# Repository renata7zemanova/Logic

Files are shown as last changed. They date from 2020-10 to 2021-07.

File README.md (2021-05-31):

# Elektronická hra Logic

Elektronická hra Logic je hra, která je založena na principu deskové hry Logic.

## DPS

Deska plošného spoje je nakreslena v programu KiCad. 

## Software

Pro programování DPS Elektronické hry Logic je zapotřebí stáhnout a nainstalovat vývojové prostředí [Visual Studio Code](https://code.visualstudio.com/) a v něm rozšíření PlatformIO. 

Software je napsán pomocí Arduino frameworku.

Při programování musí být přepínač SW15 vždy dole (v pozici 1).

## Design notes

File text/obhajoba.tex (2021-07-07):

% Soubory musí být v kódování, které je nastaveno v příkazu \usepackage[...]{inputenc}

\documentclass[%        Základní nastavení
  %draft,    				  % Testovací překlad
  12pt,       				% Velikost základního písma je 12 bodů
	t,                  % obsah slajdů bude vždy začínat od shora (nebude vertikálně centrovaný)
	aspectratio=1610,   % poměr stran bude 16:10 (všechny projektory v učebnách na Technické 12 Brno),
	                    % další volby jsou 43, 149, 169, 54, 32.
	unicode,						% Záložky a informace budou v kódování unicode
]{beamer}				    	% Dokument třídy 'zpráva', vhodná pro sazbu závěrečných prací s kapitolami
%\usepackage{etex}

\usepackage[utf8]		  % Kódování zdrojových souborů je v UTF-8
	{inputenc}					% Balíček pro nastavení kódování zdrojových souborů
	
\usepackage{graphicx} % Balíček 'graphicx' pro vkládání obrázků
											% Nutné pro vložení logotypů školy a fakulty

\usepackage[          % Balíček 'acronym' pro sazby zkratek a symbolů
	nohyperlinks				% Nebudou tvořeny hypertextové odkazy do seznamu zkratek
]{acronym}						
											% Nutné pro použití prostředí 'acronym' balíčku 'thesis'

%% Balíček hyperref je volán třídou beamer automaticky, proto není třeba následujícího kódu:
%\usepackage[
%	breaklinks=true,		% Hypertextové odkazy mohou obsahovat zalomení řádku
%	hypertexnames=false % Názvy hypertextových odkazů budou tvořeny
%											% nezávisle na názvech TeXu
%]{hyperref}						% Balíček 'hyperref' pro sazbu hypertextových odkazů
%											% Nutné pro použití příkazu 'nastavenipdf' balíčku 'thesis'

\usepackage{cmap} 		% Balíček cmap zajišťuje, že PDF vytvořené `pdflatexem' je
											% plně "prohledávatelné" a "kopírovatelné"

%\usepackage{upgreek}	% Balíček pro sazbu stojatých řeckých písmem
											%% např. stojaté pí: \uppi
											%% např. stojaté mí: \upmu (použitelné třeba v mikrometrech)
											%% pozor, grafická nekompatibilita s fonty typu Computer Modern!

%\usepackage{amsmath} %balíček pro sabu náročnější matematiky

\usepackage{booktabs} % Balíček, který umožňuje v tabulce používat
                      % příkazy \toprule, \midrule, \bottomrule

%%%%%%%%%%%%%%%%%%%%%%%%%%%%%%%%%%%%%%%%%%%%%%%%%%%%%%%%%%%%%%%%%
%%%%%%      Definice informací o dokumentu             %%%%%%%%%%
%%%%%%%%%%%%%%%%%%%%%%%%%%%%%%%%%%%%%%%%%%%%%%%%%%%%%%%%%%%%%%%%%

\input{nastaveni}      % v tomto souboru doplňte údaje o sobě, o názvu práce...
                       % (tento soubor je sdílený s textem práce)

%%%%%%%%%%%%%%%%%%%%%%%%%%%%%%%%%%%%%%%%%%%%%%%%%%%%%%%%%%%%%%%%%%%%%%%%

%%%%%%%%%%%%%%%%%%%%%%%%%%%%%%%%%%%%%%%%%%%%%%%%%%%%%%%%%%%%%%%%%%%%%%%%
%%%%%%     Nastavení polí ve Vlastnostech dokumentu PDF      %%%%%%%%%%%
%%%%%%%%%%%%%%%%%%%%%%%%%%%%%%%%%%%%%%%%%%%%%%%%%%%%%%%%%%%%%%%%%%%%%%%%
%% Při vloženém balíčku 'hyperref' lze použít příkaz '\pdfsettings'
\pdfsettings
%  Nastavení polí je možné provést také ručně příkazem:
%\hypersetup{
%  pdftitle={Název studentské práce},    	% Pole 'Document Title'
%  pdfauthor={Autor studenstké práce},   	% Pole 'Author'
%  pdfsubject={Typ práce}, 						  	% Pole 'Subject'
%  pdfkeywords={Klíčová slova}           	% Pole 'Keywords'
%}
\hypersetup{pdfpagemode=FullScreen}       % otevření rovnou v režimu celé obrazovky
%%%%%%%%%%%%%%%%%%%%%%%%%%%%%%%%%%%%%%%%%%%%%%%%%%%%%%%%%%%%%%%%%%%%%%%

\usetheme{VUT} 				% barvy a rozložení prezentace odpovídající VUT FEKT
% alternativně lze použít jiná berevná témata, ale bez záruky. Například: 
%\usetheme{Darmstadt} \usecolortheme{default2}
\logoheader					% vytvoření zkráceného loga VUT FEKT v hlavičce slajdu, nechte odkomentované

\begin{document}

% v případě zakomentování následujícího se zobrazí v pravém dolním rohu slajdů klikatelné navigační symboly 
\disablenavigationsymbols

% titulní snímek, vysazen bez horních, dolních a postranních lišt (volba plain),
% není tak vysazen ani nadpis snímku
\maketitle

%%%%%%%%%%%%%%%%%%%%%%%%%%%%%%%%%%%%%%%%%%%%%%%%%%%%%%%%%%%%%%%%%%%%%%%
% 1. snímek s cíli (zadaním) práce
\begin{frame} 
	% nadpis snímku
	\frametitle{Cíle práce}
	\vspace{1cm}
	\begin{itemize}
			\item Nastudování pravidel
			\item Návrh
			\item Výroba
			\item Oživení
			\item Software
			\item Ovládání hry
			\item Krabička
	\end{itemize}
\end{frame}

%%%%%%%%%%%%%
\begin{frame} 
	\frametitle{Pravidla}
	\begin{columns}[T] 								% prostředí sloupce s umístěním nahoře
		\begin{column}{0.5\textwidth}		% první sloupec
			\vspace{0.5cm}
			\begin{itemize}
				\item Respektování pravidel deskové hry
				\item Zadání kombinace barev v určitém pořadí
				\item Vyhodnocení
				\begin{itemize}
					\item Správná barva na správné pozici
					\item Správná barva na špatné pozici
				\end{itemize}
				\item 10 pokusů
			\end{itemize}
		\end{column}
		%
		\begin{column}{0.5\textwidth}		% druhý sloupec
			\begin{figure}%	
				\centering
				\vspace{0.5cm}	              % horizontální mezera
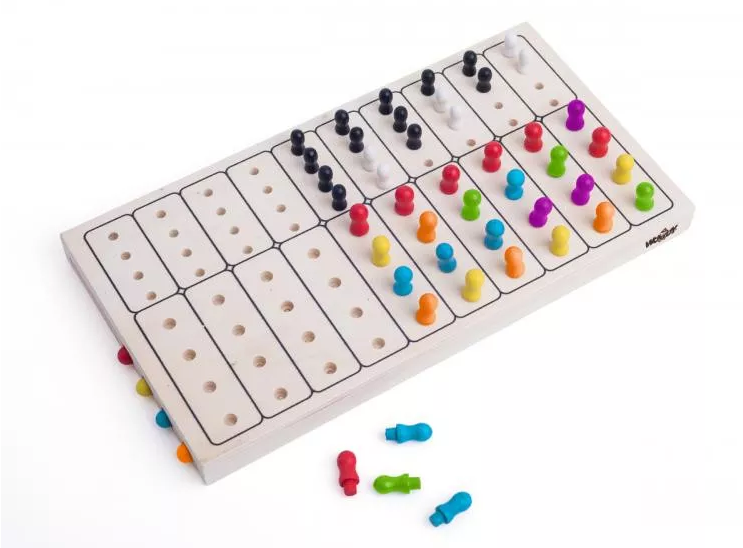
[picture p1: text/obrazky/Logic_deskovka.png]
				
				%lze vložit popisek, ale povetšinou je to v prezentaci zbytečné
				%\caption{Popisek obrázku}%
				%\label{obr:ukazka}
			\end{figure}
		\end{column}
	\end{columns}	
\end{frame} 

	% prostředí 'alertblock', které slouží pro zdůraznění informace
	%\begin{alertblock}{Pro práci je klíčový Eulerův vzorec}
	%	$$\eul^{\jmag x}=\cos x + \jmag\sin x$$
	%\end{alertblock}

	%\vspace{4ex}
	%Eulerova identita je speciálním případem tohoto vzorce, jestliže dosadíme $x=\uppi$\,:

	% prostředí 'block', které slouží jako informativní
	%\begin{block}{Eulerova identita}
	%	$$\eul^{\jmag \uppi}=\cos \uppi + \jmag\sin \uppi,$$\\
	%	odkud vyplývá
	%	$$\eul^{\jmag \uppi}+1=0.$$
	%\end{block}
%%%%%%%%%%%%%
\begin{frame} 
	\frametitle{Návrh elektroniky}
	
	\begin{columns}[T] 								% prostředí sloupce s umístěním nahoře
		\begin{column}{0.45\textwidth}		% první sloupec
			\vspace{0.5cm}
			\begin{itemize}
				\item Přenosné zařízení
				\item Řídicí elektronika
				\item Napájení
				\item Měnič napětí
				\item Převodník z USB na RS-232
				\item Herní prvky
				\item Ovládací prvky
			\end{itemize}
		\end{column}
		%
		\begin{column}{0.55\textwidth}		% druhý sloupec
			\begin{figure}%	
				\centering
				\vspace{1cm}	              % horizontální mezera
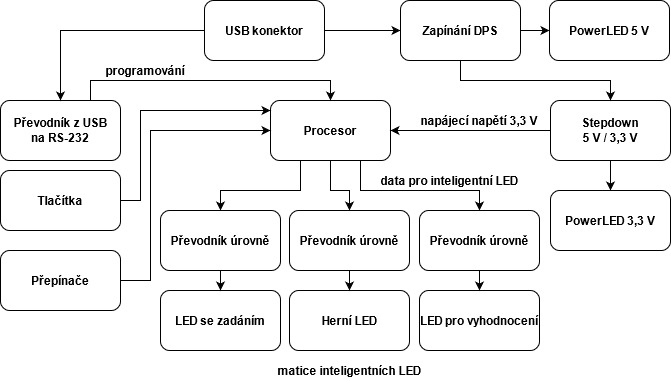
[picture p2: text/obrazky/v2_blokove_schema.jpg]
				
				%lze vložit popisek, ale povetšinou je to v prezentaci zbytečné
				%\caption{Popisek obrázku}%
				%\label{obr:ukazka}
			\end{figure}
		\end{column}
	\end{columns}											% ukončení prostředí sloupce
\end{frame}

\begin{frame} 
	\frametitle{Herní prvky}
	\begin{columns}[T] 								% prostředí sloupce s umístěním nahoře
		\begin{column}{0.4\textwidth}		% první sloupec
			%Obrázek znázorňuje model:\\[2ex]
			\vspace{0.5cm}
			\begin{itemize}
				\item WS2812C
				\item RGB
				\item Napájení
				\item Princip spojení
				\item Komunikace
			\end{itemize}
		\end{column}
		%
		\begin{column}{0.7\textwidth}		% druhý sloupec
			\begin{figure}%	
				\centering
				%\vspace{0.5cm}	              % horizontální mezera
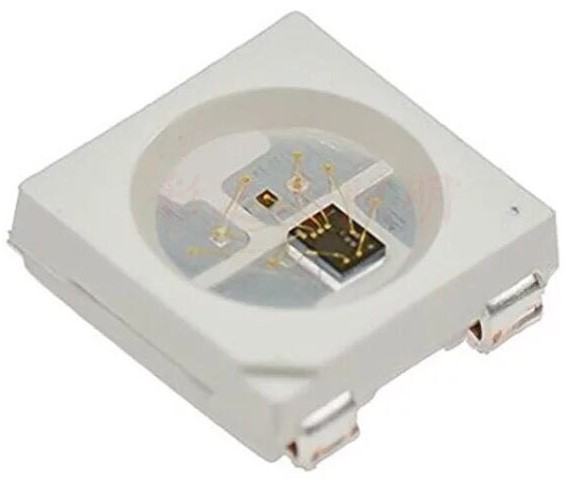
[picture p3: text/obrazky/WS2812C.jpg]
				
				%lze vložit popisek, ale povetšinou je to v prezentaci zbytečné
				%\caption{Popisek obrázku}%
				%\label{obr:ukazka}
			\end{figure}
		\end{column}
	\end{columns}	
	
	\begin{figure}%	
		\centering
		\vspace{0.5cm}	              % horizontální mezera
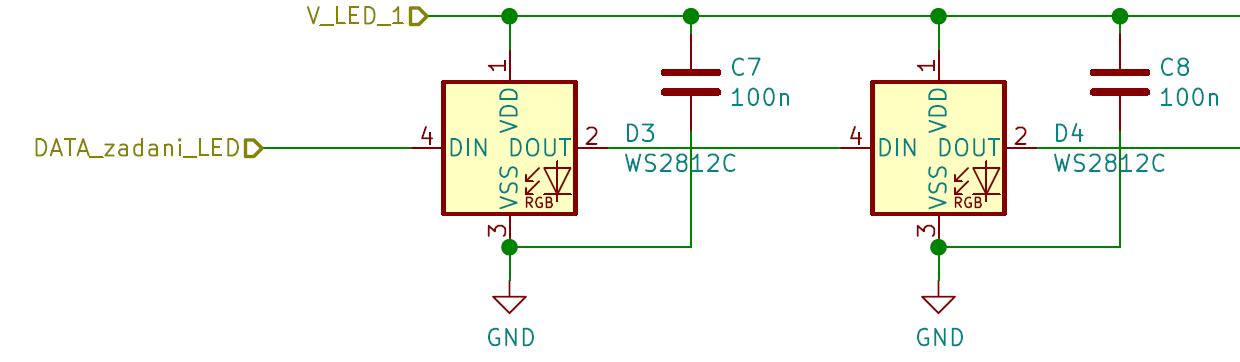
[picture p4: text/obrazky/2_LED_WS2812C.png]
		
	\end{figure}% ukončení prostředí sloupce
\end{frame}

%%%%%%%%%%%%%
\begin{frame} 
	\frametitle{Návrh DPS}
		\begin{columns}[T] 	
		\begin{column}{0.4\textwidth}		% první sloupec
			%Obrázek znázorňuje model:\\[2ex]
			\vspace{0.5cm}
			\begin{itemize}
				\item KiCad
				\item JLCPCB
				\item 4 vrstvy
			\end{itemize}
			\vspace{0.5cm}
			\textbf{Vzhled}
			\begin{itemize}
				\item 10 ~$\times$ 10 cm
				\item 3 části inteligentních LED
				\item USB konektory
				\item Tlačítka
				\item Přepínače
			\end{itemize}
		\end{column}

		\begin{column}{0.6\textwidth}		% druhý sloupec
			\begin{figure}%	
				\centering
				%\vspace{0.5cm}	              % horizontální mezera
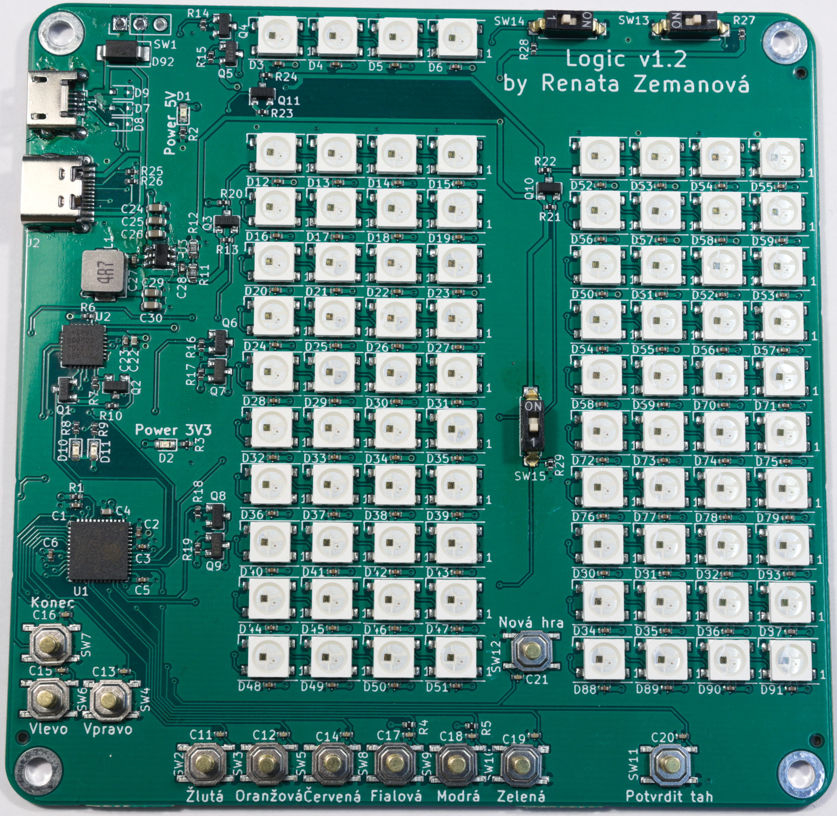
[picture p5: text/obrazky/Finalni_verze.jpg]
				
			\end{figure}% ukončení prostředí sloupce
		\end{column}
	\end{columns}
\end{frame}

	%\begin{table}[]
	%	\centering
	%	\caption{Výsledky měření mobilních sítí}
		%\label{tab:tabulka}
		%	\begin{tabular}{lcc}
		%		\toprule
		%			Technologie  & Rychlost stahování [kB/s] & Rychlost nahrávání [kB/s] \\
		%		\midrule
		%			GPRS (2,5G)	& 7,2 	& 3,6\\
		%			UMTS 3G     & 48 		& 48\\
		%			HSPA (3,5G)	&	1\,706	&	720\\
		%			LTE (4G) 		& 40\,750 & 10\,750\\
		%		\bottomrule                                       
		%	\end{tabular}
	%\end{table}

\begin{frame} 
	\frametitle{Software}
	%\begin{columns}[T] 	
		%\begin{column}{0.4\textwidth}		% druhý sloupec
			\vspace{0.5cm}
			\begin{itemize}
				\item C++ 
				\item Arduino framework
				\item Funkce jednotlivých tlačítek
			\end{itemize}
		%\end{column}
		%\begin{column}{0.6\textwidth}		% druhý sloupec
			\begin{figure}%	
				\centering
				\vspace{0.3cm}	              % horizontální mezera
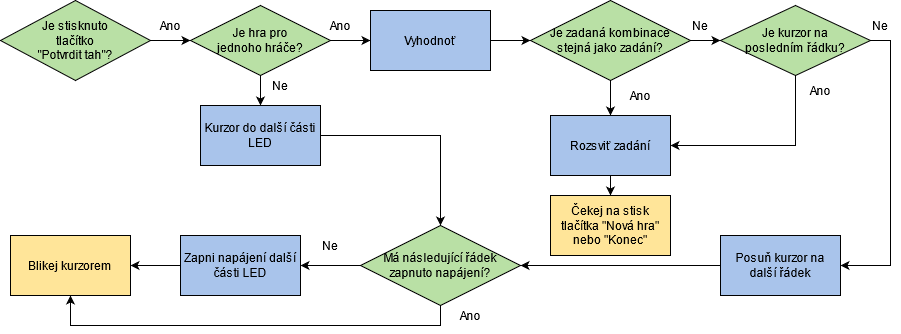
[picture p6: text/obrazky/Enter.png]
				
			\end{figure}% ukončení prostředí sloupce
		%\end{column}
%	\end{columns}
	
\end{frame}

\begin{frame} 
	\frametitle{Způsob hry pro jednoho hráče}
	\begin{figure}%	
		\centering
		%\vspace{0.5cm}	              % horizontální mezera
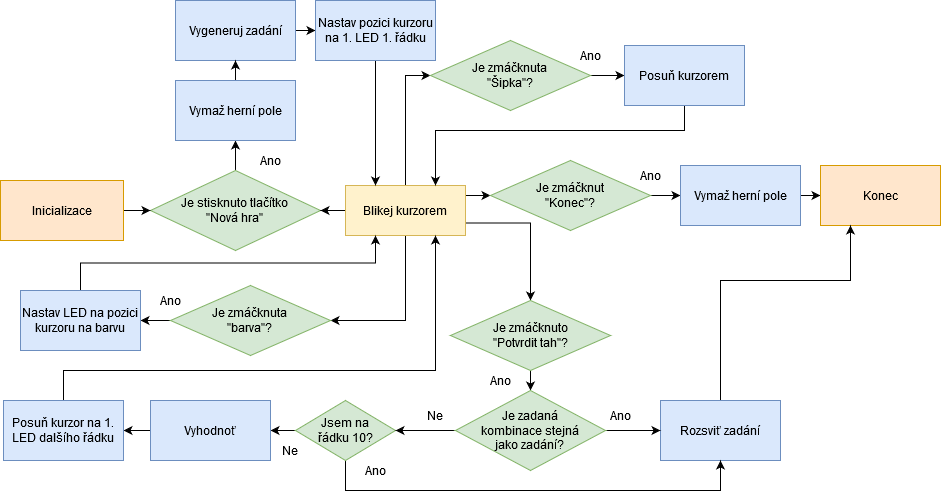
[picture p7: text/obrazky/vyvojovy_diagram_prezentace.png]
		
	\end{figure}% ukončení prostředí sloupce
	%\begin{table}[]
	%	\centering
	%	\caption{Výsledky měření mobilních sítí}
	%	\label{tab:tabulka}
	%		\begin{tabular}{lcc}
	%			\toprule
	%				Technologie  & Rychlost stahování [kB/s] & Rychlost nahrávání [kB/s] \\
	%			\midrule
	%				GPRS (2,5G)	& 7,2 	& 3,6\\
	%				UMTS 3G     & 48 		& 48\\
	%				HSPA (3,5G)	&	1\,706	&	720\\
	%				LTE (4G) 		& 40\,750 & 10\,750\\
	%			\bottomrule                                       
	%		\end{tabular}
	%\end{table}
\end{frame}

\begin{frame} 
	\frametitle{Krabička}
	\begin{columns}[T] 								% prostředí sloupce s umístěním nahoře
		\begin{column}{0.4\textwidth}		% první sloupec
			\vspace{0.5cm}
			\begin{itemize}
				\item SLA 3D tisk
				\item 2 díly a stříška
				\item Text na vrchním dílu
				\item Barvy
			\end{itemize}
		\end{column}
		%
		\begin{column}{0.6\textwidth}		% druhý sloupec
			\begin{figure}%	
				\centering
				%\vspace{0.1cm}	              % horizontální mezera
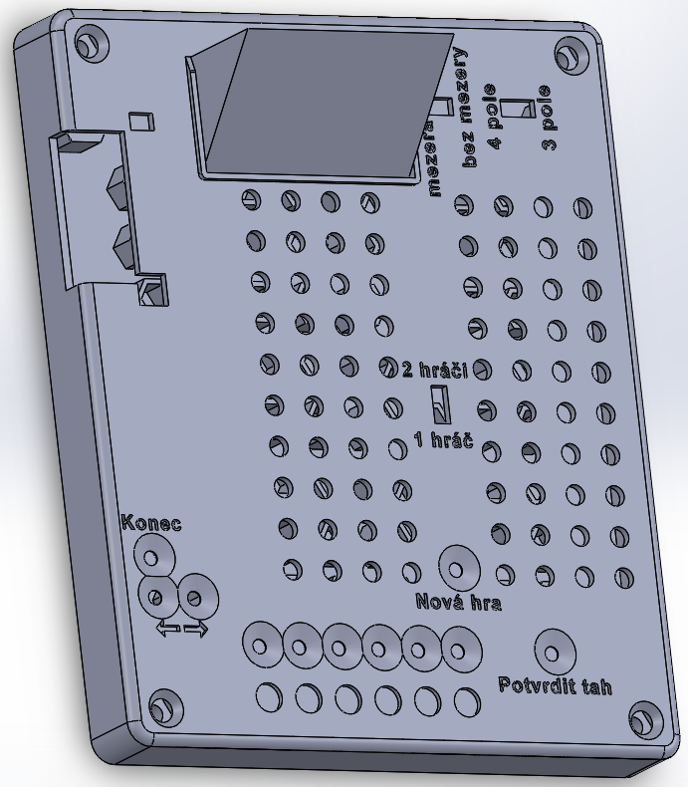
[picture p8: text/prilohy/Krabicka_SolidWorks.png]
				
				%lze vložit popisek, ale povetšinou je to v prezentaci zbytečné
				%\caption{Popisek obrázku}%
				%\label{obr:ukazka}
			\end{figure}
		\end{column}
	\end{columns}	
\end{frame}

%%%%%%%%%%%%%
\begin{frame} 
	\frametitle{Závěr}
	\begin{columns}[T] % prostředí sloupce s umístěním nahoře								
		\begin{column}{0.3\textwidth}		% první sloupec
			\vspace{0.5cm}
			\begin{itemize}
				\item Pravidla
				\item Návrh
				\item Oživení
				\item Software
				\item Ovládání hry
				\item Krabička
			\end{itemize}
		\end{column}
		%
		\begin{column}{0.7\textwidth}		% druhý sloupec
			\begin{figure}%	
				\centering
				%\vspace{0.1cm}	              % horizontální mezera
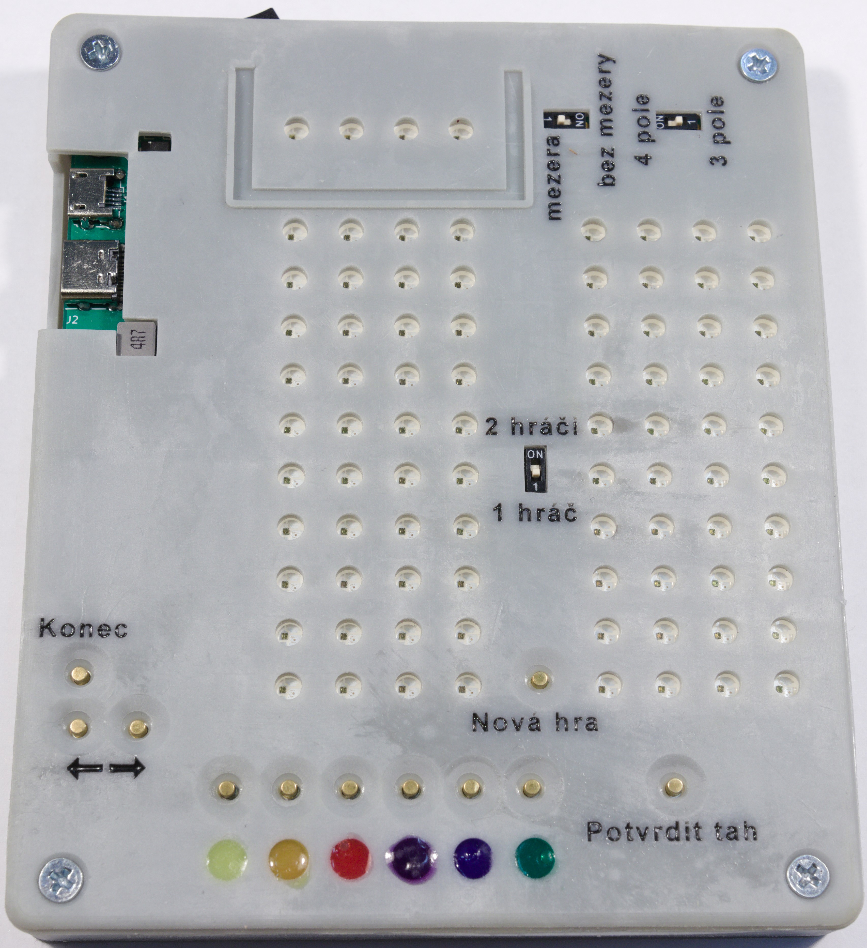
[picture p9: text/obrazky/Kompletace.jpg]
				
				%lze vložit popisek, ale povetšinou je to v prezentaci zbytečné
				%\caption{Popisek obrázku}%
				%\label{obr:ukazka}
			\end{figure}
		\end{column}
	\end{columns}	
\end{frame}

\begin{frame} 
	\frametitle{\mbox{ }}
	\begin{columns}[T] % prostředí sloupce s umístěním nahoře								
		\begin{column}{0.3\textwidth}		% první sloupec
			\vspace{0.7cm}
			\centering
			{\Huge Děkuji za pozornost!}
			\vspace{0.7cm}
			\begin{itemize}
				\item Pravidla
				\item Návrh
				\item Oživení
				\item Software
				\item Ovládání hry
				\item Krabička
			\end{itemize}
		\end{column}
		%
		\begin{column}{0.7\textwidth}		% druhý sloupec
			\begin{figure}%	
				\centering
				%\vspace{0.1cm}	              % horizontální mezera
				
				%lze vložit popisek, ale povetšinou je to v prezentaci zbytečné
				%\caption{Popisek obrázku}%
				%\label{obr:ukazka}
			\end{figure}
		\end{column}
	\end{columns}	
\end{frame}

\begin{frame} 
	\frametitle{Otázka od oponenta}
	
	{\bf V práci píšete, že používáte pro komunikaci s MCU převodník USB na 
	sběrnici RS-232, prosím o vysvětlení rozdílu mezi sběrnicí RS-232 a UART? }
	
	\begin{itemize}
		\item {\bf RS-232} je standard definující úroveň fyzického signálu.
		Odkazuje na elektroniku a hardware potřebný pro sériovou komunikaci. 

		\item {\bf UART} je komunikační protokol. Je spojený s logikou a
		programováním, ale nemá nic společného s elektronikou jako takovou. 
	\end{itemize}	
\end{frame}

% otázky oponenta
%\frame{
%\frametitle{Otázky oponenta}
%	\emph{Jaká je souvislost Vašeho vzorce (1.2) s~Maxwellovými rovnicemi v~integrálním tvaru?}\\[2ex]
	%
%	Již staří Římané\,\dots
%}

\end{document}

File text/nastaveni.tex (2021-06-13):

% V tomto souboru se nastavují téměř veškeré informace, proměnné mezi studenty:
% jméno, název práce, pohlaví atd.
% Tento soubor je SDÍLENÝ mezi textem práce a prezentací k obhajobě -- netřeba něco nastavovat na dvou místech.

\usepackage[
%%% Z následujících voleb jazyka lze použít pouze jednu
  czech-english,		% originální jazyk je čeština, překlad je anglicky (výchozí)
  %english-czech,	% originální jazyk je angličtina, překlad je česky
  %slovak-english,	% originální jazyk je slovenština, překlad je anglicky
  %english-slovak,	% originální jazyk je angličtina, překlad je slovensky
%
%%% Z následujících voleb typu práce lze použít pouze jednu
  %semestral,		  % semestrální práce (nesází se abstrakty, prohlášení, poděkování) (výchozí)
  bachelor,			%	bakalářská práce
  %master,			  % diplomová práce
  %treatise,			% pojednání o dizertační práci
  %doctoral,			% dizertační práce
%
%%% Z následujících voleb zarovnání objektů lze použít pouze jednu
%  left,				  % rovnice a popisky plovoucích objektů budou zarovnány vlevo
	center,			    % rovnice a popisky plovoucích objektů budou zarovnány na střed (vychozi)
%
]{thesis}   % Balíček pro sazbu studentských prací

%%% Jméno a příjmení autora ve tvaru
%  [tituly před jménem]{Křestní}{Příjmení}[tituly za jménem]
% Pokud osoba nemá titul před/za jménem, smažte celý řetězec '[...]'
\author{Renata}{Zemanová}

%%% Identifikační číslo autora (VUT ID)
\butid{211251}

%%% Pohlaví autora/autorky
% (nepoužije se ve variantě english-czech ani english-slovak)
% Číselná hodnota: 1...žena, 0...muž
\gender{1}

%%% Jméno a příjmení vedoucího/školitele včetně titulů
%  [tituly před jménem]{Křestní}{Příjmení}[tituly za jménem]
% Pokud osoba nemá titul před/za jménem, smažte celý řetězec '[...]'
\advisor[doc.\ Ing.]{Jiří}{Háze}[Ph.D.]

%%% Jméno a příjmení oponenta včetně titulů
%  [tituly před jménem]{Křestní}{Příjmení}[tituly za jménem]
% Pokud osoba nemá titul před/za jménem, smažte celý řetězec '[...]'
% Nastavení oponenta se uplatní pouze v prezentaci k obhajobě;
% v případě, že nechcete, aby se na titulním snímku prezentace zobrazoval oponent, pouze příkaz zakomentujte;
% u obhajoby semestrální práce se oponent nezobrazuje (jelikož neexistuje)
\opponent[doc.\ Ing.]{Pavel}{Šteffan}[Ph.D.]

%%% Název práce
%  Parametr ve složených závorkách {} je název v originálním jazyce,
%  parametr v hranatých závorkách [] je překlad (podle toho jaký je originální jazyk)
\title[Electronic game Logic]{Elektronická hra Logic}

%%% Označení oboru studia
%  Parametr ve složených závorkách {} je název oboru v originálním jazyce,
%  parametr v hranatých závorkách [] je překlad
\specialization[Microelectronics and technology]{Mikroelektronika a technologie}

%%% Označení ústavu
%  Parametr ve složených závorkách {} je název ústavu v originálním jazyce,
%  parametr v hranatých závorkách [] je překlad
%\department[Department of Control and Instrumentation]{Ústav automatizace a měřicí techniky}
%\department[Department of Biomedical Engineering]{Ústav biomedicínského inženýrství}
%\department[Department of Electrical Power Engineering]{Ústav elektroenergetiky}
%\department[Department of Electrical and Electronic Technology]{Ústav elektrotechnologie}
%\department[Department of Physics]{Ústav fyziky}
%\department[Department of Foreign Languages]{Ústav jazyků}
%\department[Department of Mathematics]{Ústav matematiky}
\department[Department of Microelectronics]{Ústav mikroelektroniky}
%\department[Department of Radio Electronics]{Ústav radioelektroniky}
%\department[Department of Theoretical and Experimental Electrical Engineering]{Ústav teoretické a experimentální elektrotechniky}
%\department[Department of Telecommunications]{Ústav telekomunikací}
%\department[Department of Power Electrical and Electronic Engineering]{Ústav výkonové elektrotechniky a elektroniky}

%%% Označení fakulty
%  Parametr ve složených závorkách {} je název fakulty v originálním jazyce,
%  parametr v hranatých závorkách [] je překlad
%\faculty[Faculty of Architecture]{Fakulta architektury}
\faculty[Faculty of Electrical Engineering and~Communication]{Fakulta elektrotechniky a~komunikačních technologií}
%\faculty[Faculty of Chemistry]{Fakulta chemická}
%\faculty[Faculty of Information Technology]{Fakulta informačních technologií}
%\faculty[Faculty of Business and Management]{Fakulta podnikatelská}
%\faculty[Faculty of Civil Engineering]{Fakulta stavební}
%\faculty[Faculty of Mechanical Engineering]{Fakulta strojního inženýrství}
%\faculty[Faculty of Fine Arts]{Fakulta výtvarných umění}
%
%Nastavení logotypu (v hranatych zavorkach zkracene logo, ve slozenych plne):
\facultylogo[logo/FEKT_zkratka_barevne_PANTONE_CZ]{logo/UMEL_color_PANTONE_CZ}

%%% Rok odevzdání práce
\graduateyear{2021}
%%% Akademický rok odevzdání práce
\academicyear{2020/21}

%%% Datum obhajoby (uplatní se pouze v prezentaci k obhajobě)
\date{15.\,06.\,2021} 

%%% Místo obhajoby
% Na titulních stránkách bude automaticky vysázeno VELKÝMI písmeny (pokud tyto stránky sází šablona)
\city{Brno}

%%% Abstrakt
\abstract[%
The goal of this bachelor thesis is to design and manufacture an Electronic game Logic. This electronic game should look like the board game and also 
respect the game's rules.

The electronic game is designed as one PCB that contains control electronics and play units. The functional PCB containing all electronics was 
manufactured.  The game was programmed, and the final version was placed in a designed case. 

The Electronic game Logic also allows the player to set game mode options. 
]{%
Cílem práce je navrhnout a~vyrobit Elektronickou hru Logic. Elektronická hra musí respektovat pravidla deskové hry. Dále by se hra měla i~svým vzhledem
podobat deskové hře.

Elektronická hra je navržena jako jedna DPS, která obsahuje řídicí elektroniku i~herní prvky. Byla vyrobena funkční DPS obsahující veškerou elektroniku.
Dále byla hra naprogramována a~byla k~ní navržena a~vyrobena krabička.

Elektronická hra Logic umožňuje hráči nastavení možností způsobu hry. 
}

%%% Klíčová slova
\keywrds[%
Electronic game Logic, board game rules, ESP32-PICO, intelligent control LED WS2812C, USB, PCB, Arduino framework, C++
]{
Elektronická hra Logic, pravidla deskové hry, ESP32-PICO, inteligentní LED WS2812C, USB, DPS, Arduino framework, C++
}

%%% Poděkování
\acknowledgement{%
Ráda bych poděkovala vedoucímu bakalářské práce panu doc.~Ing.~Jiřímu Házemu, Ph.D.\ za odborné vedení, konzultace, trpělivost a~podnětné návrhy 
k~práci.

Dále bych ráda poděkovala RNDr.~Janu Mrázkovi a~Ing.~Jakubovi Streitovi za odborné konzultace, odpovědi na mé všetečné dotazy a~nepřeberné množství 
trpělivosti. RNDr.~Janu Mrázkovi bych také ráda poděkovala za poskytnutí SLA tisku krabičky. 

Děkuji také Vojtěchu Bočkovi za pořízení profesionálních fotografií výrobku, které jsou součástí této práce. 
}%

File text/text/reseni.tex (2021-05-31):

\chapter{Pravidla deskové hry}
Logic je desková hra pro dva hráče \cite{Logic_pravidla}. Jeden hráč určí hledanou kombinaci, dále bude označován jako 
hráč~A, a~druhý tuto kombinaci za pomoci logických úvah a~vyhodnocení hráčem~A~hledá, dále bude označován jako hráč~B.

Hráči si určí herní pozice. Hráč~A~vybere barevné kolíky dle libosti a~následně je v~určitém pořadí vloží do zadávacího pole. Zadání zakryje
stříškou, aby tuto
kombinaci spoluhráč neviděl. Hráč~B~se po tuto dobu nedívá. Hráč~B~následně zvolí libovolnou kombinaci barev a~jejich pozic. Po 
ukončení tahu nechá
hráče~A,~aby jeho tah vyhodnotil. Hráč~A~vyhodnotí tah následujícím způsobem. Pokud hráč~B~vložil správnou barvu na správnou pozici, tak vloží 
do vyhodnocovací sekce černý kolík. Pokud vložil barvu, která se v~zadání vyskytuje, ale vložil ji na nesprávnou pozici, tak vloží bílý kolík.
Pokud zůstanou některé pozice neobsazené, tak to znamená, že se dané barvy v~zadání nevyskytují. 
Vyhodnocovací kolíky umisťuje od kraje, nejprve černé a~pak bílé, aby hráči~B~nebylo jasné, kterých hracích kolíků se vyhodnocení 
týká \cite{Logic_pravidla}.
Poté začne hráč~B~na základě vyhodnocení a~svých všech předchozích tahů hledat správnou kombinaci.

Hráč~B~má maximálně 10~pokusů na zjištění správné kombinace. Po skončení hry hráč~A~odkryje stříšku a~ukáže hledanou kombinaci, aby mohlo dojít
k~případné kontrole. Hra skončí po určení správné kombinace, nebo po vypotřebování všech pokusů.

Hru lze hrát ve více variantách. Hráči se mohou domluvit, zda zadání může, nebo nesmí obsahovat volnou pozici. Dále se může hra lišit v~délce hledané 
kombinace.

\begin{figure}[!h]
  \begin{center}
    
  \end{center}
  \caption[Desková hra Logic \cite{Logic_deskovka}]{Desková hra Logic \cite{Logic_deskovka}.}
\end{figure}

\chapter{Návrh elektroniky}
V~následující kapitole budou rozebrány všechny komponenty DPS Elektronické hry Logic. Návrh se skládá z~řídicí elektroniky, 
napájení, herních prvků a~dalších potřebných komponent.

\begin{figure}[!h]
  \begin{center}
    
  \end{center}
  \caption[Blokové schéma elektroniky]{Blokové schéma elektroniky.}
\end{figure}    

\section{Řídicí elektronika} \label{Ridici_elektronika}
Jako řídicí elektronika byl vybrán mikrokontrolér ESP32-PICO-D4. Hlavním důvodem pro výběr tohoto mikrokontroléru bylo, že je téměř totožný 
jako ESP32-WROOM, se 
kterým mám dlouhodobé zkušenosti. Tento mikrokontrolér má veškeré periferie, které jsou pro výrobu této hry zapotřebí. 

Mikrokontrolér ESP32-PICO také podporuje Arduino framework, díky kterému bylo programování značně zjednodušeno.

Mikrokontrolér ESP32-PICO obsahuje \cite{PICO_datasheet}: 
\begin{itemize}
    \item modul WiFi,
    \item modul Bluetooth, 
    \item 32~GPIO pinů, 
    \item dvoujádrový 32bitový procesor Xtensa LX6,
    \item 520~kB~SRAM, 
    \item 4~MB~FLASH. 
  \end{itemize}

  Napájecí napětí tohoto mikrokontroléru je 3,0--3,6~V~a průměrný odběr proudu je 80~mA \cite{PICO_datasheet}. Mikrokontrolér ESP32-PICO má 
  vyvedeno 32~GPIO pinů, které je 
  možno softwarově nastavit jako vstupní nebo výstupní. Na tyto piny lze poté připojit různá zařízení. Vstupním senzorem může 
  být typicky tlačítko a~výstupním indikátorem např.~LED. Tato zařízení zprostředkovávají komunikaci mezi mikrokontrolérem a~okolním 
  světem.

  \begin{figure}[!h]
    \begin{center}
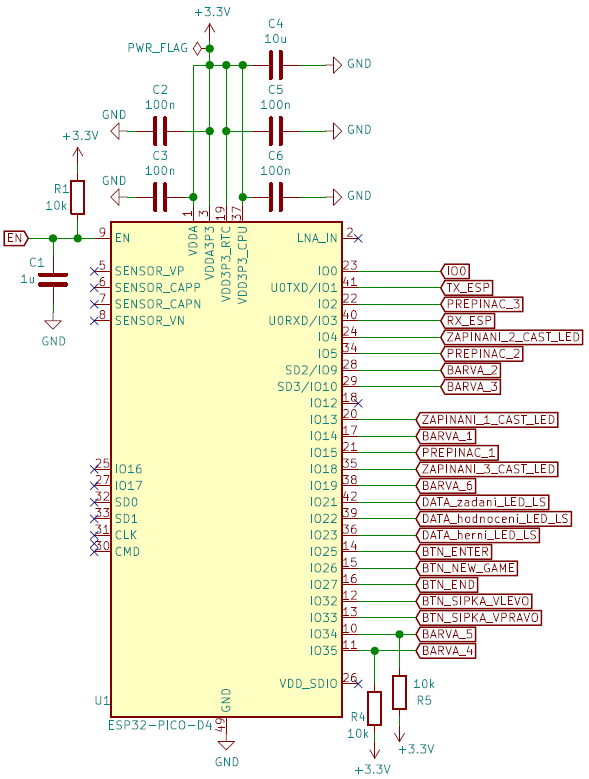
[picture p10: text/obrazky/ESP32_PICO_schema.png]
      
    \end{center}
    \caption[Schéma zapojení mikrokontroléru ESP32-PICO \cite{PICO_datasheet}]{Schéma zapojení mikrokontroléru ESP32-PICO \cite{PICO_datasheet}.}
  \end{figure}

  Vstupně-výstupní piny IO16 a~IO17 nemohou být použity, protože ESP32-PICO má na těchto pinech připojenou flash paměť \cite{PICO_datasheet}.
  Pokud by na tento pin bylo připojeno nějaké zařízení, tak by mikrokontrolér ztratil přístup ke své paměti.

  Vstupně-výstupní piny IO02, IO05, IO12 a~IO15 slouží jako konfigurační piny při spouštění nebo resetu mikrokontroléru ESP32-PICO. Slouží například k~výběru
  paměti, ze které se program mikrokontroléru ESP32-PICO načítá. Při resetu musí být tyto piny ve správné konfiguraci. Pin MTDI je GPIO12 a~pin MTDO je pin 
  GPIO15 \cite{PICO_datasheet}.

  \begin{table}[!h]
    \caption{Konfigurační piny \cite{PICO_datasheet}.}
    \begin{center}
      \begin{tabular}{|c|c|c|c|c|c|}
      \hline
      \rowcolor[HTML]{9B9B9B} 
      \multicolumn{6}{|c|}{\cellcolor[HTML]{9B9B9B}{\color[HTML]{000000} Napětí interního LDO (VDD\_SDIO)}} \\ 
      \hline
      \rowcolor[HTML]{C0C0C0} 
      Pin & Výchozí & \multicolumn{2}{c|}{\cellcolor[HTML]{C0C0C0}3.3~V} & \multicolumn{2}{c|}{\cellcolor[HTML]{C0C0C0}1.8~V} \\ 
      \hline
      MTDI & Pulldown  & \multicolumn{2}{c|}{0}   & \multicolumn{2}{c|}{1}  \\ 
      \hline
      \rowcolor[HTML]{9B9B9B} 
      \multicolumn{6}{|c|}{\cellcolor[HTML]{9B9B9B}{\color[HTML]{000000} Startovací sekvence}}  \\ 
      \hline
      \rowcolor[HTML]{C0C0C0} 
      Pin  & Výchozí & \multicolumn{2}{c|}{\cellcolor[HTML]{C0C0C0}Načtení programu z SPI}   & \multicolumn{2}{c|}{\cellcolor[HTML]{C0C0C0}Načtení programu z interní paměti} \\ 
      \hline
      GPIO0  & Pullup  & \multicolumn{2}{c|}{1} & \multicolumn{2}{c|}{0} \\ 
      \hline
      GPIO2  & Pulldown & \multicolumn{2}{c|}{Nezáleží}  & \multicolumn{2}{c|}{0}  \\ 
      \hline
      \rowcolor[HTML]{9B9B9B} 
      \multicolumn{6}{|c|}{\cellcolor[HTML]{9B9B9B}Povolení/Zakázání zobrazení ladicího protokolu U0TXD v průběhu načítání} \\ 
      \hline
      \rowcolor[HTML]{C0C0C0} 
      Pin  & Výchozí  & \multicolumn{2}{c|}{\cellcolor[HTML]{C0C0C0}U0TXD aktivní} & \multicolumn{2}{c|}{\cellcolor[HTML]{C0C0C0}U0TXD neaktivní} \\ 
      \hline
      MTDO & Pullup & \multicolumn{2}{c|}{1}  & \multicolumn{2}{c|}{0} \\ 
      \hline
      \rowcolor[HTML]{9B9B9B} 
      \multicolumn{6}{|c|}{\cellcolor[HTML]{9B9B9B}Časování SDIO periferního zařízení} \\ 
      \hline
      \rowcolor[HTML]{C0C0C0} 
      {\color[HTML]{000000} Pin} & {\color[HTML]{000000} Výchozí} & {\color[HTML]{000000} \begin{tabular}[c]{@{}c@{}} $\downarrow$ vzorkování\\ $\downarrow$ výstup\end{tabular}} & {\color[HTML]{000000} \begin{tabular}[c]{@{}c@{}} $\downarrow$ vzorkování\\ $\uparrow$ výstup\end{tabular}} & {\color[HTML]{000000} \begin{tabular}[c]{@{}c@{}} $\uparrow$ vzorkování\\ $\downarrow$ výstup\end{tabular}} & {\color[HTML]{000000} \begin{tabular}[c]{@{}c@{}} $\uparrow$ vzorkování\\ $\uparrow$ výstup\end{tabular}} \\ 
      \hline
      MTDO  & Pullup  & 0    & 0   & 1  & 1 \\ 
      \hline
      GPIO5  & Pullup  & 0  & 1 & 0  & 1 \\ 
      \hline
      \end{tabular}  
    \end{center}
  \end{table}  

  Vstupně-výstupní piny IO34 a~vyšší jsou pouze vstupní \cite{PICO_datasheet}. Vstupní piny nemají softwarově zapojitelný pullup rezistor. 
  Pokud je tedy zapotřebí pullup rezistor, musí se fyzicky zapojit.
  
  \section{Napájení}
  Napájení probíhá přes USB konektor. V~dnešní době jsou 2~nejpoužívanější konektory – USB Micro a USB-C. Proto byly použity oba USB konektory. 
  Deska plošného spoje nepodporuje funkci Quick Charge ani Power Delivery. Může být napájena pouze napětím 5~V. Přítomnost jiného napětí není žádoucí. 
  Konektor USB-C je tedy funkčně zapojen totožně jako USB~Micro a~oba konektory jsou na DPS pouze kvůli jejich tvarům. 
  
  \begin{figure}[!h]
    \begin{center}
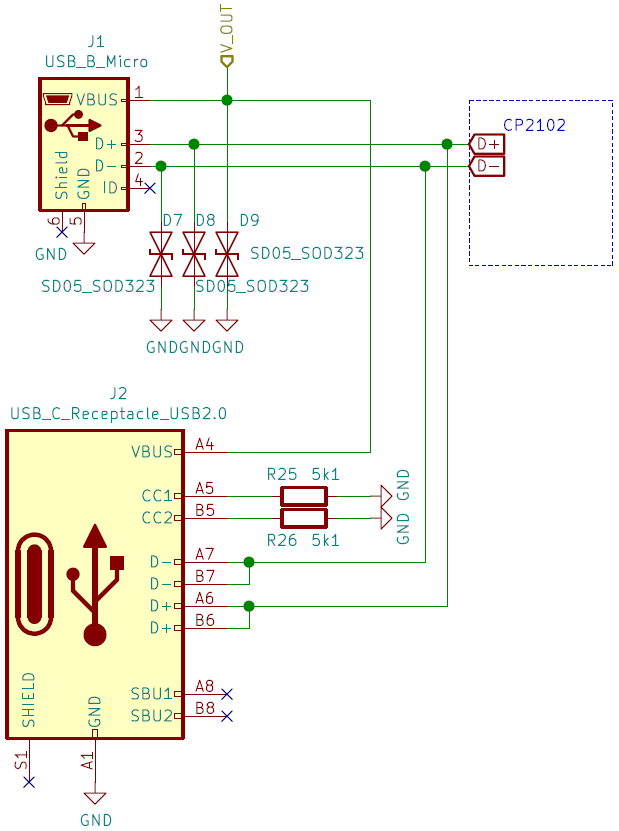
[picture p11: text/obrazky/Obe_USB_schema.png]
      
    \end{center}
    \caption[Schéma zapojení USB konektorů \cite{USB-C}]{Schéma zapojení USB konektorů \cite{USB-C}.}
  \end{figure}

  \section{Snižující měnič napájecího napětí}
  Mikrokontrolér ESP32-PICO má napájecí napětí 3,3~V. Napětí z~powerbanky přes USB je 5~V. Proto je tedy zapotřebí zapojit 
  měnič pro snížení napětí, který bude vytvářet z~napájecího napětí 5~V~napájecí napětí 3,3~V~pro mikrokontrolér ESP32-PICO.

  Jako měnič byl zvolen čip SY8105. Tento čip byl vybrán podle projektu RB0005-UniversalStepDown \cite{UniversalStepDown}. 
  V~tomto projektu zapojení funguje bezproblémově, a~proto bylo rozhodnuto toto zapojení použít v~této práci. 

  Čip SY8105 má napájecí napětí 4,5--18~V~a jeho maximální výstupní proud může dosahovat až 5~A.

  Výstupní napětí zapojení čipu SY8105 je závislé na poměru rezistorů R11~a~R12 \cite{SY8105_datasheet}. 
  Hodnota rezistoru R11 byla zvolena 160~k$\Omega$. Hodnota rezistoru R12 byla dopočítána dle:

  \begin{equation} 
    R_{12}~=~\frac{0,6}{U_{OUT}-0,6}~\cdot~R_{11}~=~\frac{0,6}{3,3-0,6}~\cdot~160\cdot10^3~=~35,555~\:k\Omega. 
    \quad \quad \quad \cite{SY8105_datasheet}
  \label{eq:R12}
  \end{equation}

  Hodnota rezistoru R12 byla zvolena nejbližší z~vyráběné rezistorové řady E24, tudíž 36~k$\Omega$ \cite{Rezistorova_rada}. Hodnota 
  rezistoru se musí co nejvíce blížit vypočítané hodnotě, aby výstupní napětí nebylo příliš odlišné od požadovaného. Proto nebyl
  zvolen rezistor z~častěji používaných řad E6 ani E12. Hodnota rezistoru z~těchto řad by se již příliš odchylovala od vypočítané.

  \begin{figure}[!h]
    \begin{center}
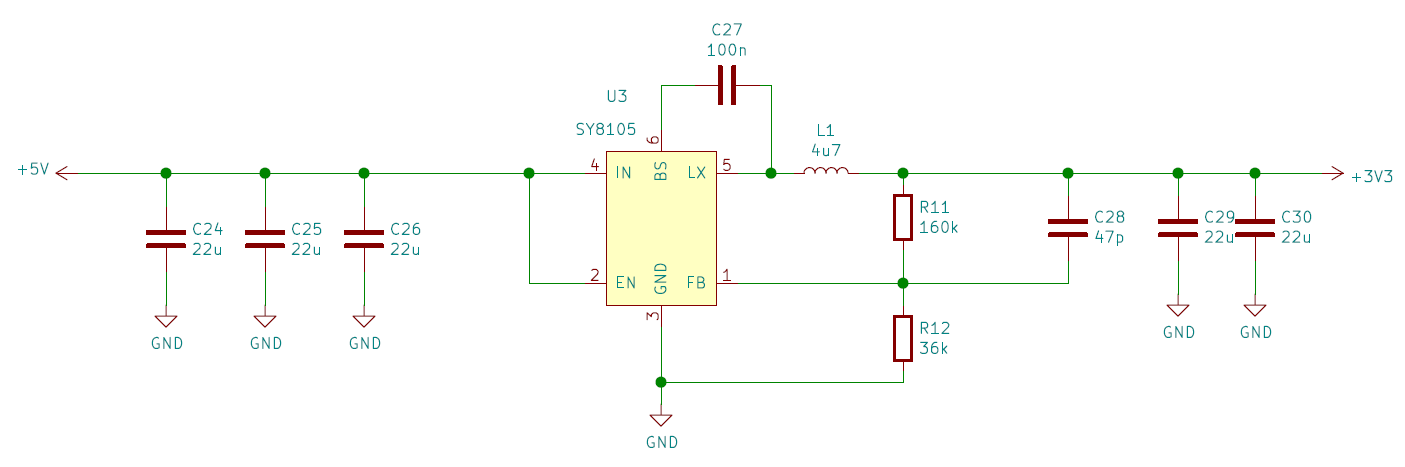
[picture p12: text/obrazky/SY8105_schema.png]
      
    \end{center}
    \caption[Schéma zapojení čipu SY8105 \cite{SY8105_datasheet}]{Schéma zapojení čipu SY8105 \cite{SY8105_datasheet}.}
  \end{figure}

  \section{Převodník z~USB na RS-232}
  Mikrokontrolér ESP32-PICO používá jako komunikační rozhraní linku RS-232. Programování ale probíhá přes USB konektor, který toto rozhraní
  nemá. Proto bylo potřeba použít převodník z~USB na rozhraní RS-232.
  
  \begin{figure}[!h]
    \begin{center}
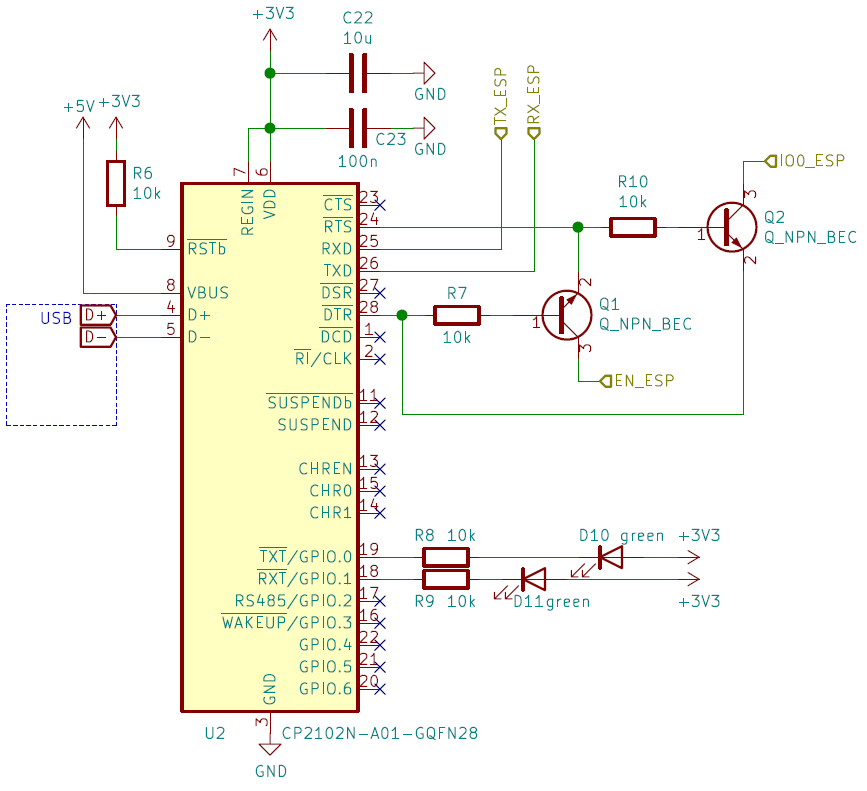
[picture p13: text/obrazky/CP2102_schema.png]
      
    \end{center}
    \caption[Schéma zapojení převodníku z~USB na RS-232 \cite{Devkit_schema}]{Schéma zapojení převodníku z~USB na RS-232 \cite{Devkit_schema}.}
  \end{figure}

  Velkou inspirací při výběru součástek byl kit ESP32-DEVKITC \cite{Devkit_schema}. Tento kit obsahuje ESP32-WROOM a~také převodník
  z~USB na RS-232. Na tomto kitu je převodník realizován čipem CP2102. Mikrokontrolér ESP32-WROOM a~ESP32-PICO se liší pouze v~drobnostech, 
  proto byl převodník CP2102 použit i~při návrhu převodníku u~Elektronické hry Logic.  Tento čip zároveň převádí logiku 
  z~0--5~V~na logiku 0--3,3~V~\cite{CP2102_datasheet}. 

 Čip CP2102 má napájecí napětí 3--3,6~V a~jeho typickým proudovým odběrem je 9,5~mA.

  Čip CP2102 dokáže komunikovat velkým množstvím komunikačních rychlostí (300, 9600, 19200, 38400, 115200, 256000~Bd, atd) 
  \cite{CP2102_datasheet}. Komunikační rychlost se nastavuje během konfigurace COM portu v~počítači \cite{CP2102_datasheet}.

  Z~USB jsou signály D+~a~D- připojeny k~čipu CP2102. Tento čip signál z~USB převede na signály RX~a~TX, které mají výstup 
  na pinech RXD~a~TXD. Následně jsou tyto signály připojeny k~mikrokontroléru ESP32-PICO. Signály RX~a~TX musí být překříženy. To znamená, že RX CP2102
  je připojeno na TX ESP32-PICO a~TX CP2102 je připojeno na RX ESP32-PICO. 

  Elektroluminiscenční diody~D10~a~D11 slouží k~indikaci komunikace s~mikrokontrolérem ESP32-PICO. Pokud je do mikrokontroléru nahráván program, tak LED~D10~a~D11 
  blikají.

  \begin{figure}[!h]
      \begin{center}
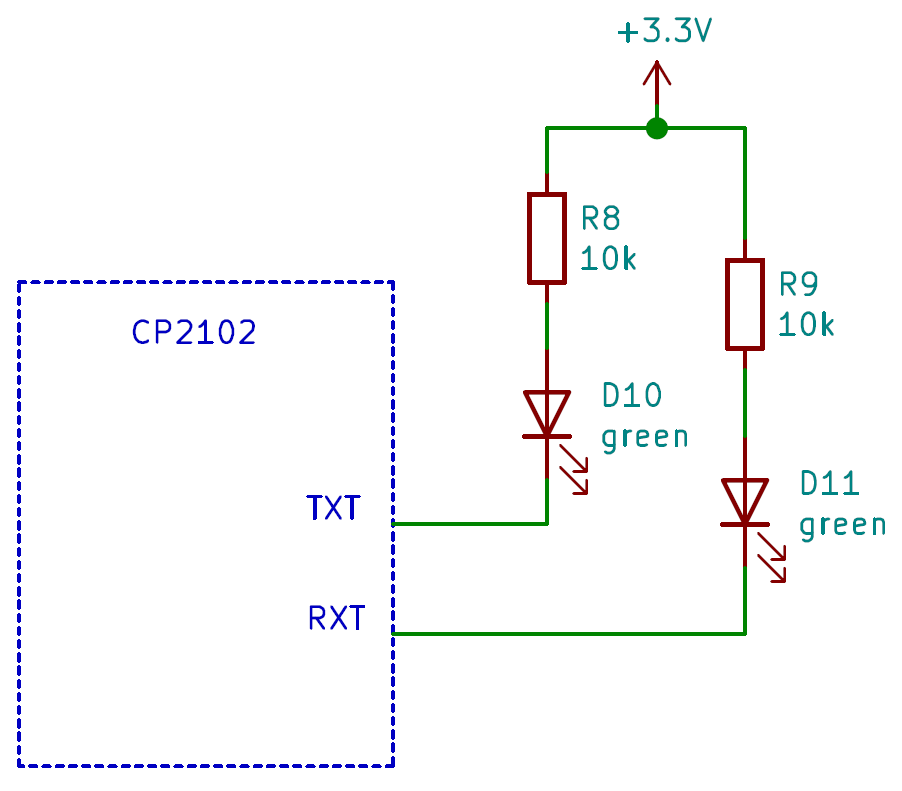
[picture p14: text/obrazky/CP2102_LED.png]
        
      \end{center}
      \caption[Zapojení LED pro indikaci komunikace čipu CP2102 s~mikrokontrolérem ESP32-PICO \cite{CP2102_datasheet}]{Zapojení LED pro indikaci 
      komunikace čipu CP2102 s~mikrokontrolérem ESP32-PICO \cite{CP2102_datasheet}.}
  \end{figure}

  \newpage
  \section{Herní prvky}
  Herními prvky Elektronické hry Logic jsou inteligentní LED typu WS2812C. Tento typ inteligentních LED je určen pro přenosná 
  zařízení, protože mají oproti obdobným LED velmi nízkou spotřebu. Jsou také plně kompatibilní s~typem WS2812B \cite{WS2812C_datasheet}. K~těmto 
  inteligentním LED existují knihovny, které usnadňují softwarovou práci s~nimi.

  \begin{figure}[!h]
    \begin{center}
      
    \end{center}
    \caption[Zapojení inteligentních LED WS2812C \cite{WS2812C_datasheet}]{Zapojení inteligentních LED WS2812C \cite{WS2812C_datasheet}.}
  \end{figure}

  Každá inteligentní LED má v~sobě procesor, který slouží pro zpracování dat. 
  Inteligentní LED WS2812C se zapojují za sebou přes piny DATA~IN a~DATA~OUT. Každá inteligentní LED převezme data z~pinu 
  DATA~IN, která jsou pro ni určena, a~zbytek pošle ven přes pin DATA~OUT. K~pinu DATA~OUT je připojen pin DATA~IN další inteligentí LED. 

  \begin{table}[!h]
    \caption{Parametry inteligentních LED WS2812C \cite{WS2812C_datasheet}.}
    \begin{center}
        \begin{tabular}{|c|c|}
            \hline
            {\cellcolor[HTML]{C0C0C0}Napájecí napětí} & 3,5--5,3~V~\\
            \hline
            {\cellcolor[HTML]{C0C0C0}Výstupní napětí} & (VDD~-~0,5)--(VDD~+~0,5)~V~\\
            \hline
            {\cellcolor[HTML]{C0C0C0}Typický odběr proudu}  & 5~mA \\
            \hline
            {\cellcolor[HTML]{C0C0C0}Klidový odběr proudu}  & 0,3~mA \\
            \hline
        \end{tabular}    
    \end{center}
  \end{table}

  Ke každé inteligentní LED je připojen mezi napájecí napětí a~GND filtrační kondenzátor, aby LED svítily kontinuálně 
  a~nedostal se jim na napájení žádný šum \cite{WS2812C_datasheet}.

  \subsection{Rozdělení}
  Inteligentní LED jsou rozděleny do tří skupin. Skupina inteligentních LED pro zadání, skupina inteligentních LED pro herní pole 
  a~skupina inteligentních LED pro zobrazení vyhodnocení tahu.
  Skupina inteligentních LED pro zadání obsahuje 4~LED a~skupiny pro herní pole a~pro vyhodnocení každá 40~LED.

  \subsection{Převodník úrovně}
  Inteligentní LED WS2812C pracují s~logikou 0--5~V. Mikrokontrolér ESP32-PICO pracuje s~logikou 0--3,3~V. 
  Z~tohoto důvodu byl mezi mikrokontrolér a inteligentní LED, na datový signál pro inteligentní LED, zapojen převodník úrovně, 
  tzv.~level shifter. 
  
  Převodník je realizován MOSFET tranzistorem a~dvěma pullup rezistory. Jeden rezistor je připojen k~napájecímu napětí 3,3~V a~druhý
  k~napájecímu napětí 5~V. Jedná se o~nejjednodušší způsob převodníku úrovně směrem nahoru. Tento způsob umožňuje komunikaci oběma směry. 
  Tranzistor MOSFET byl zvolen pro téměř nulovou spotřebu, narozdíl od bipolárních tranzistorů. Tranzistory MOSFET jsou také rychlejší 
  než bipolární tranzistory, takže způsobí menší zkreslení signálu. 

  \begin{figure}[!h]
    \begin{center}
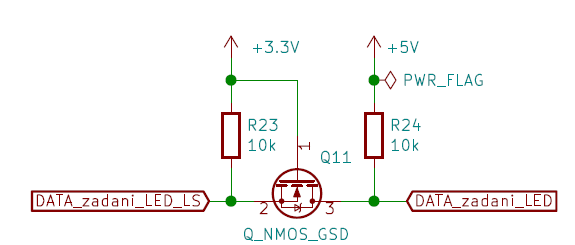
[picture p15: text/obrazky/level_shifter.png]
      
    \end{center}
    \caption[Zapojení převodníků úrovně]{Zapojení převodníku úrovně.}
  \end{figure}

  Pokud jsou obě zařízení v~klidu (nekomunikují), tak je tranzistor zavřený a~pullup rezistory zajišťují, že na pinu mikrokontroléru
  i~inteligentní LED je logická~1. Pro mikrokontrolér ESP32-PICO je to tedy 3,3~V a~pro inteligentní LED WS2812C je to 5~V. Jakmile započne
  mikrokontrolér komunikaci, to znamená, že svůj stav přepne do stavu logické nuly (0~V), tak rozdíl mezi gate a~source tranzistoru stoupne a~na 
  výstupu tranzistoru bude také logická nula (0~V). Pokud by komunikace mohla probíhat i~naopak (inteligentní LED by odesílala data do
  mikrokoltroléru), tak by byl princip totožný. 

  \subsection{Zapínání napájení}
  Deska plošného spoje je navrhována pro přenosnou aplikaci, a~proto je potřeba zajistit její co nejnižší odběr. 

  Inteligentní LED WS2812C mají spotřebu 0,3~mA ve vypnutém stavu \cite{WS2812C_datasheet}. I~takto nízká spotřeba je  pro přenosnou aplikaci 
  nežádoucí. Připojení
  napájení inteligentním LED je tedy spínáno. Proto je herní pole dohromady
  s~vyhodnocovacími LED rozděleno na 3~části. Tyto 3~části mají rozděleno napájení, které je postupně softwarově zapínáno dle potřeby. 
  Do první části patří inteligentní LED se zadáním a~první 4~čtveřice inteligentních LED 
  z~herního pole a~z~vyhodnocení. Do druhé části patří další 3~čtveřice inteligentních LED z~herního a~vyhodnocovacího pole. 
  Do třetí části patří poslední 3~čtveřice inteligentních LED z~herního a z~vyhodnocovacího pole.

  Ke spínání slouží obvody s~MOSFET tranzistory. Tranzistory MOSFET byly zvoleny pro jejich téměř nulovou spotřebu, narozdíl od 
  bipolárních tranzistorů. 

  \begin{figure}[!h]
    \begin{center}
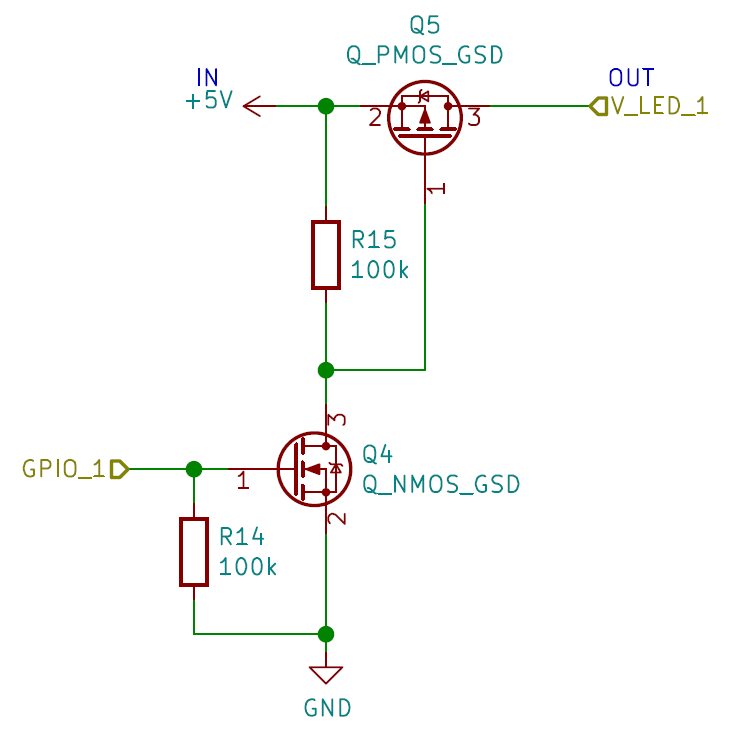
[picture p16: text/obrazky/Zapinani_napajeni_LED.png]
      
    \end{center}
    \caption[Obvod pro zapínání napájení pro inteligentní LED]{Obvod pro zapínání napájení pro inteligentní LED.}
  \end{figure}

  Napájení inteligentních LED nelze spínat pouze jedním tranzistorem, protože logická~1~mikrokontroléru ESP32-PICO má hodnotu pouze 3,3~V. 
  V~tomto případě je ale zapotřebí spínat 5~V. Pokud by byl pro spínání použit pouze jeden tranzistor, tak by bylo napájení vždy sepnuto.

  Vstupně-výstupní pin mikrokontroléru ESP32-PICO je nastaven do logické~0. V~případě, že je zapotřebí rozsvítit další LED na řádku, který 
  nemá zapnuto napájecí napětí, tak je GPIO pin nastaven do logické~1 a~napájecí napětí je přivedeno dané skupině LED. 
  
  Při logické nule na gate 
  tranzistoru Q4 je tranzistor zavřený. Tranzistor Q5 v~tomto okamžiku drží zavřený rezistor R15.

  Když je signál GPIO\_1, přivedený z~mikrokontroléru, přepnut do logické~1, tak se tranzistor Q4 otevře. Otevřením tranzistoru Q4 je gate tranzistoru Q5 
  připojen ke GND a~tím se otevře i~tranzistor Q5, kterým je sepnuto napájecí napětí dané skupině inteligentních LED.

  Rezistor R14 udržuje tranzistor Q4 zavřený při nestandardních stavech pinu mikrokontroléru, jako je např. při resetu procesoru.

  \section{Mechanické prvky}
  Přepínač SW1 slouží pro zapínání celé DPS. Tento přepínač připojuje napájecí napětí 5~V~z~USB konektoru k~celému zbytku DPS. 

  \begin{figure}[!h]
    \begin{center}
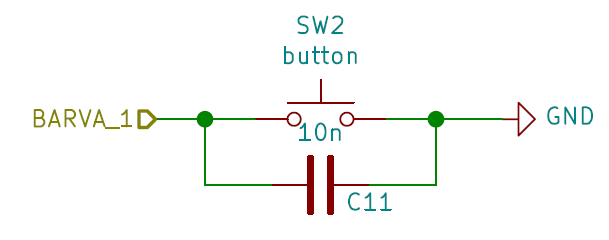
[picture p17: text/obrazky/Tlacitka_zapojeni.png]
      
    \end{center}
    \caption[Zapojení tlačítek]{Zapojení tlačítek.}
  \end{figure}

  Tlačítka SW2 až SW12 slouží pro ovládání hry. Ke každému tlačítku je připojen kondenzátor o~hodnotě 100~nF. Tento kondenzátor 
  slouží pro filtraci zákmitů při zmáčknutí tlačítka. Filtrace se díky tomu nemusí řešit softwarově.

  \begin{table}[!h]
    \caption{Připojení přepínačů ke konfiguračním pinům mikrokontroléru.}
    \begin{center}
        \begin{tabular}{|c|c|c|c|}
            \hline
            \rowcolor[HTML]{C0C0C0} 
            Přepínač   & Pin mikrokontroléru & Typ připojení rezistoru \\
            \hline
            SW14      & GPIO15 & Pullup \\
            \hline
            SW13      & GPIO05 & Pullup \\
            \hline
            SW15      & GPIO02 & Pulldown \\
            \hline
        \end{tabular}    
    \end{center}
  \end{table}

  Přepínače SW13 až SW15 slouží pro volbu možnosti hry. První přepínač slouží pro volbu hry pro jednoho, nebo pro 2 hráče. Druhý 
  slouží pro možnosti hry na 3~nebo 4~herní prvky a~poslední přepínač slouží pro nastavení, zda se v~zadání může, nebo 
  nesmí vyskytnout mezera. 
  
  Z~důvodu obsazenosti pinů musely být přepínače připojeny k~mikrokontroléru ESP32-PICO přes konfigurační piny. U~konfiguračních pinů
  musejí být dodržena pravidla pro připojovaná zařízení.
  Z~těchto důvodů je jeden přepínač připojen přes pulldown rezistor a~ostatní dva přepínače jsou připojeny přes pullup rezistor. 

  \begin{figure}[!h]
    \begin{center}
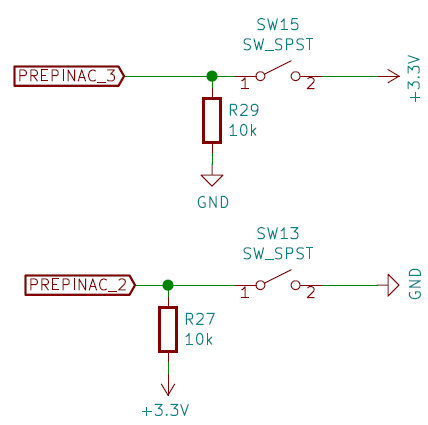
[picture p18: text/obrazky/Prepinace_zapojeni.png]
      
    \end{center}
    \caption[Zapojení přepínačů]{Zapojení přepínačů.}
  \end{figure}

  \section{Indikace přítomnosti napájecího napětí}
  Pro indikaci přítomnosti napájecího napětí slouží LED~D1~a~D2. Elektroluminiscenční dioda~D1 indikuje přítomnost napájecího napětí 
  5~V~a~LED~D2 indikuje přítomnost napájecího napětí 3,3~V. Obě LED mají zelenou barvu a~jsou připojeny přes
  rezistor o~hodnotě 10~k$\Omega$.

  \begin{figure}[!h]
    \begin{center}
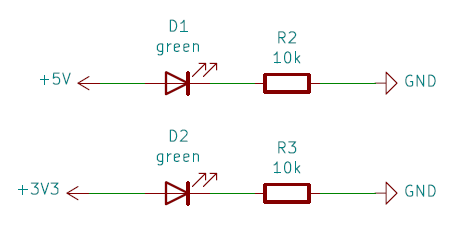
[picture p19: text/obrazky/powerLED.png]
      
    \end{center}
    \caption[Zapojení LED pro indikaci napájecího napětí]{Zapojení LED pro indikaci napájecího napětí.}
  \end{figure}

  \chapter{Návrh DPS}
  Deska plošného spoje je navržena v~programu KiCad a~její parametry jsou určeny pro výrobu i~osazení ve firmě JLCPCB \cite{KiCad} \cite{JLCPCB}. Výrobní 
  podklady proto musely být navrženy v~souladu s~jejich výrobními možnostmi \cite{JLCPCB_Capabilities}.

  Deska plošného spoje má 4~vrstvy. Vnitřní vrstvy slouží pro napájení a~vnější pro signálové dráhy. V~jedné vnitřní vrstvě je po celé její ploše 
  polygon GND a~ve druhé vnitřní vrstvě jsou polygony jednotlivých napájecích napětí. Součástky jsou rozloženy tak, aby pokud možno
  korespondovaly s~polygony a~jednotlivá napájecí napětí tak nemusela být dále rozváděna zbytečně po celé DPS. Někdy však nemohlo být umístění 
  přizpůsobeno a~napájecí napětí tak muselo být přivedeno dráhou v~horní nebo spodní vrstvě, které jsou převážně určeny pro signálové 
  dráhy. 

  Na vrchní straně jsou umístěny plošky pro osazení součástek, protože firma JLCPCB osazuje součástky pouze z~jedné strany DPS.

  Signálové dráhy jsou vedeny úzkou dráhou a~napájecí dráhy jsou vedeny širší dráhou. V~signálových drahách tečou zanedbatelné 
  proudy, proto mohou být co nejužší. Výrobce umožňuje vyrobit u~čtyřvrstvé DPS nejužší dráhu 0,09~mm \cite{JLCPCB_Capabilities}. 
  Aby nebyly použity krajní výrobní hodnoty, byla zvolena šířka signálové dráhy 0,15~mm.

  Dráhy, kterými je vedeno napájecí napětí, mají tloušťku 0,5~mm. Pro výpočet šířky dráhy byla použita online kalkulačka Printed
  Circuit Board Width Tool \cite{Kalkulacka_drahy_DPS}. 
  Celá DPS obsahuje 84~inteligentních LED a každá z~nich má průměrný odběr proudu 5~mA. Celkový proudový odběr byl stanoven dle:

  \begin{equation} 
    I~=~I_{LED}~\cdot~n~=~5~\cdot~84~=~420~\:~mA.
  \end{equation}

  Proud dráhami při použití všech inteligentních LED je 420~mA a~tloušťka 
  mědi 35~$\mu$A \cite{JLCPCB_Capabilities}. Doporučená šířka dráhy byla tedy 0,236~mm, a~proto byla zvolena šířka dráhy 0,5~mm.

  Vnější vrstvy byly vyplněny polygonem GND. Zejména tak bylo učiněno kvůli výrobnímu procesu nanášení nepájivé masky. Tato maska
  může být velmi tenká zejména na plochách, kde jsou pouze tenké dráhy a~žádné velké plochy. Vytvoření polygonu GND tak dopomáhá
  k~vytvoření pevné a~stejně tlusté nepájivé masky. 

  \newpage
  \section{Vzhled DPS}
  Vzhled DPS byl ovlivněn vzhledem deskové hry a~výrobními možnostmi firmy JLCPCB. Rozměry DPS velmi ovlivňují cenu výroby. U~firmy 
  JLCPCB je zlomová hranice 10~$\times$~10~cm. Poté cena DPS rapidně narůstá. Rozměry 10~$\times$~10~cm byly pro návrh DPS Elektronické 
  hry Logic dostačující a~DPS byla tedy navržena na tyto rozměry. Poté byly do těchto rozměrů rozmisťovány součástky. 

  Inteligentní LED WS2812C jsou rozděleny do 3~skupin, aby se hra co nejvíce podobala deskové hře. Zároveň dopomáhá orientaci ve hře.
  Také kvůli množství inteligentních LED a~jejich poměrně velkým rozměrům (5~$\times$~5~mm) zabírají velkou část DPS 
  \cite{WS2812C_datasheet}. Proto musely být inteligentní LED rozmístěny jako první.

  Inteligentní LED pro zadání jsou umístěny v~horní části DPS. V~levém sloupci pod zadáním se nachází matice inteligentních LED, které slouží jako herní 
  pole, a~v~pravém sloupci je matice inteligentní LED pro vyhodnocení tahu. Rozložení LED reprezentuje herní tahy, proto jsou v~matici 4~$\times$~10~LED.
  
  Rozmístění tlačítek a~přepínačů probíhalo dle 
  rozmyšleného způsobu ovládání elektronické hry. Byl také brán ohled na estetiku vzhledu. Proto byly inteligentní LED i~tlačítka 
  rozmístěny dle přesné mřížky. Následně byl ostatními obvody využíván zbylý prostor. 

  Dráhy s~napájecím napětím by měly být co nejkratší a~měly by být vedeny co nejvíce zpříma. Proto byla snaha o~umístění součástek
  se stejným napájecím napětím k~sobě. Ne vždy ale mohla být tato doporučení splněna. Někdy musel být proveden kompromis mezi vzhledem a~funkčním 
  zapojením. 

  Dílčí obvody byly rozmístěny v~následujícím pořadí~-~USB konektory, měnič napětí, převodník z~USB 
  na RS-232 a~mikrokontrolér ESP32-PICO. Konektory USB musely být umístěny na okraj DPS, proto byly jednotlivé části obvodu naskládány podél levého okraje.

  Převodník úrovně je umístěn vždy těsně před vstupem signálu do první inteligentní LED daného řetězce.

  Přepínač pro změnu hry pro jednoho a~pro 2~hráče byl umístěn do mezery, mezi herními a~vyhodnocovacími inteligentními LED. Další 2~přepínače, jeden 
  pro volbu hry na 3~nebo 4~herní prvky a~druhý na volbu nastavení, zda se v~zadání může, nebo nesmí vyskytnout mezera, jsou umístěny v~pravém 
  horním rohu. 

  Obvody pro zapínání napájení jednotlivým sekcím inteligentních LED jsou umístěny vždy na začátku dané části polygonu vlevo od herních inteligentních
  LED.

  Vypínač pro zapínání napájení celé DPS je realizován kolébkovým vypínačem. Tento vypínač je umístěn na stěně krabičky a~pomocí drátových propojek 
  je připájen do připravených pájecích otvorů v~DPS.

  \section{Funkční rozmístění součástek}
  U~některých součástek není jejich umístění na DPS lhostejné. Rozmístění součástek v~některých případech může ovlivnit funkčnost obvodu. 
  Rozmístění součástek často souvisí s~rozkreslením ve schématu. Například kondenzátory filtrující šum napájecího napětí se umisťují co nejblíže přívodu 
  napájení.

  Rozložení součástek měniče napětí na DPS může velmi ovlivnit jeho funkčnost, zejména pak jeho účinnost. Proto bylo rozložení a~zapojení součástek 
  převzato z~datasheetu.

  \begin{figure}[!h]
    \begin{center}
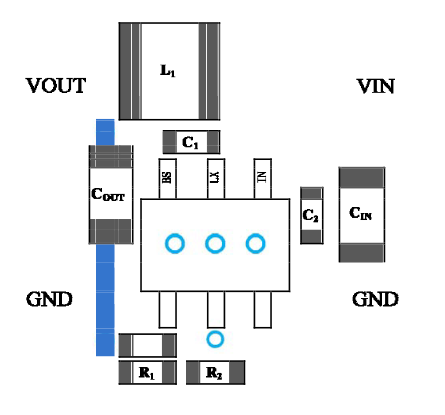
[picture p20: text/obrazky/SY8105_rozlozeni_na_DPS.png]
      
    \end{center}
    \caption[Rozložení součástek kolem čipu SY8105 na DPS \cite{SY8105_datasheet}]{Rozložení součástek kolem čipu SY8105 na DPS 
    \cite{SY8105_datasheet}.}
  \end{figure}

  Signály D+~a~D- od konektoru USB k~čipu CP2102 jsou diferenciálním párem. Tomuto faktu musely být přizpůsobeny i~dráhy těchto signálů. Dráhy 
  jsou vedeny vedle sebe a~blízko u~sebe. Po celou jejich délku se nepřibližují ani neoddalují. Zkřížení probíhá až těsně před vstupem do čipu CP2102.
  Kondenzátory u~mikrokontroléru ESP32-PICO a~u~čipu CP2102 musí být umístěny co nejblíže jejich pouzdru. Tyto kondenzátory slouží pro 
  filtraci šumu na napájecím napětí. Stejná pravidla platí také pro filtrační kondenzátory u~inteligentních LED WS2812C.

  Kondenzátory u~tlačítek jsou také umístěny co nejblíže pouzdru tlačítek. Čím blíže pouzdru kondenzátor bude, tím lépe budou 
  filtrovány zákmity při stisku tlačítka.

  \chapter{Oživení DPS}
  Při výrobě finální verze DPS Elektronické hry Logic byly využity maximální možnosti osazení firmou JLCPCB.  
  Pro oživení finální DPS je tedy zapotřebí pájení pouze vypínače, který není umístěn na DPS, ale je zasazen do krabičky a~zapájen
  do DPS pomocí drátových prodlužek. 

  Při objednání finální DPS nastaly problémy s~nedostatkem součástek, se kterým se v~této době potýká mnoho návrhářů \cite{Nedostatek_soucastek}. 
  Čip SY8105 neměla firma JLCPCB dlouhodobě na skladě a~nebylo možné čekat, než jej budou znovu osazovat. Z~tohoto důvodu byl na finální DPS přeosazen 
  z~nefunkčních prototypů. Za klasických okolností by byl ale i~tento čip osazen firmou JLCPCB.

  Po připojení DPS přes USB konektor k~powerbance, nebo do počítače, se rozsvítí LED~D1 a~D2, které indikují přítomnost 
  napájecího napětí. Elektroluminiscenční dioda D1 značí přítomnost napětí 5~V~z~powerbanky a LED~D2 značí správnou funkci zapojení měniče napětí, tedy přítomnost 
  napětí 3,3~V.
  %odběr proudu

  \begin{figure}[!h]
    \begin{center}
      
    \end{center}
    \caption[Finální verze]{Finální verze.}
  \end{figure}

  \chapter{Od prvního prototypu po finální verzi}

  Před finální verzí byly navrženy 2~prototypy DPS Elektronické hry Logic. Verze~0.0 byla pouze testovací, takže neobsahovala celé herní pole. 
  Sloužila pro ověření funkčnosti daných zapojení různých čipů a~zároveň pro základní testování softwaru.

  \begin{figure}[!h]
    \begin{center}
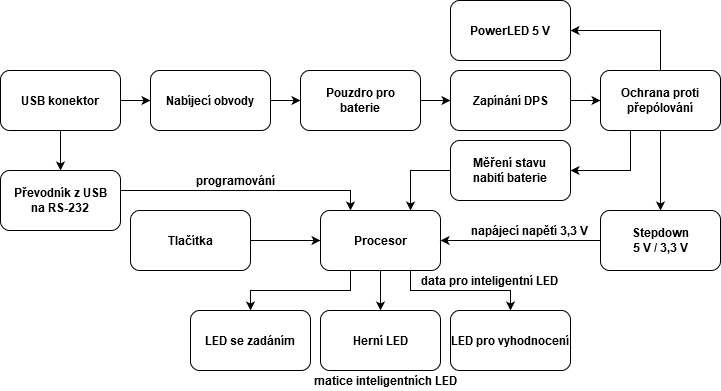
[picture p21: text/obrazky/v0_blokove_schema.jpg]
      
    \end{center}
    \caption[Blokové schéma zapojení prototypu verze~0.0]{Blokové schéma zapojení prototypu verze~0.0.}
  \end{figure}

  Asi největším rozdílem mezi verzí prototypu~0.0~a~1.0 je způsob napájení. Verze~0.0 je napájena z~baterií a~verze~1.0 je napájena pomocí USB 
  konektoru. Díky této změně 
  odpadly i~mnohé části obvodu. Díky absenci baterií bylo možné odstranit nabíjecí obvody, ochranu proti přepólování a~měření napětí 
  na bateriích. 

  \begin{figure}[!h]
    \begin{center}
      
    \end{center}
    \caption[Blokové schéma zapojení prototypu verze~1.0]{Blokové schéma zapojení prototypu verze~1.0.}
  \end{figure}

  \section{Způsoby napájení prototypů}
  Každý z~prototypů měl velmi odlišný způsob napájení. V~následujících kapitolách je popsán způsob napájení prototypových verzí.

  \subsection{Verze~0.0}
  V~první verzi prototypu byly pro napájení použity baterie Li-Ion INR18650-29E od firmy Samsung. Tyto baterie mají jmenovité napětí 3,7~V, 
  při plném nabití až 4,2~V~\cite{18650}. Kapacita jedné baterie je 2850~mAh \cite{18650}. Byly použity 2~články baterií, které byly spojeny 
  paralelně. Paralelním zapojením byla celková kapacita zdvojnásobena.

  Baterie typu Li-Ion jsou náchylné na podvybití. Verze~0.0 proto obsahovala i~měření napětí na bateriích. Pokud by došlo k~podvybití, mohla 
  by se bateriím zmenšovat kapacita nebo by se mohly zničit. 

  \begin{figure}[!h]
    \begin{center}
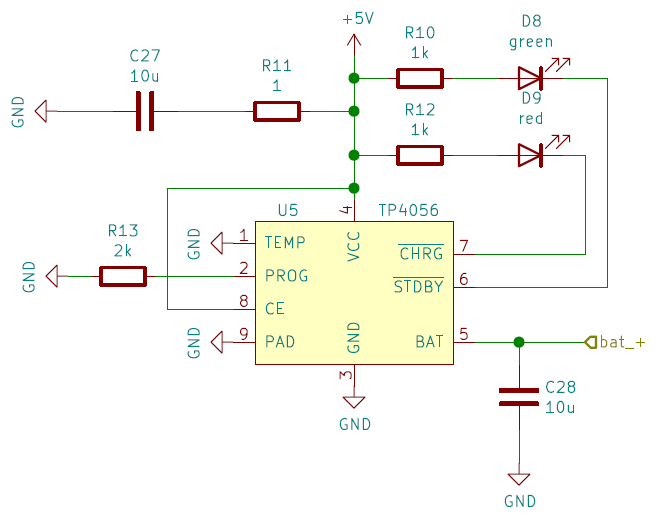
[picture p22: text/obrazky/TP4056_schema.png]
      
    \end{center}
    \caption[Schéma zapojení čipu TP4056 \cite{TP4056_datasheet}]{Schéma zapojení čipu TP4056 \cite{TP4056_datasheet}.}
  \end{figure}

  Pro baterie bylo vybráno pouzdro na 2~články s~THT montáží do DPS \cite{18650_pouzdro}.

  Pouzdro s~bateriemi bylo připevněno a~zapájeno přímo do DPS, a~proto musel být integrován i~nabíjecí obvod. Nabíjení probíhalo přes konektor 
  USB~Micro.

  Pro nabíjecí obvod byl zvolen čip TP4056. Tento obvod byl vybrán, protože je přímo určen pro nabíjení baterií typu Li-Ion. Existují 
  moduly pro nabíjení těchto baterií, které mají integrovaný tento čip \cite{Nabijeci_modul}. Tyto moduly jsou často používané, a~proto 
  bylo zapojení tohoto modulu převzato do této práce. 

  Vlastnosti čipu jsou přizpůsobeny bateriím Li-Ion. Nabíjení baterií probíhá do 4,2~V, což je maximální napětí na použitých 
  bateriích \cite{18650} \cite{TP4056_datasheet}. Díky tomu nemůže dojít ke zničení baterií nabíjením.

  Červená LED~D9 indikovala nabíjení baterií a~zelená LED~D8 svítila, pokud byly baterie nabité \cite{TP4056_datasheet}. 
  Pokud nesvítila ani červená ani zelená LED, znamenalo to, že baterie jsou podvybité, nebo nejsou vloženy. Příčinou mohla být také jejich příliš 
  vysoká, nebo nízká teplota \cite{TP4056_datasheet}.

  Rezistorem R13 se určoval nabíjecí proud baterií \cite{TP4056_datasheet}. Aby baterie nabíjením nebyly poškozovány, měl by být nabíjecí 
  proud maximálně 0,5~C (polovina kapacity baterie). Vybraná baterie má kapacitu 2850~mAh. Nabíjecí proud proto mohl být až 1425~mA. 
  Jelikož je pro tuto hru důležitější kapacita baterie, než doba nabíjení, byl zvolen nabíjecí proud pouze 0,5~A. Čím menším proudem 
  je baterie nabíjena, tím má delší životnost a~pomaleji ztrácí svoji kapacitu.

  \begin{table}[!h]
    \caption{Nastavení nabíjecího proudu rezitorem R13 \cite{TP4056_datasheet}.}
    \begin{center}
      \begin{tabular}{|c|c|}
          \hline
          R13 [k$\Omega$] & Nabíjecí proud [mA] \\
          \hline
          10      & 130 \\
          \hline
          5       & 250 \\
          \hline
          4       & 300 \\
          \hline
          3       & 400 \\
          \hline
          2       & 580 \\
          \hline
          1,66    & 690 \\
          \hline
          1,5     & 780 \\
          \hline
          1,33    & 900 \\
          \hline
          1,2     & 1000 \\
          \hline
      \end{tabular}  
    \end{center}
  \end{table}

  Byl zvolen rezistor o~hodnotě 2~k$\Omega$, kterým byl určen nabíjecí proud 580~mA. 

  \newpage
  \subsection{Verze~1.0}
  Ve verzi~1.0 byl radikálně změněn způsob napájení. Napájení v~této verzi neprobíhá přes baterie, ale pouze přes USB konektor, přes 
  který ve verzi~0.0 probíhalo pouze nabíjení baterií. 

  Výhody
  \begin{itemize}
    \item absence drahých baterií,
    \item absence nabíjecího obvodu,
    \item absence hlídání stavu nabití baterie,
    \item absence ochrany proti přepólování (USB konektor je uzpůsoben svým tvarem, aby uživatel nemohl napájení přepólovat.),
    \item napájení inteligentních LED napětím přímo z~USB (Inteligentní LED mají menší odběr proudu.).
  \end{itemize}

  Nevýhody
  \begin{itemize}
    \item předpokládá se, že uživatel vlastní powerbanku,
    \item výdrž závisí na kapacitě powerbanky. 
  \end{itemize}

  Byl zvolen konektor USB~Micro, protože se jedná o~nejrozšířenější USB konektor dnešní doby.

  Do finální verze byl poté přidán ještě i~konektor USB-C.

  \subsection{Vývoj mechanických prvků}
  Na obou prototypech byla použita tlačítka s~THT montáží. Do finální verze byla použita tlačítka s~SMD montáží. Tato tlačítka jsou 
  robustnější a~celokovová. 

  Do finální verze byly přidány také přepínače pro volbu možností hry. 

  \section{Vzhled DPS}
  Prototyp verze 0.0 měl menší rozměry než finální verze. Sloužil pouze pro testování zapojení, odhalení nedostatků a~pro základní testování
  softwaru. 

  První prototyp také obsahoval pouzdro na baterie Li-Ion 18650, které bylo navrženo jako jediné na spodní straně DPS. Bylo tak umístěno
  kvůli úspoře místa. Rozmístění součástek základních dílčích obvodů bylo situováno především do horní části DPS. 

  Druhý prototyp se již svým vzhledem velmi podobal finální verzi.
  
  \section{Oživení prototypů}
  Při výrobě prototypů firma JLCPCB osazovala pouze SMD komponenty. Komponenty THT musely být doosazovány ručně. V~následujících kapitolách
  je popsán způsob oživování prototypů DPS.

  \subsection{Verze 0.0}
  Deska plošného spoje přišla z~výroby ve stavu, kdy byly osazeny pouze SMD komponenty.

  \begin{figure}[!h]
    \begin{center}
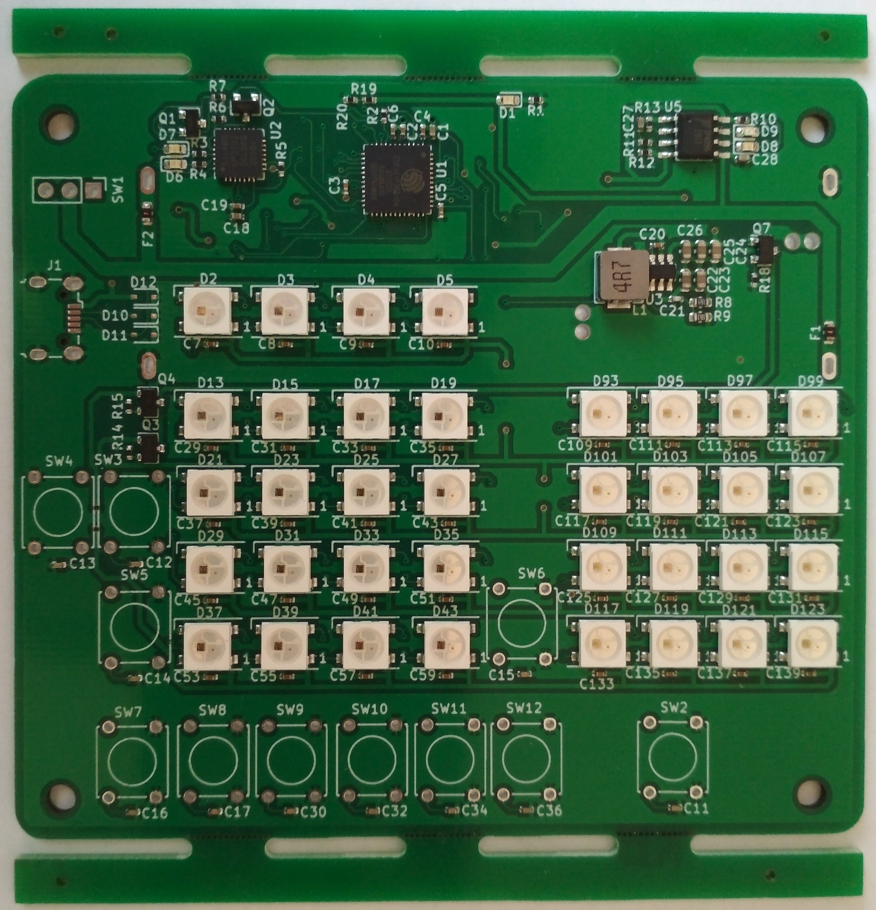
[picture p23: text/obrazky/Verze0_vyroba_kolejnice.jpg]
      
    \end{center}
    \caption[DPS prototypu verze~0.0 z~výroby]{DPS prototypu verze~0.0 z~výroby.}
  \end{figure}

  Po dodání DPS z~výroby byly zapájeny THT komponenty (pouzdro na baterie, konektor USB Micro, tlačítka a~vypínač). Na testovací verzi
  byl místo vypínače osazen konektor, na který je pro zapnutí DPS potřeba nasunout propojku. Po vložení baterií
  18650 do pouzdra a~zapnutí vypínače se rozsvítí zelená LED~D1, která indikuje přítomnost napájecího napětí. 

  Po vložení baterií do pouzdra a~zapnutí DPS bylo pomocí multimetru zjištěno, že ochrana proti přepólování baterií nepropouští napětí 
  dále, i~když jsou baterie v~pouzdře umístěny se správnou orientací napětí. Bylo zjištěno, že pouzdro tranzistoru zajišťujícího ochranu proti přepólování 
  neodpovídá navrženému pouzdru tranzistoru. Všechny MOSFET tranzistory byly stejného typu, takže musely být všechny odpájeny a~otočeny.
  
  Při zkoušce nabíjení bylo zjištěno, že červená LED indikující nabíjení baterií je přepólovaná. Elektroluminiscenční diodu se povedlo otočit a~indikace nabíjení 
  baterií z~USB byla v~pořádku. 
  
  Při programování byl zjištěn problém s~komunikací po lince RS-232. Bylo zjištěno, že zapojení LED pro indikaci komunikace po lince RS-232 bylo 
  chybně navrženo, a~proto byly LED odstraněny a~nahrazeny zkratem. Jejich zapojení této komunikaci bránilo. Do další verze byly překresleny správně.
  Bipolární tranzistory byly taktéž osazeny ve špatném pouzdře a~neodpovídaly navrženým pouzdrům. 
  
  Při programování a~testování všech inteligentních LED WS2812C a~tlačítek bylo zjištěno, že jedno tlačítko bylo zapojeno na pin, který 
  nemá softwarově zapínatelný pullup rezistor. Tento rezistor byl dodatečně osazen a~do schématu i~DPS další verze zakreslen. 
  
  Po veškerých opravách byla DPS plně funkční a~připravena na testování softwaru Elektronické hry Logic.

  \begin{figure}[!h]
    \begin{center}
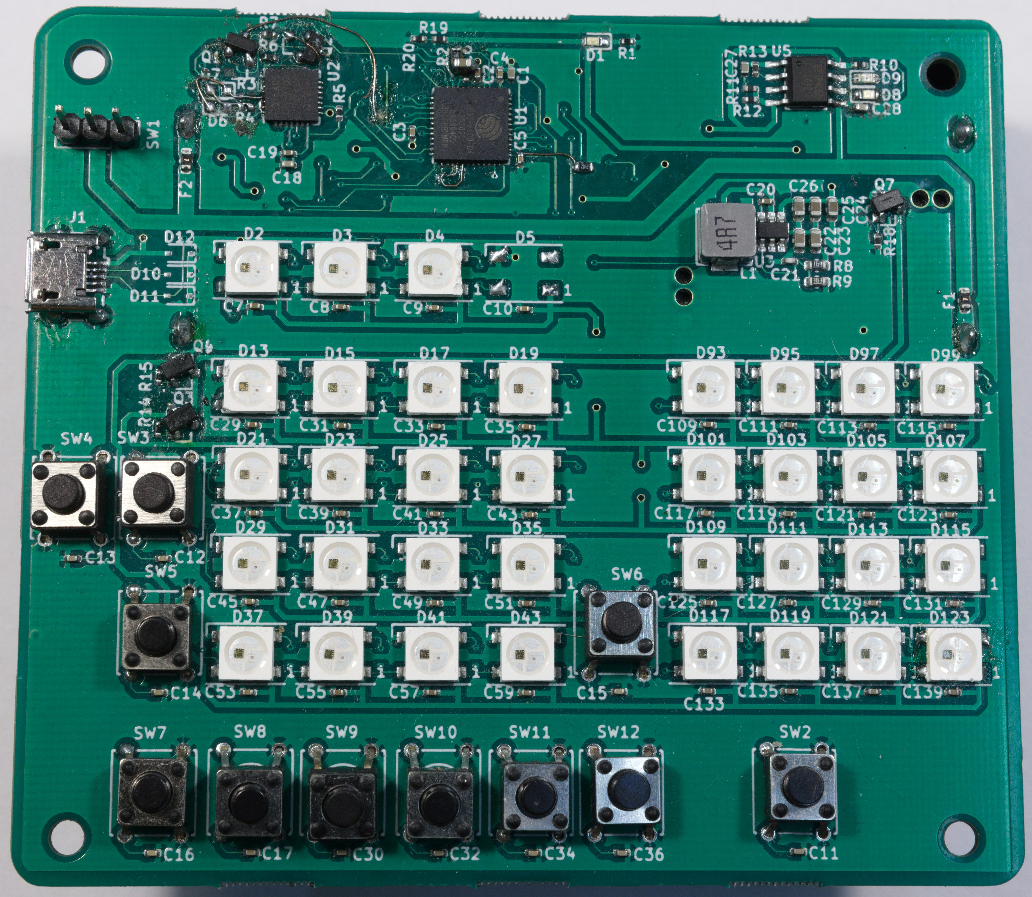
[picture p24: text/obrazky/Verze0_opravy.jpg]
      
    \end{center}
    \caption[Verze prototypu~0.0 s~opravami]{Verze prototypu~0.0 s~opravami.}
  \end{figure}

  \newpage
  \subsection{Verze~1.0}
  Deska plošného spoje přišla z~výroby ve stavu, kdy byly osazeny pouze SMD komponenty. 

  \begin{figure}[!h]
    \begin{center}
      
    \end{center}
    \caption[Prototyp verze~1.0]{Prototyp verze~1.0.}
  \end{figure}

  Poté byly ručně osazeny THT součástky, tj. vypínač, tlačítka a~konektor USB Micro. Po připojení DPS přes USB konektor k~powerbance, 
  nebo do počítače, se rozsvítí LED~D1~a~D2, které indikují přítomnost napájecího napětí. LED~D2 zároveň značí, že zapojení měniče
  napětí je funkční.

  Všechny chyby z~předchozí verze prototypu byly odstraněny. Deska plošného spoje byla tedy plně funkční a~mohla být programována hra Logic v~plném rozsahu.
  
  Po otestování byly k~DPS přidány přepínače a~poté byla finální verze DPS objednána.

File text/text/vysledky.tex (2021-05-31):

\chapter{Software}
Software pro Elektronickou hru Logic byl napsán v~jazyce C++. Bylo využito skutečnosti, že mikrokontrolér ESP32-PICO podporuje Arduino 
framework. Pro psaní softwaru bylo použito vývojové prostředí Visual Studio Code.

Pro programování inteligentních LED bylo využito již existující knihovny SmartLeds.h \cite{SmartLeds}.
Tato knihovna velmi usnadňuje softwarovou práci s~těmito inteligentními LED. Obsahuje například funkci {\it show}, která umožní zobrazit 
nastavené barvy na všech inteligentních LED připojených k~jednomu pinu mikrokontroléru ESP32-PICO. 

Celý software je rozdělen do dvou částí, počáteční inicializace a~nekonečná smyčka programu. 

Po spuštění probíhá inicializace vstupně-výstupních pinů a~také inicializace proměnných. Všem inteligentním LED je vypnuto napájecí napětí. 
Dále je všem inteligentním LED nastavena barva na černou, tzn. LED nesvítí. Po kompletním nastavení se již čeká na stisk tlačítka "Nová hra". 

\begin{figure}[!h]
    \begin{center}
      
    \end{center}
    \caption[Vývojový diagram softwaru]{Vývojový diagram softwaru.}
  \end{figure}

\newpage
\section{Tlačítko Nová hra}
Když je stisknuto tlačítko "Nová hra", tak je všem inteligentním LED nastavena černá barva. Program načte stavy přepínačů. Pokud je nastavena hra pro 
jednoho hráče, tak je vygenerováno zadání. Pokud je hra s~mezerou, tak je generace zadání rozšířena o~černou barvu. Poslední přepínač určuje délku 
vygenerovaného zadání. V~případě hry pro jednoho hráče je přepínač s~mezerou ignorován. Následně je zapnuto napájecí napětí 
první části inteligentních LED a~poté program přechází do druhé části, tj. nekonečné smyčky.

\begin{minipage}{\linewidth}
\begin{lstlisting}[frame=single,numbers=right,caption={Funkce pro vygenerování zadání.},label=lst:priklad.vypis.kodu.C,basicstyle=\ttfamily\small, keywordstyle=\color{black}\bfseries\underbar,]
void generate_task (Colors *task, int length, int diff){
    for(int i = 0; i < length; ++i)
        task[i] = Colors(esp_random() % (NUM_OF_COLORS - diff));
}     
void set_task(led_t &leds, Colors* array_task, int length){
    for (int i = 0; i < length; ++i){
        leds.pos = i;
        set_color(leds, array_task[i]); 
    } 
}   
\end{lstlisting}
\end{minipage} 

Nekonečná smyčka má dva hlavní úkoly. Detekuje stisknutí tlačítek a~v~pravidelných intervalech bliká kurzorem. Na konci každého průchodu smyčkou 
se obnoví zobrazení na inteligentních LED.

  \begin{figure}[!h]
    \begin{center}
      
    \end{center}
    \caption[Funkce tlačítka Nová hra]{Funkce tlačítka "Nová hra".}
  \end{figure}

\newpage
\section{Tlačítka interpretující šipky}
Po každém stisku některé z~šipek program nejprve zjišťuje, zda je spuštěna hra pro jednoho, nebo pro dva hráče, a~také, v~případě hry pro dva
hráče, v~jaké části inteligentních LED se právě nachází kurzor. Poté je kurzor dle dané šipky posunut buď o~jedno pole vpravo, nebo o~jedno 
pole vlevo, v~rámci dané části inteligentních LED. 

\begin{minipage}{\linewidth}
  \begin{lstlisting}[frame=single,numbers=right,caption={Funkce posouvající kurzor.},label=lst:priklad.vypis.kodu.C,basicstyle=\ttfamily\small, keywordstyle=\color{black}\bfseries\underbar,]
  void shift_cursor (led_t &LED, Direct DIR, int length){
      if((DIR == RIGHT) && 
          !((LED.pos + 1 + LINE_LENGTH - length) % LINE_LENGTH))
          LED.pos -= LINE_LENGTH - (LINE_LENGTH - length) - 1;
      else if(DIR == RIGHT)
          LED.pos += 1;
      else if((DIR == LEFT) && 
              (LED.pos == 0 || !(LED.pos % LINE_LENGTH)))
          LED.pos += LINE_LENGTH - (LINE_LENGTH - length) - 1;
      else if(DIR == LEFT)
          LED.pos -= 1;
  }   
  \end{lstlisting}
  \end{minipage} 

Pokud se kurzor nachází na konci řádku a~je stisknuto tlačítko "Šipka vpravo", je pozice přepočítána tak, aby se kurzor posunul na 
začátek téhož řádku. Pokud se kurzor nachází na začátku řádku a~je stisknuto tlačítko "Šipka vlevo", je pozice přepočítána tak, aby se kurzor 
posunul na konec téhož řádku. 

  \begin{figure}[!h]
    \begin{center}
      
    \end{center}
    \caption[Funkce šipek]{Funkce šipek.}
  \end{figure}
    
\section{Barevná tlačítka}
Po každém stisku barevného tlačítka program zjišťuje, zda je spuštěna hra pro jednoho, nebo pro dva hráče, a~také, v~případě hry pro dva hráče,
v~jaké části inteligentních LED se právě nachází kurzor. Poté se nastaví v~dané části daná barva LED na pozici kurzoru a~kurzor se posune
o~jedno pole vpravo. Pokud se ve hře pro dva hráče nachází kurzor ve vyhodnocovací části, tak jsou stisky všech barev kromě červené a~žluté 
ignorovány. Na konci průchodu smyčkou je tato změna zobrazena na inteligentních LED. 

  \begin{figure}[!h]
    \begin{center}
      
    \end{center}
    \caption[Funkce barevných tlačítek]{Funkce barevných tlačítek.}
  \end{figure}

\section{Tlačítko Potvrdit tah}
Po stisku tlačítka "Potvrdit tah"\  je zjištěno, zda je nastavena hra pro jednoho, nebo pro dva hráče. 

Pokud je nastavena hra pro jednoho hráče, tak dojde k~vyhodnocení tahu a~kurzor je posunut na první LED dalšího herního řádku. Pokud je již 
kurzor na posledním řádku, tak je zobrazeno zadání a~kurzor přestává blikat. Pokud se shoduje herní kombinace se zadáním dříve, než na 
posledním řádku, tak je zobrazeno vyhodnocení i~zadání. Kurzor přestává blikat a~hra čeká na stisk tlačítka "Konec", nebo "Nová hra". 

\begin{figure}[!h]
    \begin{center}
      
    \end{center}
    \caption[Funkce tlačítka Potvrdit tah]{Funkce tlačítka "Potvrdit tah".}
  \end{figure}

Vyhodnocení probíhá ve dvou krocích. Nejdříve jsou hledány barvy na správných pozicích. Tyto barvy jsou ohodnoceny červeně. Pozice těchto 
barev jsou v~dalších krocích vynechávány. Pokud je počet nalezených barev na shodných pozicích stejný, jako je délka zadání, tak vyhodnocení 
končí. Pokud tomu tak není, vyhodnocení pokračuje. Následně pokud je nalezena ve zbylých barvách barva, která je obsazena v~zadání, tak je 
ohodnocena žlutou barvou. Každá ohodnocená barva se v~dalších krocích již přeskakuje. 

Pokud je nastavena hra pro dva hráče, dojde k~posunutí kurzoru na první LED části, která je právě na řadě. Pokud byl kurzor v~zadání, posune
se do herního pole, pokud byl v~herním poli, posune se do pole pro vyhodnocení a~pokud byl kurzor v~poli pro vyhodnocení, tak se přesune
do herního pole. 

Pokud má následující řádek vypnuto napájecí napětí, tak je toto napětí softwarově zapnuto. 

  \section{Tlačítko Konec}
  Pokud je stisknuto tlačítko "Konec", jsou všechny LED zhasnuty a~poté je jim odpojeno napájecí napětí. Následně se čeká na stisk tlačítka
  "Nová hra". 

  \begin{figure}[!h]
    \begin{center}
      
    \end{center}
    \caption[Funkce tlačítka Konec]{Funkce tlačítka "Konec".}
  \end{figure}

\chapter{Způsob ovládání elektronické hry}
Deska plošného spoje obsahuje 3~přepínače SW13, SW14 a SW15. Těmito přepínači si hráč volí způsob hry.

Přepínač SW15 slouží k~volbě hry pro jednoho, nebo pro dva hráče. Pokud hráč umístí přepínač do pozice ON, hra se přepne
do módu pro dva hráče. Rozdíl mezi těmito variantami hry je popsán v~následujících kapitolách a~funkce dalších přepínačů taktéž.

\section{Hra pro jednoho hráče}
Tato verze hry pro jednoho hráče má stejná pravidla jako desková hra Logic. Funkci druhého hráče nahrazuje řídicí elektronika
- mikrokontrolér ESP32-PICO.

Po zapnutí DPS stiskne hráč tlačítko "Nová hra". V~této chvíli se vygeneruje zadání, které není vidět, a~první herní LED se 
rozbliká. Blikající herní LED značí pozici kurzoru. 
Kurzorem lze pohybovat pomocí šipek interpretovanými tlačítky "Šipka vpravo"\  a~"Šipka vlevo". Barvy herních LED se nastavují 
tlačítky ve spodní části DPS. Tato tlačítka jsou označena danými barvami. Pokud hráč zadá barvu, kterou zadat nechce, má dvě možnosti,
jak ji smazat. Kurzorem vybere danou barvu a~buď ji hned změní na jinou barvu pomocí daného barevného tlačítka, nebo stiskne tlačítko 
stejné barvy a~barva se smaže. 
Po zadání kombinace stiskne hráč tlačítko "Potvrdit tah". Po stisku tohoto tlačítka proběhne vyhodnocení a~to se zobrazí na 
vyhodnocovacích LED. 
Červená barva ve vyhodnocení značí, že hráč má v~barevné kombinaci stejnou barvu se zadáním na stejné pozici. Žlutá barva znamená,
že hráč má v~barevné kombinaci stejnou barvu se zadáním, ale na chybné pozici. Další barvy nejsou ohodnoceny. Pozice vyhodnocení
záměrně není shodná s~pozicemi, kterých se hodnocení týká. Zleva jsou nejdříve umístěna všechna červená a~až poté všechna žlutá 
hodnocení.

Po vyhodnocení se kurzor posune na první LED v~dalším řádku. Hra pokračuje obdobným způsobem.
Po zadání správné kombinace barev a~jejich pozic se rozsvítí zadání a~hra je u~konce. Pro novou hru stiskne hráč tlačítko
"Nová hra"\  a~pro ukončení tlačítko "Konec".
Po stisku tlačítka "Konec"\  zhasnou všechny herní, vyhodnocovací LED i~LED pro zadání. Poté je DPS připravena pro vypnutí
vypínačem.

Přepínač SW13 slouží pro nastavení, zda má zadání délku 3~nebo 4~pozice. Pokud hráč umístí přepínač do pozice ON, tak tím 
zvolí variantu hry na 4~pozice. V~poloze 1~je zvolena varianta na 3~pozice a pohyb kurzoru se tím omezí pouze na první 3~pozice 
v~řádku. Poslední pozice se ignoruje a~také nikdy nesvítí.

Přepínač SW14 slouží pro nastavení, zda zadání může nebo nesmí obsahovat mezeru. Pokud dá hráč přepínač do pozice ON, 
tak v~zadání mezera nikdy není. Pokud je v~poloze 1, tak v~zadání mezera být může. Není to ale nutností. 

\begin{figure}[!h]
    \begin{center}
        
    \end{center}
    \caption[Vývojový diagram verze hry pro jednoho hráče]{Vývojový diagram verze hry pro jednoho hráče.}
    \end{figure}

\newpage
\section{Hra pro dva hráče}
Varianta Elektronické hry Logic pro dva hráče má totožná pravidla s~deskovou hrou. Po spuštění hry a~stisku tlačítka "Nová hra"\ bliká 
kurzor v~poli inteligentních LED se zadáním. První hráč zadává barvy pomocí barevných tlačítek a~v~poli LED se pohybuje pomocí šipek 
interpretovanými tlačítky. Hráč zadání zakryje stříškou a~stiskne tlačítko „Potvrdit tah“. 

Po stisku zadání zůstane svítit a~kurzor se přesune na první herní LED. Druhý hráč hledá zadanou kombinaci a~tuto náhodnou kombinaci 
navolí pomocí barevných tlačítek. Kurzorem může taktéž pohybovat pomocí šipek interpretovanými tlačítky.
Pokud hráč zadá barvu, kterou zadat nechce, má dvě možnosti,
jak ji smazat. Kurzorem vybere danou barvu a~buď ji hned změní na jinou barvu pomocí daného barevného tlačítka, nebo stiskne tlačítko 
stejné barvy a~barva se smaže. Po zadání kombinace 
druhý hráč stiskne tlačítko „Potvrdit tah“\  a~kurzor se přesune na první pozici vyhodnocovacího pole. 

První hráč má v~tuto chvíli aktivní pouze šipky a~červené a~žluté barevné tlačítko. Červenou barvu zadává jako první a~indikuje jí, že 
některá barva druhého hráče je obsažena v~zadání, a~to na totožné pozici. Poté zadává žlutou barvu, kterou 
udává, že některá z~barev prvního hráče je obsažena v~zadání, ale na jiné pozici, než kam ji druhý hráč umístil. Vyhodnocení 
hráč záměrně neumisťuje na pozice, kterých se hodnocení týká. Zpravidla se zleva umisťují nejdříve všechna červená a~až poté 
všechna žlutá hodnocení. 

Po dokončení hodnocení první hráč stiskne tlačítko "Potvrdit tah"\  a~kurzor se opět přesune na první pozici dalšího řádku herního pole. 
Hra dále pokračuje obdobným způsobem.
Pokud druhý hráč nalezne správnou kombinaci, pak první hráč odkryje zadání pro možnou kontrolu a~hra je u~konce. Pro možnost další 
hry stiskne jeden z~hráčů tlačítko „Nová hra“. Celé herní, vyhodnocovací pole i~pole se zadáním je smazáno a~kurzor je znovu posunut 
na první pozici pole se zadáním. 

Přepínač SW13 slouží pro nastavení hry na 3~nebo 4~pole. Pokud hráči umístí přepínač do polohy ON, tak zvolí variantu hry na 4~pole. 
V~poloze~1~zvolí variantu hry na 3~pole a~omezí tím pohyb kurzoru pouze na 3~pole v~každém řádku každé herní části. Poslední pozice
nikdy nesvítí a~nikdy se také nehodnotí. 

Pozice přepínače SW14 se ve variantě hry pro dva hráče ignoruje. 

\begin{figure}[!h]
    \begin{center}
        
    \end{center}
    \caption[Vývojový diagram verze hry pro dva hráče]{Vývojový diagram verze hry pro dva hráče.}
    \end{figure}

\chapter{Krabička}
Krabička byla navržena v~programu SolidWorks a~vytištěna na 3D tiskárně. Její rozměry jsou 106~$\times$~126~$\times$~13~mm. 

Spodní díl krabičky obsahuje 2~vyvýšené sloupky, ve kterých jsou otvory
na šrouby a~matice. Vnitřní a~nižší jsou určeny pro přišroubování DPS pomocí montážních otvorů a~šroubů M3. Vnější otvory jsou poté pro přišroubování 
vrchního krytu krabičky. Otvor v~horní části spodního dílu krabičky slouží pro umístění kolébkového vypínače. Na boční straně je také otvor
pro přivedení napájení USB konektorem.

Vrchní část krabičky obsahuje otvory pro LED a~také pro tlačítka a~přepínače. Tato část krabičky leží těsně nad DPS, aby nedocházelo k~podsvitu LED přes
sebe a~nemohlo tak docházet k~podvodům během hry. 

Tlačítka měla příliš nízké hmatníky a~po uzavření krabičky se velmi obtížně stiskávala. 
Ztenčení vrchního dílu již nemohlo být provedeno, a~proto byly otvory pro tlačítka navrženy v~kónickém tvaru. Tlačítka takto lze stisknout pohodlněji
a~mechanická pevnost zůstala zachována. 

Bylo zapotřebí označit tlačítka a~přepínače, k~čemu slouží. Ke všem přepínačům a~tlačítkům, kromě barevných, byly přidány texty, které jsou čitelné 
díky zanoření do vrchního dílu. Texty musely být malé, aby se na vrchní díl vešly a~aby bylo jednoznačné, kterého tlačítka, nebo polohy přepínače, se 
popisek týká. Rozlišení, které bylo zapotřebí, nelze dosáhnout běžnou 3D tiskárnou technologií FDM, a~proto byla celá krabička vytištěna na 3D tiskárně 
technologií SLA.

Technologie 3D tisku SLA byla využita i~pro označení barevných tlačítek. K~těmto tlačítkům byly nakresleny kalíšky, do kterých byly po vytisknutí kápnuty
kapky barevných resinů a~následně vytvrzeny. 

Krabička obsahuje také tzv.~stříšku, která je také součástí deskové hry. Tato stříška slouží pro zakrytí zadání ve hře pro dva hráče, kdy 
musí zadání svítit po celou dobu hry, aby byl druhý hráč schopen vyhodnocovat. Pro umístění stříšky slouží drážka ve vrchním dílu krabičky.

\begin{figure}[!h]
  \begin{center}
      
  \end{center}
  \caption[Spodní díl krabičky]{Spodní díl krabičky.}
  \end{figure}

  \begin{figure}[!h]
    \begin{center}
        
    \end{center}
    \caption[Vrchní díl krabičky]{Vrchní díl krabičky.}
    \end{figure}

\chapter{Kompletace} 
Do spodního dílu krabičky byly do všech otvorů zalepeny matice M3 pomocí vteřinového lepidla. Do vrchního otvoru byl nasunut kolébkový vypínač, který
není třeba přilepit. Ke kolébkovému vypínači byly připájeny krátké drátové propojky.  

Do vnitřních otvorů byla přišroubována DPS pomocí šroubů M3$\times$6 se zápustnou hlavou. Klasické šrouby mají hlavičku, která je moc vysoká a~krabička 
by nešla uzavřít. Zápustné šrouby jsou částečně zapuštěny do montážních otvorů DPS a~tím je část hlavičky šroubu nad DPS nižší. 

Po uchycení DPS byly drátové prodlužky od kolébkového vypínače zasunuty do otvorů v~DPS a~připájeny.

Krabička byla následně přikryta vrchním dílem a~přišroubována pomocí vnějších matic také šrouby M3$\times$6 se zápustnou hlavou. Ve vrchním dílu krabičky 
jsou otvory přizpůsobeny zápustným hlavám šroubů. Následně je možno zadání zakrýt stříškou, která se umisťuje do drážky ve vrchním dílu krabičky.
Po připojení jednoho z~USB konektorů k~napájecímu napětí je možno začít hrát.  

\begin{figure}[!h]
  \begin{center}
      
  \end{center}
  \caption[Složený výrobek]{Složený výrobek.}
  \end{figure}

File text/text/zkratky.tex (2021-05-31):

\cleardoublepage
\chapter*{\listofabbrevname}
\phantomsection
\addcontentsline{toc}{chapter}{\listofabbrevname}

\begin{acronym}[KolikMista]
%	\acro{A}
%		{Ampér (základní jednotka proudu)}
	\acro{Bd}
		{Baud - jednotka modulační rychlosti}
	\acro{C}
		{Kapacita}
	\acro{COM}
		{Common - sériový port RS-232}
	\acro{DPS}		
		{Deska plošného spoje}
	\acro{FDM}
		{Fused Deposition Modeling - technologie 3D tisku pomocí nanášení vrstev termoplastu}
	\acro{FLASH}
		{Typ paměti, která je trvalá - nesmaže se ani při ztrátě napájení}
	\acro{GND}
		{Ground - pin, který má nulový potenciál, vůči němu jsou referencované všechny ostatní signály}
	\acro{GPIO}
		{General Purpose Input/Output - piny, které mohou být vstupní nebo výstupní}
	\acro{kB}
		{Kilobajt - jednotka velikosti paměti}
%	\acro{}[k$\Omega$]
%		{Kiloohm (jednotka odporu)}	
	\acro{LDO}
		{Low-dropout regulator - regulátor napětí s nízkým úbytkem}
	\acro{LED}
		{Light-Emitting Diode - dioda emitující světlo}
	\acro{Li-Ion}
		{Lithium-iontový akumulátor - druh nabíjecí baterie}
%	\acro{mA}
%		{Miliampér (jednotka proudu)}
	\acro{mAh}
		{Miliampérhodina (jednotka kapacity používaná hlavně u~baterií)}
	\acro{MB}
		{Megabajt - jednotka velikosti paměti}
	\acro{MOSFET}
		{Metal Oxide Semiconductor Field Effect Transistor - tranzistor řízený elektrickým polem}	
	\acro{M3}
		{Metrický závit o~průměru 3~mm}
	\acro{RS-232}
		{Druh sériového komunikačního rozhraní} 
	\acro{RX}
		{Reciever - přijímač sériového rozhraní}
	\acro{SLA}
		{Stereolithography - technologie 3D tisku pomocí vytvrzování tekutého polymeru pomocí laserového záření}
	\acro{SMD}
		{Surface Mount Device - součástky určené pro povrchovou montáž} 
	\acro{SPI}
		{Serial peripheral interface - sériové periferní komunikační rozhraní}
	\acro{SRAM}
		{Static Random Acess Memory - rychlá statická paměť, která se smaže při ztrátě napájení}	
	\acro{THT}
		{Through-hole technology - vývodová technologie součástek}
	\acro{TX}
		{Transciever - vysílač sériového rozhraní} 
	\acro{USB}
		{Universal Serial Bus - univerzální sériová sběrnice, která se používá pro připojení zařízení k~počítači}
%	\acro{V}
%		{Volt (základní jednotka napětí)}
	\acro{VDD}
		{Označení napájecího napětí}

\end{acronym}

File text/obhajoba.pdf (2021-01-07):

Semestrální práce; Autor práce:; RENATA ZEMANOVÁ; Brno, 07. 01. 2021

Elektronická hra Logic

Vedoucí práce: doc. Ing. JIŘÍ HÁZE, Ph.D.

## Cíle práce

Nastudování pravidla
Návrh
Výroba
Testování
Ovládání hry
RENATA ZEMANOVÁ | Elektronická hra Logic | 1 / 11

## Pravidla


Respektování pravidel deskové hry Zadání kombinace barev v určitém pořadí
Vyhodnocení
Správná barva na správné pozici Správná barva na špatné pozici 10 pokusů

## Návrh elektroniky

Přenosné zařízení
Řídicí elektronika


Napájení
Měnič napětí
Převodník z USB na RS-232
Herní prvky
Ovládací prvky

## Herní prvky


WS2812C
RGB
Napájení
Princip spojení
Komunikace


## Návrh DPS


KiCad
JLCPCB
4 vrstvy

Vzhled
10 × 10 cm
3 části inteligentních LED

## Oživení


Osazení THT komponent
Vložení baterií do pouzdra LED indikující napájecí
napětí
Chybná pouzdra tranzistorů Tlačítko připojeno na
špatném pinu

## Způsob hry


## Plány do budoucna


Software
Konfigurace pro 2 hráče
Návrh a výroba krabičky
Jiné způsoby ovládání
Snížení spotřeby - závislost jasu inteligentních LED na okolním osvětlení

## Závěr


Pravidla
Návrh elektroniky
Návrh DPS
Oživení
Způsob hry

# Děkuji za pozornost!

Pravidla
Návrh elektroniky
Návrh DPS
Oživení
Způsob hry

## Použitá literatura

[1] Agátin svět: Dřevěná hra Logik Praha: [cit. 08. 12. 2020]. Dostupné z URL: <https://www.agatinsvet.cz/drevena-hra-logik/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>.
[2] JLCPCB: PCB Capabilities [cit. 23. 11. 2020]. Dostupné z URL: <https://jlcpcb.com/capabilities/Capabilities>.
[3] Satic Chipid: TP4056 A Standalone Linear Li-lon Battery Charger with Thermal Regulation in SOP-8 [cit. 03. 12. 2020]. Dostupné z URL: <https://static.chipdip.ru/lib/977/DOC002977110.pdf>.
[4] Worldsemi: WS2812C Poslední aktualizace 06. 12. 2017 [cit. 24. 11. 2020]. Dostupné z URL: <https://datasheet.lcsc.com/szlcsc/1810231210_Worldsemi-WS2812C_C114587.pdf>.

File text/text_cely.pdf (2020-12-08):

# VYSOKÉ UENÍ TECHNICKÉ V BRN

# Fakulta elektrotechniky a komunikaních technologií

# SEMESTRÁLNÍ PRÁCE

Brno, 2020 | Renata Zemanová

# VYSOKÉ UENÍ TECHNICKÉ V BRN

BRNO UNIVERSITY OF TECHNOLOGY

# FAKULTA ELEKTROTECHNIKY A KOMUNIKANÍCH TECHNOLOGIÍ

FACULTY OF ELECTRICAL ENGINEERING AND COMMUNICATION

# ÚSTAV MIKROELEKTRONIKY

DEPARTMENT OF MICROELECTRONICS

# ELEKTRONICKÁ HRA LOGIC

ELECTRONIC GAME LOGIC

## SEMESTRÁLNÍ PRÁCE

SEMESTRAL THESIS

## AUTOR PRÁCE

AUTHOR

## Renata Zemanová

## VEDOUCÍ PRÁCE

SUPERVISOR

doc. Ing. Jií Háze, Ph.D.

## BRNO 2020

Fakulta elektrotechniky a komunikaních technologií, Vysoké uení technické v Brn / Technická 3058/10 / 616 00 / Brno

# Semestrální práce

bakaláský studijní program Mikroelektronika a technologie

Ústav mikroelektroniky
Studentka: Renata Zemanová | ID: 211251
Roník: | 3 | Akademický rok: 2020/21

NÁZEV TÉMATU:

### Elektronická hra Logic

POKYNY PRO VYPRACOVÁNÍ:
Seznamte se s principem hry Logic. Navrhnte a realizujte elektronickou verzi této hry s rznými úrovnmi obtínosti a v praxi ovte funknost vaeho eení.

DOPORUENÁ LITERATURA:
Podle pokyn vedoucího práce
Termín zadání: | 21.9.2020 | Termín odevzdání: 18.12.2020
Vedoucí práce: | doc. Ing. Jií Háze, Ph.D.

doc. Ing. Jií Háze, Ph.D. pedseda rady studijního programu

UPOZORNNÍ:
Autor semestrální práce nesmí pi vytváení semestrální práce poruit autorská práva tetích osob, zejména nesmí zasahovat nedovoleným zpsobem do cizích autorských práv osobnostních a musí si být pln vdom následk poruení ustanovení § 11 a následujících autorského zákona . 121/2000 Sb., vetn moných trestnprávních dsledk vyplývajících z ustanovení ásti druhé, hlavy VI. díl 4 Trestního zákoníku .40/2009 Sb.

# Obsah

Úvod | 11
1 Pravidla hry | 13
2 Návrh elektroniky | 15
3 Návrh DPS | 27
4 Oživení DPS | 29
5 Způsob ovládání elektronické hry | 31
Závěr | 33
Literatura | 35
Seznam symbolů, veličin a zkratek | 37
Seznam příloh | 39

# Seznam obrázků

2.1 Blokové schéma zapojení verze 0.0 | 15
2.2 Blokové schéma zapojení verze 1.0 | 15
2.3 Schéma zapojení modulu ESP32-PICO | 17
2.4 Pouzdro na baterie 18650 | 17
2.5 Schéma zapojení čipu TP4056 | 18
2.6 Schéma zapojení čipu SY8105 | 20
2.7 Schéma zapojení převodníku z USB na RS-232 | 21
2.8 Zapojení LED pro indikaci komunikace čipu CP2102 s modulem ESP32-
PICO | 22
2.9 Zapojení inteligentních LED WS2812C | 22
2.10 Obvod pro zapínání napájení pro inteligentní LED | 24
2.11 Zapojení tlačítek | 24
2.12 Zapojení LED pro indikaci napájecího napětí | 25
3.1 Rozložení součástek kolem čipu SY8105 na DPS | 28

# Seznam tabulek

2.1 Nastavení nabíjecího proudu rezitorem R13 [11] | 19
2.2 Parametry čipu SY8105 [12] | 20
2.3 Parametry čipu CP2102 [13] | 21
2.4 Parametry inteligentních LED WS2812C [14] | 23

# Úvod

Cílem této práce je vytvořit elektronickou hru Logic. Tato hra by se měla co nejvíce podobat deskové hře a měla by respektovat pravidla deskové hry.
Hra musí být navržena jako přenosné zařízení, takže musí být kladen důraz na spotřebu jednotlivých použitých komponentů.
V této práci je popsán návrh elektronické hry. Na začátku jsou popsána pravidla deskové hry, která jsou respektována i u elektronické hry. Elektronická hra Logic je tvořena DPS, která obsahuje veškeré potřebné komponenty pro funkci hry.
V práci je také odůvodněno použití veškerých komponentů a jejich rozmístění na DPS.
Na závěr je popsán způsob elektronické hry a její ovládání.

# 1 Pravidla hry

Hra Logic je desková hra pro dva hráče [6]. Jeden hráč určí hledanou kombinaci, dále bude označován jako hráč A, a druhý tuto kombinaci za pomoci logických úvah a vyhodnocení hráčem A hledá, dále bude označován jako hráč B.
Hráči si určí herní pozice. Hráč A vybere barevné kolíky dle libosti a následně je v určitém pořadí vloží do zadávacího pole. Zadání zakryje stříškou, aby tuto kombinaci spoluhráč neviděl. Hráč B se v tuto chvíli nedívá. Hráč B následně zvolí náhodnou kombinaci barev a jejich pozic. Po ukončení tahu nechá hráče A, aby jeho tah vyhodnotil. Hráč A vyhodnotí tah následujícím způsobem. Pokud hráč B vložil správnou barvu na správnou pozici, tak vloží do vyhodnocovací sekce černý kolík. Pokud vložil barvu, která se v zadání vyskytuje, ale vložil ji na nesprávnou pozici, tak vloží bílý kolík. Pokud zůstanou některé pozice neobsazené, tak to znamená, že se dané barvy v zadání nevyskytují. Vyhodnocovací kolíky umisťuje od kraje, nejprve černé a pak bílé, aby hráči B nebylo jasné, kterých hracích kolíků se vyhodnocení týká [6]. Poté začne hráč B na základě vyhodnocení a svých všech předchozích tahů hledat správnou kombinaci.
Hráč B má maximálně 10 pokusů na zjištění správné kombinace. Po skončení hry hráč A odkryje stříšku a ukáže hledanou kombinaci. Hra skončí po určení správné kombinace, nebo po vypotřebování všech pokusů.
Hru lze hrát ve více variantách. Hráči se mohou domluvit, zda zadání může, nebo nesmí obsahovat volnou pozici. Zároveň existuje více variací této hry. Většinou se liší v délce hledané kombinace.

# 2 Návrh elektroniky

Již byly navrženy 2 verze DPS elektronické hry Logic. Verze 0 byla pouze testovací, takže neobsahovala celé herní pole. Sloužila pro ověření funkčnosti daných zapojení různých čipů a zároveň pro testování softwaru.


Obr. 2.1: Blokové schéma zapojení verze 0.0.


Obr. 2.2: Blokové schéma zapojení verze 1.0.

Asi největším rozdílem mezi verzí 0 a 1 je způsob napájení. Verze 0 je napájena z baterií a verze 1 je napájena z USB. Díky této změně odpadly i mnohé části obvodu. Díky absenci baterií bylo možné postrádat nabíjecí obvody, ochranu proti přepólování a měření napětí na bateriích.

## 2.1 Řídicí elektronika

Jako řídicí elektronika byl vybrán modul ESP32-PICO-D4. Hlavním důvodem pro výběr tohoto modulu bylo, že je téměř totožný jako ESP32-WROOM, se kterým mám dlouhodobé zkušenosti. Tento modul má veškeré periferie, které jsou pro výrobu této hry zapotřebí.
Modul ESP32-PICO také podporuje Arduino framework, díky kterému bude programování značně zjednodušeno.
Modul ESP32-PICO obsahuje [2]:
- WiFi,
- Bluetooth,
- 32 GPIO pinů,
- dvoujádrový 32bitový procesor Xtensa LX6,
- 520 kB SRAM,
- 16 MB FLASH.

Napájecí napětí tohoto modulu je od 3,0 do 3,6 V a průměrný odběr proudu je 80 mA [2]. ESP32-PICO má vyvedeno 32 GPIO pinů, které je možno softwarově nastavit jako vstupní nebo výstupní. Na tyto piny lze poté připojit různá zařízení. Vstupním senzorem může být typicky tlačítko a výstupním indikátorem např. LED. Tato zařízení zprostředkovávají komunikaci mezi modulem a okolním světem. GPIO piny IO16 a IO17 nemohou být použity, protože ESP32-PICO má na těchto pinech připojenou flash paměť [2]. Pokud by na tento pin bylo připojeno nějaké zařízení, tak by modul ztratil přístup ke své paměti.
GPIO piny IO34 a vyšší jsou pouze vstupní [2]. Vstupní piny nemají softwarově zapojitelný pullup rezistor. Pokud je tedy zapotřebí pullup rezistor, musí se fyzicky zapojit.

## 2.2 Napájení

V následujících kapitolách jsou rozebrány způsoby napájení obou vyrobených verzí DPS elektronické hry Logic.

### 2.2.1 Verze 0.0

V první verzi byly pro napájení použity baterie Li-Ion INR18650-29E od firmy Samsung. Tyto baterie mají jmenovité napětí 3,7 V, při plném nabití až 4,2 V. Kapacita jedné baterie je 2850 mAh [8]. Byly použity 2 články baterií, které byly zapojeny paralelně. Paralelním zapojením se celková kapacita zdvojnásobila.


Obr. 2.3: Schéma zapojení modulu ESP32-PICO [2].

Baterie typu Li-Ion jsou náchylné na podvybití. Verze 0.0 proto obsahovala i měření napětí na bateriích. Pokud by došlo k podvybití, mohla by se bateriím zmenšovat kapacita, nebo by se mohly zničit.
Pro baterie bylo vybráno pouzdro na 2 články s THT montáží do DPS [9].


Obr. 2.4: Pouzdro na baterie 18650 [9].

Baterie byly připevněny a zapájeny přímo do DPS a proto musel být integrován i nabíjecí obvod. Nabíjení probíhalo přes konektor USB Micro.

Pro nabíjecí obvod byl zvolen čip TP4056. Tento obvod byl vybrán, protože je přímo určen pro nabíjení baterií typu Li-Ion. Existují moduly pro nabíjení těchto baterií, které mají integrovaný tento čip [7]. Tyto moduly jsou často používané, a proto bylo zapojení tohoto modulu převzato do této práce.

Vlastnosti čipu jsou přizpůsobeny bateriím Li-Ion. Nabíjení baterií probíhá do 4,2 V, což je maximální napětí na použitých bateriích [8] [11]. Díky tomu nemůže dojít ke zničení baterií nabíjením.


Obr. 2.5: Schéma zapojení čipu TP4056 [11].

Červená LED D9 indikuje nabíjení baterií a zelená LED D8 svítí, pokud jsou

baterie nabité [11]. Pokud nesvítí ani červená ani zelená LED, znamená to, že baterie jsou podvybité, baterie nejsou vloženy a nebo je příliš vysoká, nebo nízká jejich teplota [11].

Rezistorem R13 se určuje nabíjecí proud baterií [11]. Aby baterie nabíjením nebyly poškozovány, měl by být nabíjecí proud maximálně 0,5 C (polovina kapacity baterie). Vybraná baterie má kapacitu 2850 mAh. Nabíjecí proud proto může být až 1425 mA. Jelikož je pro tuto hru důležitější kapacita baterie, než doba nabíjení, byl zvolen nabíjecí proud pouze 0,5 A. Čím menším proudem je baterie nabíjena,

tím má delší životnost a pomaleji ztrácí svoji kapacitu.

Byl zvolen rezistor o hodnotě 2 kΩ, kterým byl určen nabíjecí proud 580 mA.

Tab. 2.1: Nastavení nabíjecího proudu rezitorem R13 [11].

R13 [kΩ] | Nabíjecí proud [mA]
10 | 130
5 | 250
4 | 300
3 | 400
2 | 580
1,66 | 690
1,5 | 780
1,33 | 900
1,2 | 1000

### 2.2.2 Verze 1.0

Ve verzi 1.0 byl změněn způsob napájení. Napájení v této verzi neprobíhá přes baterie, ale pouze přes USB konektor, přes který ve verzi 0.0 probíhalo pouze nabíjení baterií.

Výhody

- absence drahých baterií,
- absence nabíjecího obvodu,
- absence hlídání stavu nabití baterie,
- absence ochrany proti přepólování (USB konektor je uzpůsoben svým tvarem, aby uživatel nemohl napájení přepólovat.),
- napájení inteligentních LED napětím přímo z USB (Inteligentní LED mají menší odběr proudu.).

Nevýhody

- předpokládá se, že uživatel vlastní powerbanku,
- výdrž závisí na kapacitě powerbanky.

Byl zvolen konektor USB Micro, protože se jedná o nejrozšířenější USB konektor dnešní doby.

## 2.3 Snižující měnič napájecího napětí pro řídicí modul

Modul ESP32-PICO má napájecí napětí 3,3 V. Napětí z powerbanky přes USB je 5
V. Proto je tedy zapotřebí zapojit měnič pro snížení napětí, který bude vytvářet z napájecího napětí 5 V napájecí napětí 3,3 V pro modul ESP32-PICO.

Jako měnič byl zvolen čip SY8105. Tento čip byl vybrán podle projektu RB0005-UniversalStepDown [10]. V tomto projektu zapojení funguje bezproblémově, a proto bylo rozhodnuto toto zapojení použít v mé práci.


Obr. 2.6: Schéma zapojení čipu SY8105 [12] [10].

V tomto projektu existují varianty pro stabilizaci na výstupu pro 5 V a pro 3,3 V. Z poznámek v projektu RB0005-UniversalStepDown vyplývá, že výstupní napětí je závislé na poměru rezistorů R11 a R12. Rezistory byly zvoleny pro výstupní napětí 3,3 V a přepočítány, aby byl zachován jejich poměr, ale aby byly použity rezistory ze standardní rezistorové řady.

Tab. 2.2: Parametry čipu SY8105 [12]

Vstupní napětí | 4,5 - 18 V
Maximální výstupní proud | 5 A

## 2.4 Převodník z USB na RS-232

Modul ESP32-PICO používá jako komunikační rozhraní linku RS-232. Programování ale probíhá přes USB konektor, který toto rozhraní nemá. Proto bylo potřeba použít převodník z USB na rozhraní RS-232.
Velkou inspirací při výběru součástek byl kit ESP32-DEVKITC [1]. Tento kit obsahuje ESP32-WROOM a také převodník z USB na RS-232. Na tomto kitu je převodník realizován čipem CP2102. ESP32-WROOM a ESP32-PICO se liší pouze v drobnostech, a proto byl převodník CP2102 použit i při návrhu převodníku u elektronické hry Logic. Tento čip zároveň převádí logiku z 0 - 5 V na logiku 0 - 3,3 V [13].

Tab. 2.3: Parametry čipu CP2102 [13]

Typický odběr proudu | 9,5 mA
Napájecí napětí | 3 - 3,6 V

Čip CP2102 dokáže komunikovat vekým množstvím komunikačních rychlostí

(300, 9600, 19200, 38400, 115200, 256000 Bd, atd) [13]. PC započne komunikaci určitou rychlostí a tento čip tuto komunikaci zachytí, určí rychlost a touto rychlostí začne probíhat programování.


Obr. 2.7: Schéma zapojení převodníku z USB na RS-232 [1].

Z USB jsou signály D+ a D- připojeny k čipu CP2102. Tento čip signál z USB převede na signály RX a TX, které mají výstup na pinech RXD a TXD. Následně jsou tyto signály připojeny k modulu ESP32-PICO. Signály RX a TX musí být překříženy – RX CP2102 je připojeno na TX ESP32-PICO a TX CP2102 je připojeno na RX ESP32-PICO.

LED D10 a D11 slouží k indikaci komunikace s modulem ESP32-PICO. Pokud je do modulu nahráván program, tak LED D10 a D11 blikají.


Obr. 2.8: Zapojení LED pro indikaci komunikace čipu CP2102 s modulem ESP32-PICO [13].

## 2.5 Herní prvky

Herními prvky elektronické hry Logic jsou inteligentní LED typu WS2812C. Tento typ inteligentních LED je určen pro přenosná zařízení díky jejich nízké spotřebě. Jsou také plně kompatibilní s typem WS2812B [14]. K těmto inteligentním LED existují knihovny, které usnadňují softwarovou práci s nimi.

Každá inteligentní LED má v sobě procesor, který slouží pro zpracování dat. Inteligentní LED WS2812C se zapojují za sebou přes piny DATA IN a DATA OUT. Každá inteligentní LED převezme data z pinu DATA IN, která jsou pro ni určena, a zbytek pošle ven přes pin DATA OUT.


Obr. 2.9: Zapojení inteligentních LED WS2812C [14].

Ke každé inteligentní LED je připojen na napájení filtrační kondenzátor [14], aby LED svítily kontinuálně a nedostal se jim na napájení žádný šum.

Tab. 2.4: Parametry inteligentních LED WS2812C [14]

Napájecí napětí | 3,5 - 5,3 V
Výstupní napětí | (VDD - 0,5) - (VDD + 0,5) V
Typický odběr proudu | 5 mA
Klidový odběr proudu | 0,3 mA

### 2.5.1 Rozdělení

Inteligentní LED jsou rozděneny do tří skupin. Skupina inteligentních LED pro zadání, skupina inteligentních LED pro herní pole a skupina inteligentních LED pro zobrazení vyhodnocení tahu. Skupina inteligentních LED pro zadání obsahuje 4 LED a skupiny pro herní pole a pro vyhodnocení každá 40 LED.

### 2.5.2 Zapínání napájení

DPS je navrhována pro přenosnou aplikaci, a proto je potřeba zajistit její co nejnižší odběr.
Inteligentní LED WS2812C mají spotřebu 0,3 mA, i když zrovna nesvítí žádnou barvou. Proto je herní pole dohromady s vyhodnocovacími LED rozděleno na 3 části. Do první části patří inteligentní LED se zadáním a první 4 čtveřice inteligentních LED z herního pole a z vyhodnocení. Do druhé části patří další 3 čtveřice inteligentních LED z herního pole a z vyhodnocení. Do třetí části patří poslední 3 čtveřice inteligentních LED z herního pole a z vyhodnocení.
Těmto 3 částem je postupně zapínáno napájecí napětí. Každé části se zapne napájení až pokud se hráč dostane do fáze, kdy danou oblast potřebuje. K zapínání dochází softwarově spínáním GPIO pinem řídicího modulu ESP32-PICO.
Ke spínání slouží obvody s MOSFET tranzistory. MOSFET tranzistory byly zvoleny pro jejich nulovou spotřebu, narozdíl od bipolárních tranzistorů.

Napájení inteligentních LED nelze spínat pouze jedním tranzistorem, protože logická 1 modulu ESP32-PICO má hodnotu 3,3 V, ale je zapotřebí spínat 5 V. Pokud by byl pro spínání použit pouze jeden tranzistor, tak by bylo napájení vždy sepnuto.
GPIO pin modulu ESP32-PICO je nastaven do logické 0, dokud není potřebné přivedení napájecího napětí dané skupině. Při logické nule na gate tranzistoru Q4 je tranzistor zavřený. Tranzistor Q5 v tomto okamžiku drží zavřený rezistor R15. Když je GPIO pin modulu ESP32-PICO přepnut do logické 1, tak se tranzistor Q4 otevře. Otevřením tranzistoru Q4 je gate tranzistoru Q5 připojen ke GND


Obr. 2.10: Obvod pro zapínání napájení pro inteligentní LED.

a tím se otevře i tranzistor Q5, kterým je sepnuto napájecí napětí dané skupině inteligentních LED.
Rezistor R14 udržuje tranzistor Q4 zavřený při nestandardních stavech pinu modulu ESP32-PICO, jako je např. při resetu procesoru.

## 2.6 Spínací prvky

Přepínač SW1 slouží pro zapínání celé DPS. Tento přepínač připojuje napájecí napětí 5 V z USB k celému zbytku DPS.
Tlačítka slouží pro ovládání hry. Ke každému tlačítku je připojen kondenzátor o hodnotě 100 nF. Tento kondenzátor slouží pro filtraci zákmitů při zmáčknutí tlačítka. Filtrace se proto nemusí řešit softwarově.


Obr. 2.11: Zapojení tlačítek.

## 2.7 Indikace přítomnosti napájecího napětí

Pro indikaci přítomnosti napájecího napětí slouží LED D1 a D2. LED D1 indikuje přítomnost napájecího napětí 5 V a LED D2 indikuje přítomnost napájecího napětí 3,3 V. Obě LED mají zelenou barvu.


Obr. 2.12: Zapojení LED pro indikaci napájecího napětí.

# 3 Návrh DPS

DPS je navržena v programu KiCad a její parametry jsou určeny pro výrobu i osazení ve firmě JLCPCB [3] [4]. Výrobní podklady proto musely být navrženy v souladu s jejich výrobními možnostmi [5].
DPS má 4 vrstvy. Vnitřní vrstvy slouží pro napájení a vnější pro signálové dráhy. V jedné vnitřní vrstvě je po celé její ploše polygon GND a ve druhé vnitřní vrstvě jsou polygony jednotlivých napájecích napětí.
Na vrchní straně jsou umístěny plošky pro osazení SMD součástek, protože firma JLCPCB osazuje pouze SMD součástky a pouze z jedné strany. THT součástky jsou připraveny na ruční pájení.
Signálové dráhy jsou vedeny tenkou dráhou a napájecí dráhy jsou vedeny širší dráhou. V signálových drahách tečou zanedbatelné proudy, proto mohou být co nejtenčí. Výrobce umožňuje vyrobit u čtyřvrstvé DPS nejtenčí dráhu 0,09 mm [5]. Aby nebyly použity krajní hodnoty, byla zvolena šířka signálové dráhy 0,150 mm.

## 3.1 Vzhled DPS

Vzhled této DPS byl ovlivněn vzhledem deskové hry a výrobními možnostmi firmy JLCPCB. Firma JLCPCB vyrábí DPS o maximálních rozměrech 10×10 cm [4]. Tato DPS tedy byla navržena na maximální vyrobitelnou velikost a poté byly do těchto rozměrů rozmisťovány součástky.
Nejprve byly na DPS rozloženy inteligentní LED. Jejich rozmístění je důležité, pro za zachování podobnosti deskové hře. Zároveň díky jejich množství a poměrně velkým rozměrům (5×5 mm) zabírají velkou část DPS [14]. Proto musely být inteligentní LED rozmístěny jako první. Následně byl ostatními obvody využíván zbylý prostor.
Dráhy s napájecím napětím by měly být vedeny co nejvíce zpříma. Proto musely být součástky se stejným napájecím napětí sdruženy u sebe. Díky tomu mohlo být napájení tvořeno polygony. Dílčí obvody byly rozmístěny v následujícím pořadí -USB, měnič napětí, převodník z USB na RS-232 a ESP332-PICO. USB konektor musel být umístěn na okraj DPS. Proto byly jednotlivé části obvodu naskládány podél levého okraje DPS.
V pravém horním rohu vzniklo prázdné místo, které bylo využito pro popis DPS.

## 3.2 Funkční rozmístění součástek

U některých součástek není jejich umístění na DPS lhostejné. Rozmístění součástek často ovlivňuje funkčnost obvodu. Rozmístění součástek často souvisí s rozkreslením ve schématu. Například kondenzátory filtrující napájení se umisťují co nejblíže přívodu napájení.
Inteligentní LED WS2812C jsou rozděleny do 3 skupin, aby se hra co nejvíce podobala deskové hře. Inteligentní LED pro zadání jsou v horní části DPS. V levém sloupci pod zadáním jsou inteligentní LED, které slouží jako herní pole, a v pravém sloupci jsou inteligentní LED pro vyhodnocení tahu. Každá inteligentní LED musí mít svůj filtrační kondenzátor na napájení co nejblíže svému pouzdru.
Rozložení součástek měniče napětí na DPS může velmi ovlivnit jeho funkčnost. Proto bylo rozložení a zapojení součástek převzato z datasheetu.


Obr. 3.1: Rozložení součástek kolem čipu SY8105 na DPS [12].

Signály D+ a D- od USB k čipu CP2102 jsou diferenciální pár, a proto tomu musely být přizpůsobeny i dráhy těchto signálů. Dráhy jsou vedeny vedle sebe a blízko u sebe.
Kondenzátory u modulu ESP32-PICO a u čipu CP2102 musí být umístěny co nejblíže jejich pouzdru. Tyto kondenzátory slouží pro filtraci šumu na napájení. Kondenzátory u tlačítek jsou také umístěny co nejblíže pouzdru tlačítek. Čím

blíže pouzdru kondenzátor bude, tím lépe budou filtrovány zákmity při stisku tlačítka.

# 4 Oživení DPS

Následující kapitola popisuje oživení obou verzí DPS poté, co přijdou z výroby.

## 4.1 Verze 0.0

DPS přijde z výroby ve stavu, kdy jsou osazeny pouze SMD komponenty.
Po dodání DPS z výroby byly zapájeny THT komponenty (pouzdro na baterii, konektor USB micro, tlačítka a vypínač). Po zapojení baterií 18650 do pouzdra a zapnutí vypínače se rozsvítí zelená LED D1, která indikuje přítomnost napájecího napětí. Po připojení k počítači přes USB konektor se rozsvítí LED D9 nebo LED D8. LED D9 signalizuje nabíjení baterií a LED D8, signalizuje, že baterie jsou nabité.

## 4.2 Verze 1.0

DPS přijde z výroby ve stavu, kdy jsou osazeny pouze SMD komponenty.
Poté je nutné ručně osadit THT součástky, tj. vypínač, tlačítka a konektor USB micro. Po připojení DPS přes USB konektor k powerbance, nebo do počítače, se rozsvítí LED D1 a D2, které indikují přítomnost napájecího napětí. LED D2 zároveň značí, že zapojení měniče napětí je funkční.

# 5 Způsob ovládání elektronické hry

Tato verze hry je navržena jako hra pro jednoho hráče. Funkci druhého hráče nahrazuje řídicí modul ESP32-PICO.
Po zapnutí DPS stikneme tlačítko "Nová hra". V této chvíli se vygeneruje zadání, které není vidět, a první herní LED se rozbliká. Rozblikání herní LED značí pozici kurzoru. Kurzorem lze pohybovat pomocí tlačítek "Šipka vpravo"a "Šipka

vlevo". Barvy herních LED se nastavují tlačítky ve spodní části DPS. Tato tlačítka jsou označena danými barvami. Po zadání kombinace stiskneme tlačítko "Potvrdit tah". Po stisku tlačítka proběhne vyhodnocení a to se zobrazí na vyhodnocovacích LED. Kurzor se posune na první LED v dalším řádku. Po zadání správné kombinace barev a jejich pozic se rozsvítí zadání a hra je u konce. Pro novou hru stiskneme tlačítko "Nová hra"a pro ukončení tlačítko "Konec". Po stisku tlačítka "Konec"zhasnou všechny herní, vyhodnocovací LED i LED pro zadání. Poté je DPS připravena pro vypnutí vypínačem.

# Závěr

Byla navržena elektronická hra Logic. Tato hra vychází z původní deskové hry.
V této práci byla uvedena pravidla deskové hry Logic. Dále byl popsán kompletní návrh elektronické verze této hry.
Byla navržena DPS, která obsahuje veškeré potřebné komponenty pro funkci elektronické hry Logic.
Při návrhu je kladen velký důraz na vizuální podobu s deskovou hrou Logic.
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

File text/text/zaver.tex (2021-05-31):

\chapter*{Závěr}
\phantomsection
\addcontentsline{toc}{chapter}{Závěr}

Byla navržena Elektronická hra Logic. Tato hra vychází ze stejnojmenné deskové hry.

V~této práci byla uvedena pravidla deskové hry Logic. Dále byl popsán kompletní návrh elektronické verze této hry. Při výběru elektronických 
komponent byl kladen důraz na spotřebu jednotlivých zařízení. Hru řídí mikrokontrolér ESP32-PICO. Herními prvky jsou inteligentní LED WS2812C, 
které jsou programovatelné a~jsou určeny pro přenosná zařízení. Hra Logic je integrována do jedné DPS, která řídí hru, a~zároveň jsou na této 
DPS umístěny herní prvky. Finální verze DPS obsahuje také měnič napětí, převodník z~USB na RS-232 a~převodníky úrovně. Napájení probíhá pomocí
USB konektorů.

Při návrhu je kladen velký důraz na vizuální podobu s~deskovou hrou Logic. Zároveň byla také zachována veškerá doporučená zapojení použitých 
čipů a~modulů a~rozmístění součástek na DPS.

V~neposlední řadě je stručně popsán vývoj od prvního prototypu až po finální verzi DPS. 

V~této práci je také popsáno softwarové řešení Elektronické hry Logic, včetně popisu funkce automatického vyhodnocení ve hře pro jednoho hráče.
Následuje popis ovládání Elektronické hry Logic, který je rozdělen na možnosti hry pro jednoho nebo pro dva hráče. 

Byla navržena a~vyrobena krabička. Tato krabička má všechny potřebné otvory a~DPS z~ní nemusí být nikdy vytahována. Obsahuje také stříšku pro
zakrytí zadání potřebnou ve hře pro dva hráče.

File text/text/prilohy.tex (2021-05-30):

\chapter{Blokové schéma zapojení DPS finální verze}

\begin{figure}[!h]
    \begin{center}
      
    \end{center}
    \caption[Blokové schéma DPS finální verze]{Blokové schéma DPS finální verze.}
  \end{figure}

\includepdf[pages=1]{prilohy/cele}

\includepdf[pages=1]{prilohy/Stepdown_ESP}

\includepdf[pages=1]{prilohy/USBto232}

\includepdf[pages=1]{prilohy/zapinani_LEDek}

\includepdf[pages=1]{prilohy/LEDky40}

\includepdf[pages=1]{prilohy/LEDky4}

\includepdf[pages=1]{prilohy/tlacitka}

\chapter{Výrobní podklady DPS finální verze}

  \begin{figure}[!h]
    \begin{center}
      
    \end{center}
    \caption[Vrstva mědi TOP]{Vrstva mědi TOP.}
  \end{figure}

  \begin{figure}[!h]
    \begin{center}
      
    \end{center}
    \caption[Vnitří vrstva mědi napájení]{Vnitří vrstva mědi napájení.}
  \end{figure}

  \begin{figure}[!h]
    \begin{center}
      
    \end{center}
    \caption[Vnitří vrstva mědi GND]{Vnitří vrstva mědi GND.}
  \end{figure}
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

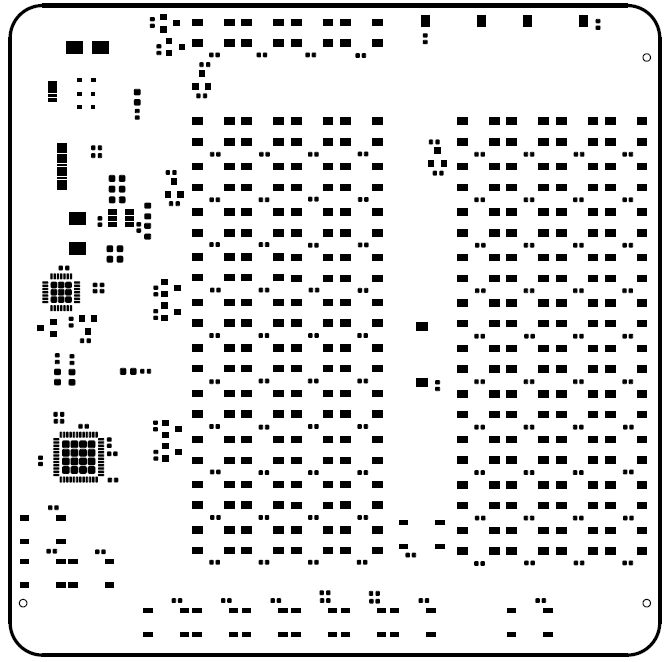
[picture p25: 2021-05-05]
text/prilohy/Verze2_pasta_TOP.png

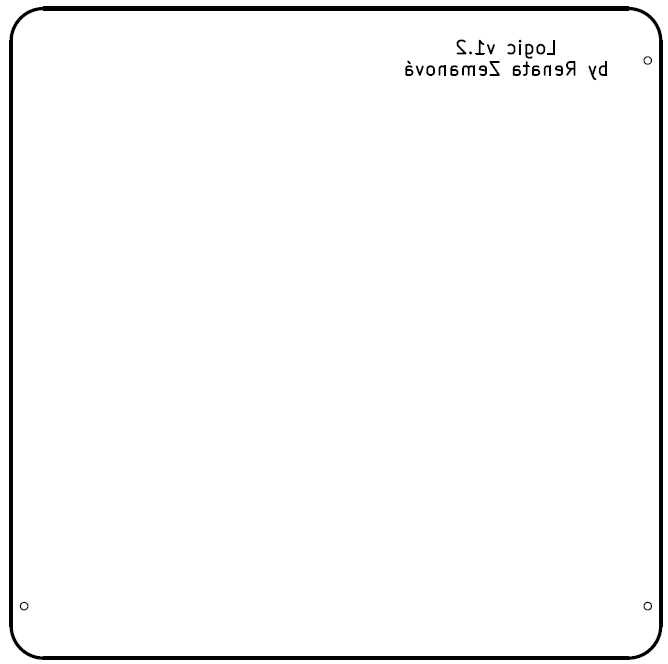
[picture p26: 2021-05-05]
text/prilohy/Verze2_vrstva_popisky_BOTTOM.png

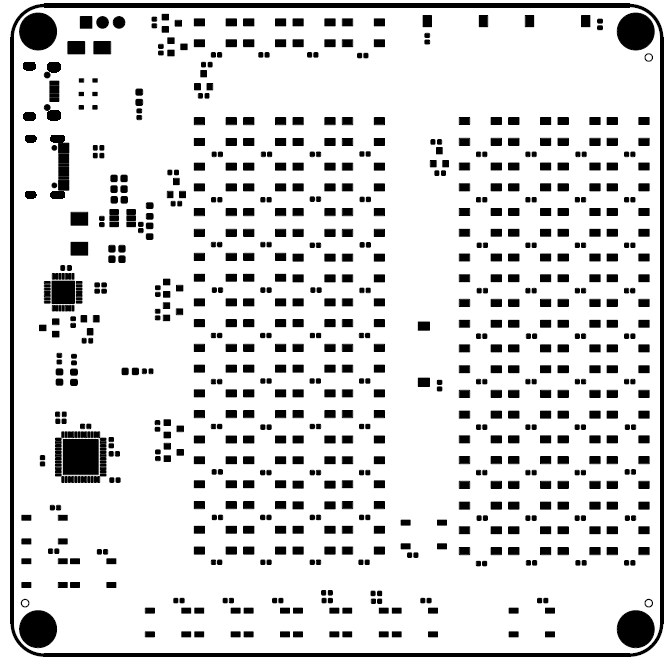
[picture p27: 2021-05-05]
text/prilohy/Verze2_maska_TOP.png

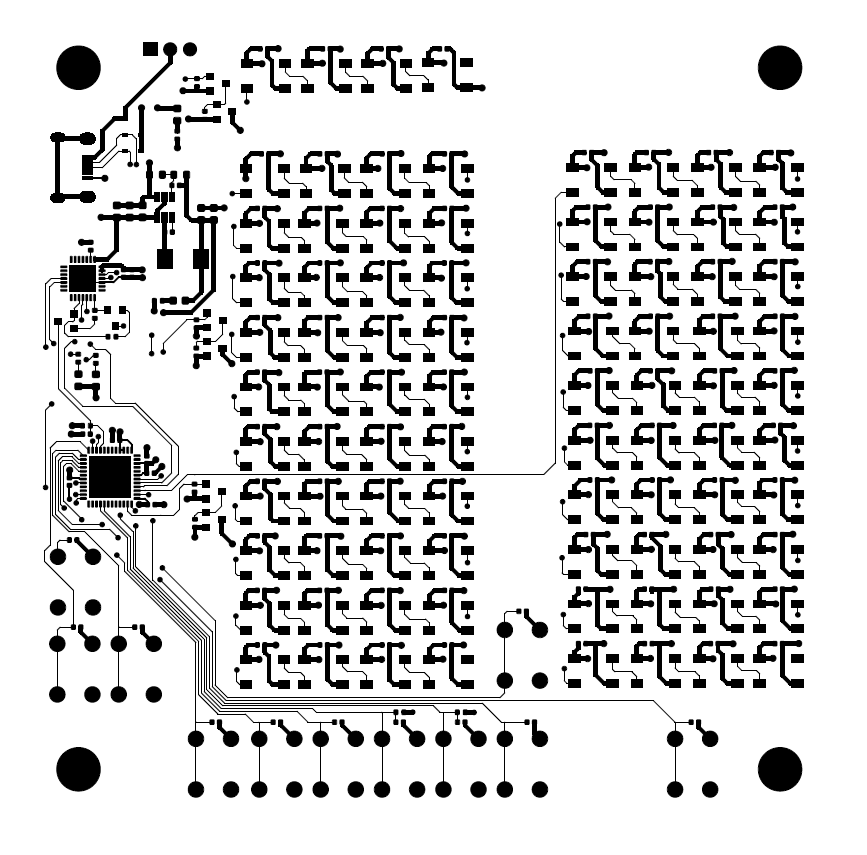
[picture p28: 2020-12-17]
text/prilohy/Verze1_vrstva_Cu_TOP.png

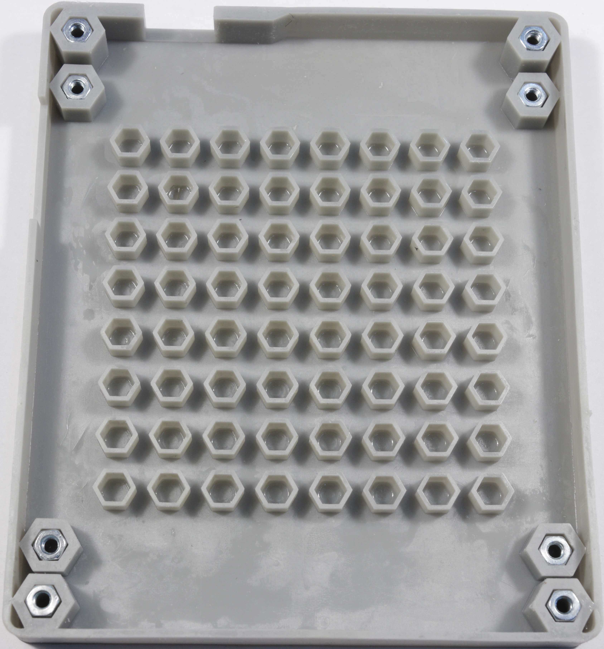
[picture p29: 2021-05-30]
text/prilohy/Krabicka_spodek_matice.jpg

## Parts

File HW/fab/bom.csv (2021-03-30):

Comment | Designator | Footprint | LCSC
ESP32-PICO-D4 | U1 | Package_DFN_QFN:QFN-48-1EP_7x7mm_P0.5mm_EP5.3x5.3mm | C193707
10k | R1,R2,R3,R5,R4,R21,R22,R13,R20,R23,R24,R28,R27,R29,R6,R7,R10,R8,R9 | Resistor_SMD:R_0402_1005Metric | C25744
H | C1 | Capacitor_SMD:C_0402_1005Metric | C52923
10u | C4,C22 | Capacitor_SMD:C_0402_1005Metric | C15525
100n | C6,C3,C2,C5,C7,C8,C9,C10,C23,C27,C31,C34,C32,C33,C35,C38,C36,C37,C39,C42,C40,C41,C43,C46,C44,C45,C47,C50,C48,C49,C51,C54,C52,C53,C55,C58,C56,C57,C59,C62,C60,C61,C63,C66,C64,C65,C67,C70,C68,C69,C71,C74,C72,C73,C75,C78,C76,C77,C79,C82,C80,C81,C83,C86,C84,C85,C87,C90,C88,C89,C91,C94,C92,C93,C95,C98,C96,C97,C99,C102,C100,C101,C103,C106,C104,C105,C107,C110,C108,C109 | Capacitor_SMD:C_0402_1005Metric | C1525
green | D1,D2,D10,D11 | LED_SMD:LED_0603_1608Metric | C72043
DIODE | D92 | Diode_SMD:D_SMA | C8678
Q_NMOS_GSD | Q10,Q3,Q11,Q4,Q6,Q8 | Package_TO_SOT_SMD:SOT-23 | C8545
SW_SPST | SW13,SW14,SW15 | my_library:DIP1x1 | C54948
WS2812C | D3,D4,D5,D6,D13,D15,D12,D14,D17,D19,D16,D18,D21,D23,D20,D22,D25,D27,D24,D26,D29,D31,D28,D30,D33,D35,D32,D34,D37,D39,D36,D38,D41,D43,D40,D42,D45,D47,D44,D46,D49,D51,D48,D50,D53,D55,D52,D54,D57,D59,D56,D58,D61,D63,D60,D62,D65,D67,D64,D66,D69,D71,D68,D70,D73,D75,D72,D74,D77,D79,D76,D78,D81,D83,D80,D82,D85,D87,D84,D86,D89,D91,D88,D90 | LED_SMD:LED_WS2812B_PLCC4_5.0x5.0mm_P3.2mm | C114587
10n | C11,C16,C17,C19,C18,C14,C12,C21,C20,C15,C13 | Capacitor_SMD:C_0402_1005Metric | C15195
button | SW7,SW8,SW10,SW9,SW5,SW3,SW12,SW11,SW6,SW4,SW2 | my_library:Tactile_switch | C318886
CP2102N-A01-GQFN28 | U2 | Package_DFN_QFN:QFN-28-1EP_5x5mm_P0.5mm_EP3.35x3.35mm | C6568
Q_NPN_BEC | Q2,Q1 | Package_TO_SOT_SMD:SOT-23 | C20526
USB_C_Receptacle_USB2.0 | J2 | Connector_USB:USB_C_Receptacle_HRO_TYPE-C-31-M-12 | C165948
5k1 | R25,R26 | Resistor_SMD:R_0402_1005Metric | C25905
22u | C24,C25,C26,C29,C30 | Capacitor_SMD:C_0603_1608Metric | C59461
160k | R11 | Resistor_SMD:R_0603_1608Metric | C22813
36k | R12 | Resistor_SMD:R_0603_1608Metric | C23147
4u7 | L1 | my_library:MWSA0503S | C408410
47p | C28 | Capacitor_SMD:C_0402_1005Metric | C1567
SY8105 | U3 | Package_TO_SOT_SMD:TSOT-23-6 | C178247
100k | R15,R17,R14,R16,R19,R18 | Resistor_SMD:R_0402_1005Metric | C25741
Q_PMOS_GSD | Q5,Q7,Q9 | Package_TO_SOT_SMD:SOT-23 | C10487

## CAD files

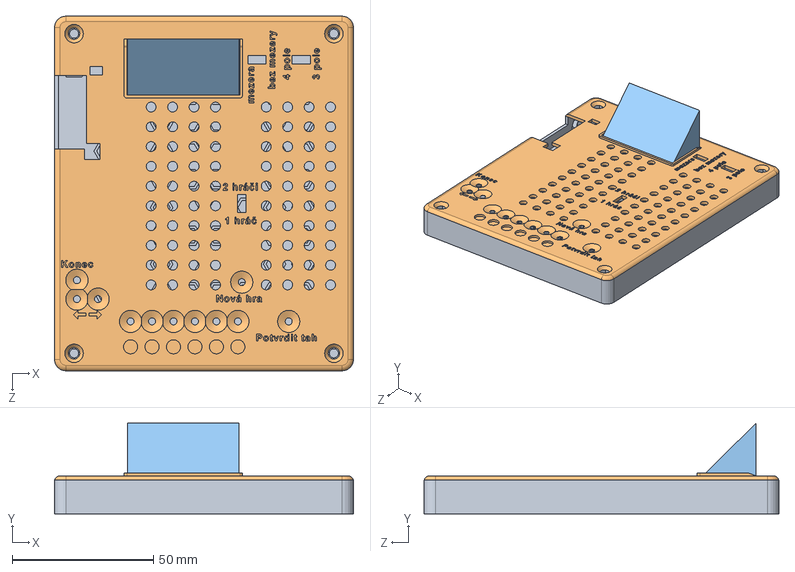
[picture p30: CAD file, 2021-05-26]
Box/celek.SLDASM
105.9 x 32.2 x 125.6 mm
novy_spodni
novy_vrchni
strecha

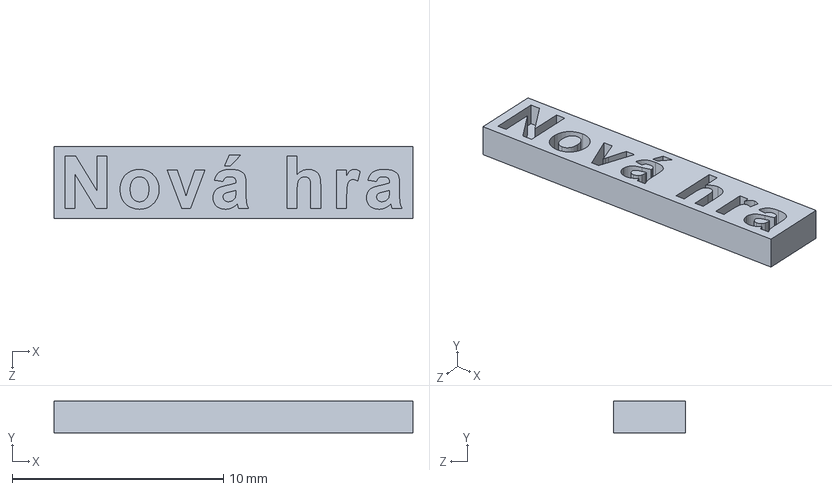
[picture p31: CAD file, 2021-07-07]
Box/Novahra.SLDPRT
17.0 x 1.50 x 3.40 mm

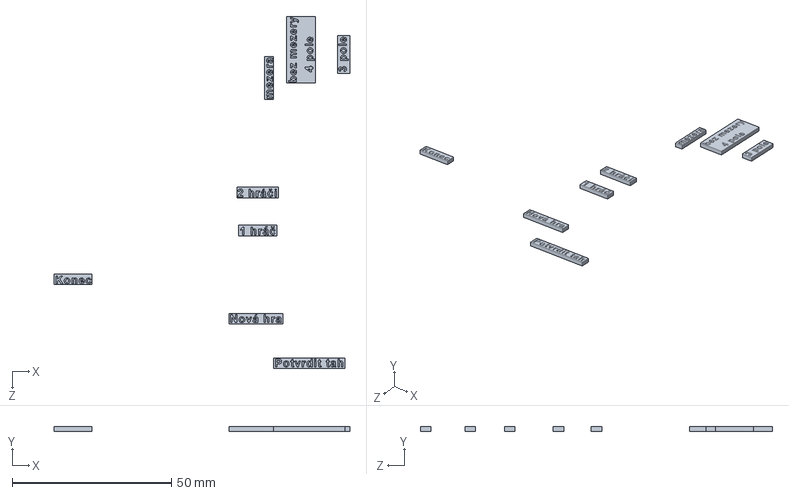
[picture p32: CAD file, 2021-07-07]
Box/texty.SLDPRT
93.0 x 1.50 x 110.7 mm

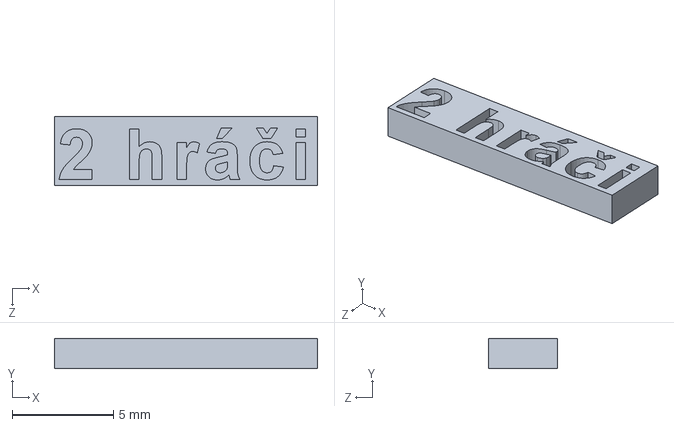
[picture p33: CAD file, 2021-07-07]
Box/2hraci.SLDPRT
13.0 x 1.50 x 3.40 mm

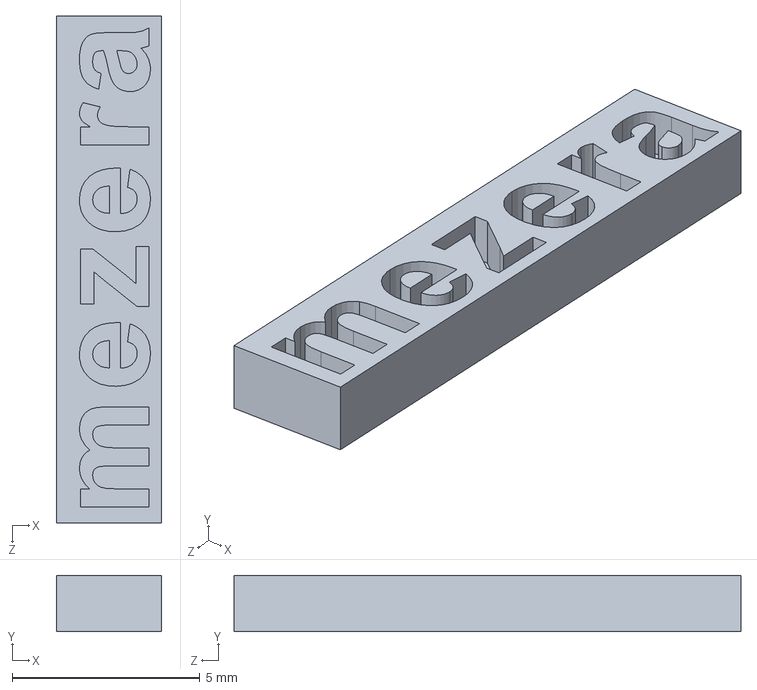
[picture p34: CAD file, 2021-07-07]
Box/mezera.SLDPRT
2.80 x 1.50 x 13.5 mm

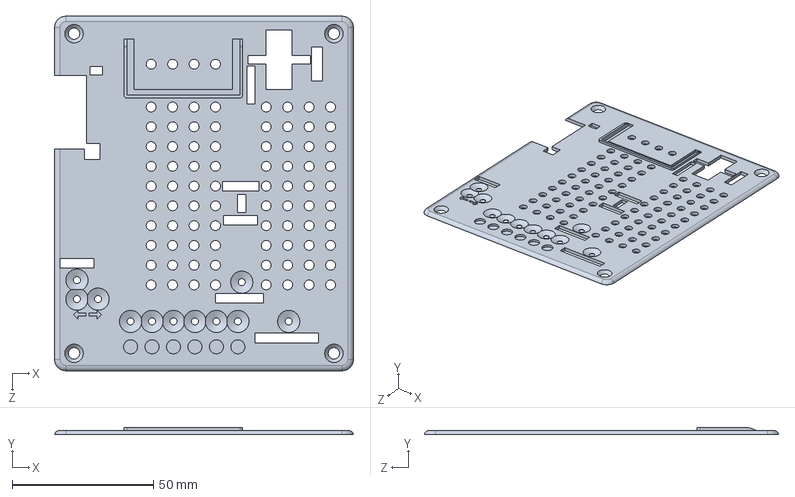
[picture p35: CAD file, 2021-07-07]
Box/novy_vrchni.SLDPRT
105.9 x 2.50 x 125.6 mm

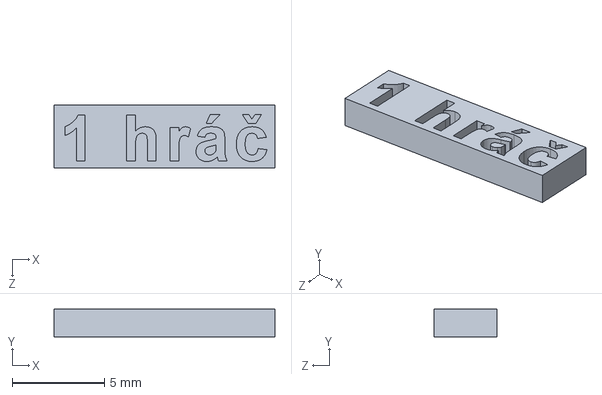
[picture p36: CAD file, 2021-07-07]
Box/1hrac.SLDPRT
12.0 x 1.50 x 3.40 mm

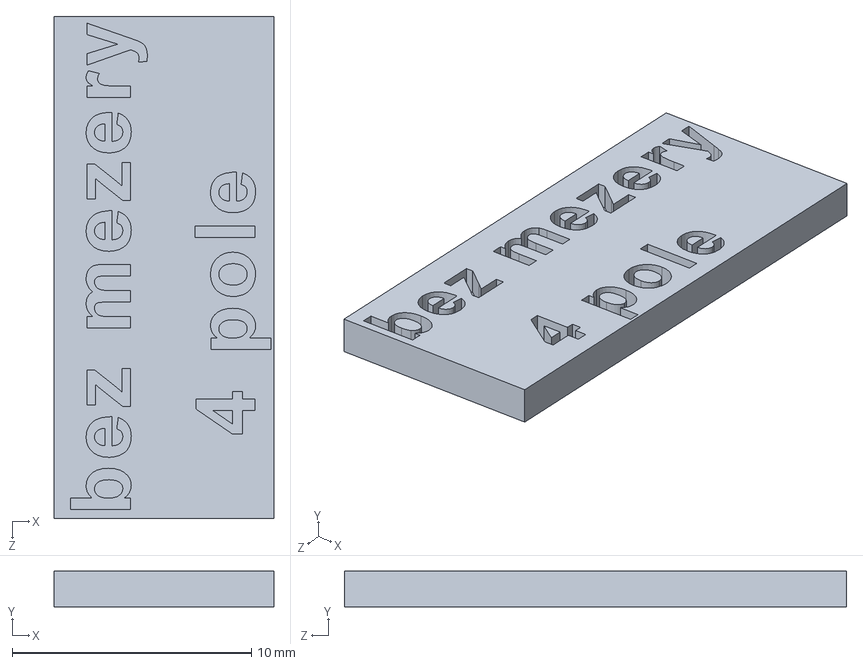
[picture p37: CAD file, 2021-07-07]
Box/4pole.SLDPRT
9.20 x 1.50 x 21.0 mm

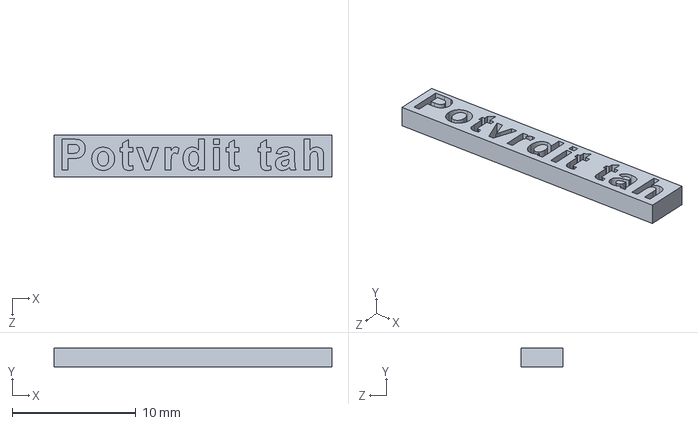
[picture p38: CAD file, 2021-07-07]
Box/Potvrdit.SLDPRT
22.5 x 1.50 x 3.40 mm

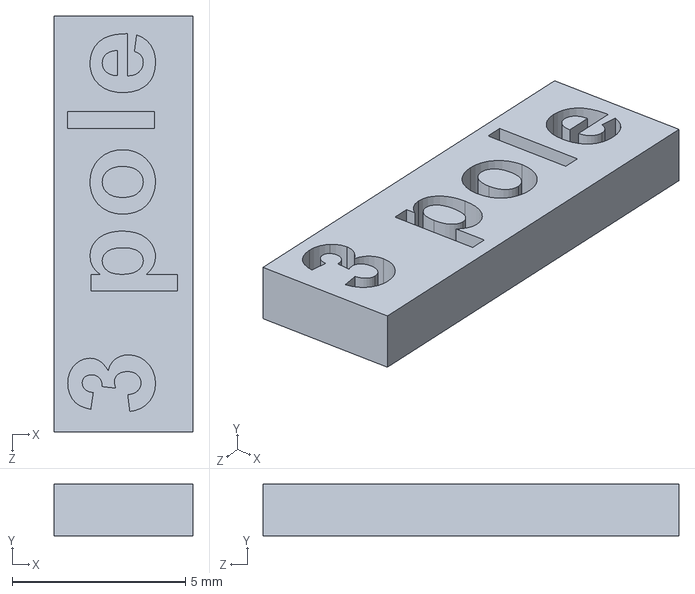
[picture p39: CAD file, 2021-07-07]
Box/3pole.SLDPRT
4.00 x 1.50 x 12.0 mm

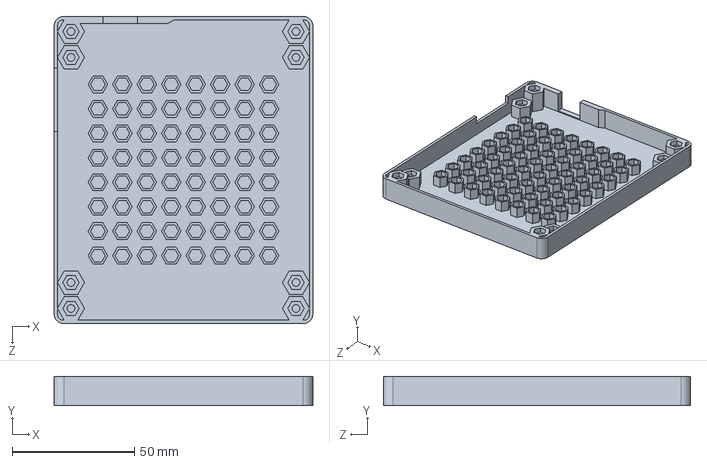
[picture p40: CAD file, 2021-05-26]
Box/novy_spodni.SLDPRT
105.9 x 12.0 x 125.6 mm

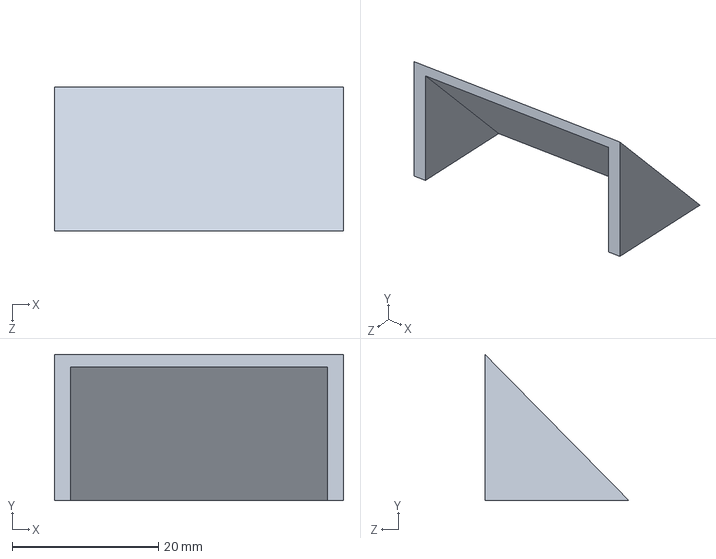
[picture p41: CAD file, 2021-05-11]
Box/strecha.SLDPRT
39.5 x 20.0 x 19.7 mm

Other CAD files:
Box/konec.SLDPRT
Box/1hrac.STL
Box/2hraci.STL
Box/3pole.STL
Box/4pole.STL
Box/Novahra.STL
Box/Potvrdit.STL
Box/konec.STL
Box/mezera.STL
Box/novy_spodni.STL
Box/novy_vrchni.STL
Box/strecha.STL
Box/texty.STL

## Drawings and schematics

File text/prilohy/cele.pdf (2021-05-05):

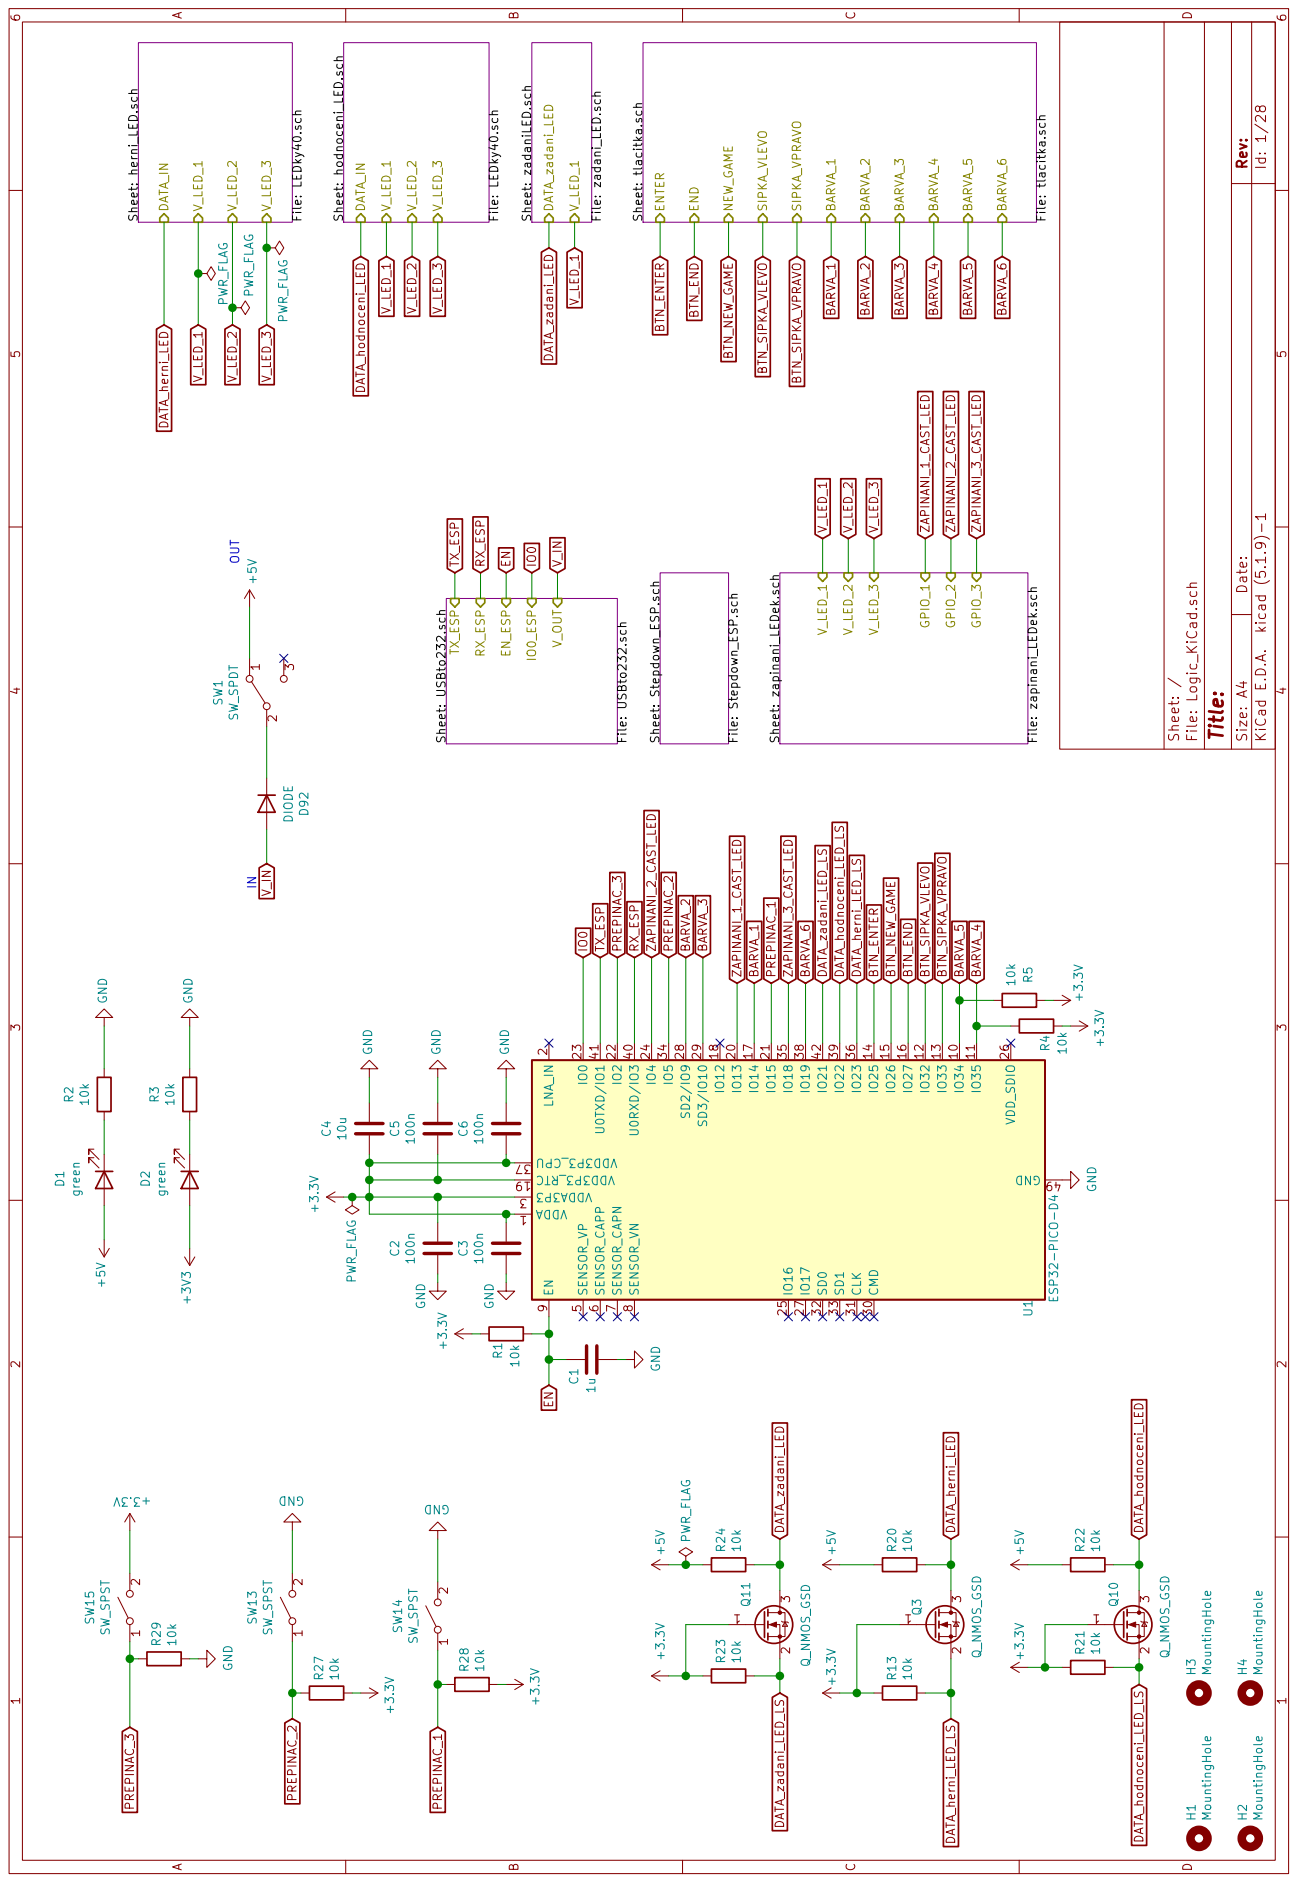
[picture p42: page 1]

D Date: KiCad E.D.A. kicad (5.1.9)-1 Rev: Size: A4

V_OUT Sheet: hodnoceni_LED.sch File: LEDky40.sch DATA_IN

Sheet: herni_LED.sch File: LEDky40.sch DATA_IN

BARVA_1 BARVA_2 BARVA_3 BARVA_4 BARVA_5 BARVA_6 Sheet: zadaniLED.sch File: zadani_LED.sch DATA_zadani_LED

File: Stepdown_ESP.sch Sheet: tlacitka.sch File: tlacitka.sch ENTER

Sheet: USBto232.sch File: USBto232.sch Sheet: / File: Logic_KiCad.sch

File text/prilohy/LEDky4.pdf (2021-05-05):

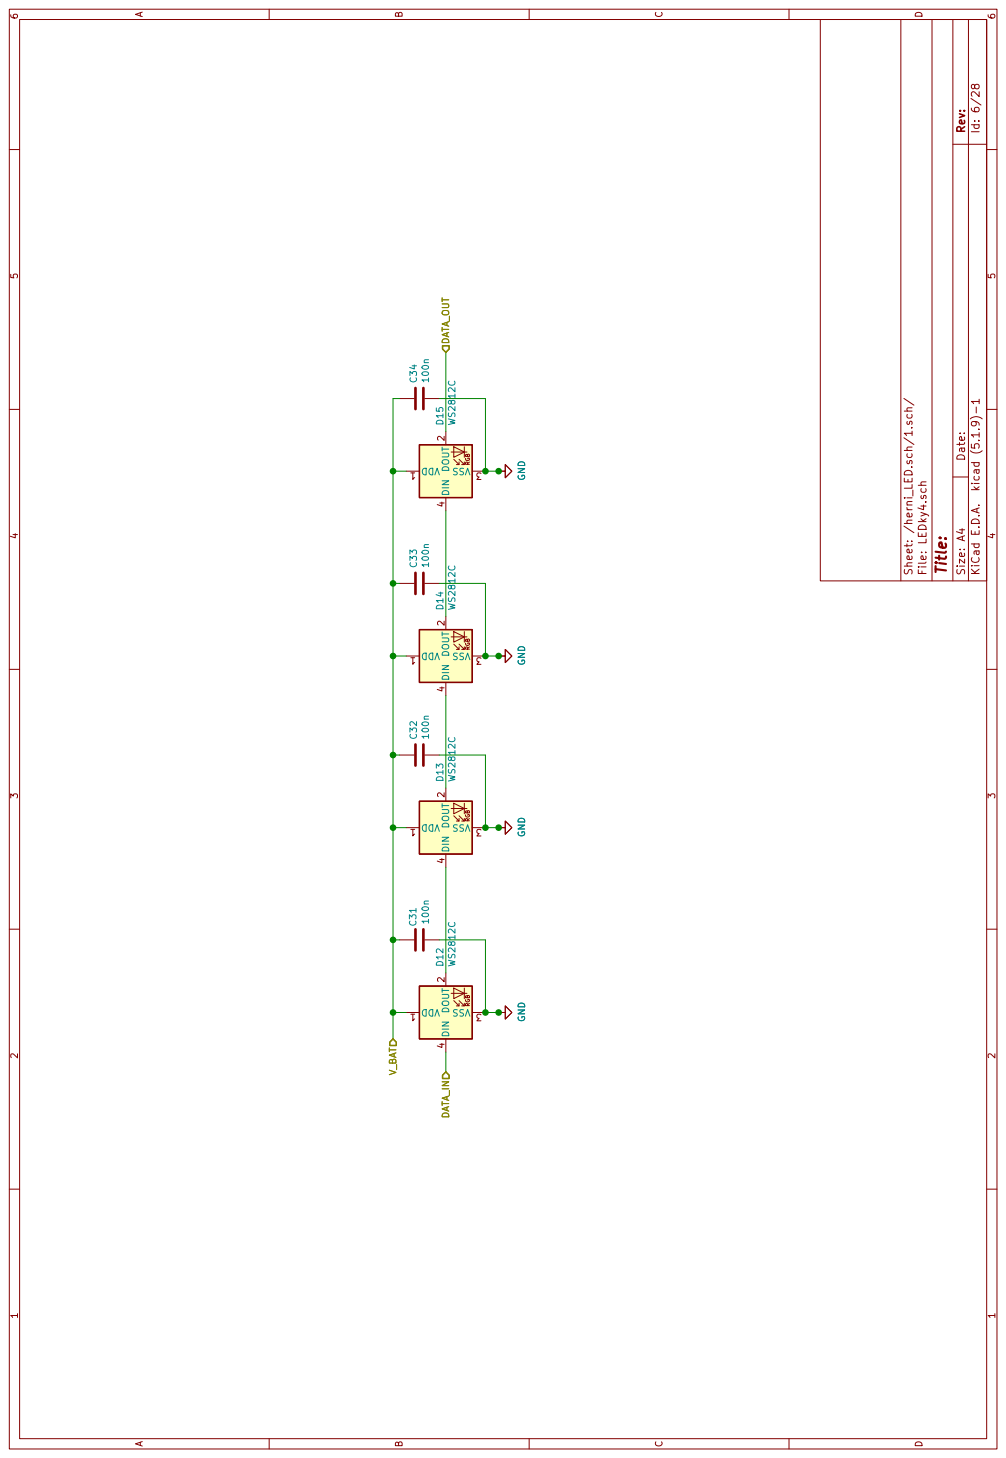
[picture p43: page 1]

D Date: KiCad E.D.A. kicad (5.1.9)-1 Rev: Size: A4

Id: 6/28 Sheet: /herni_LED.sch/1.sch/

100n GND GND GNDVDD RGB 1 DOUT

100n GND GND VDD RGB 1 DOUT

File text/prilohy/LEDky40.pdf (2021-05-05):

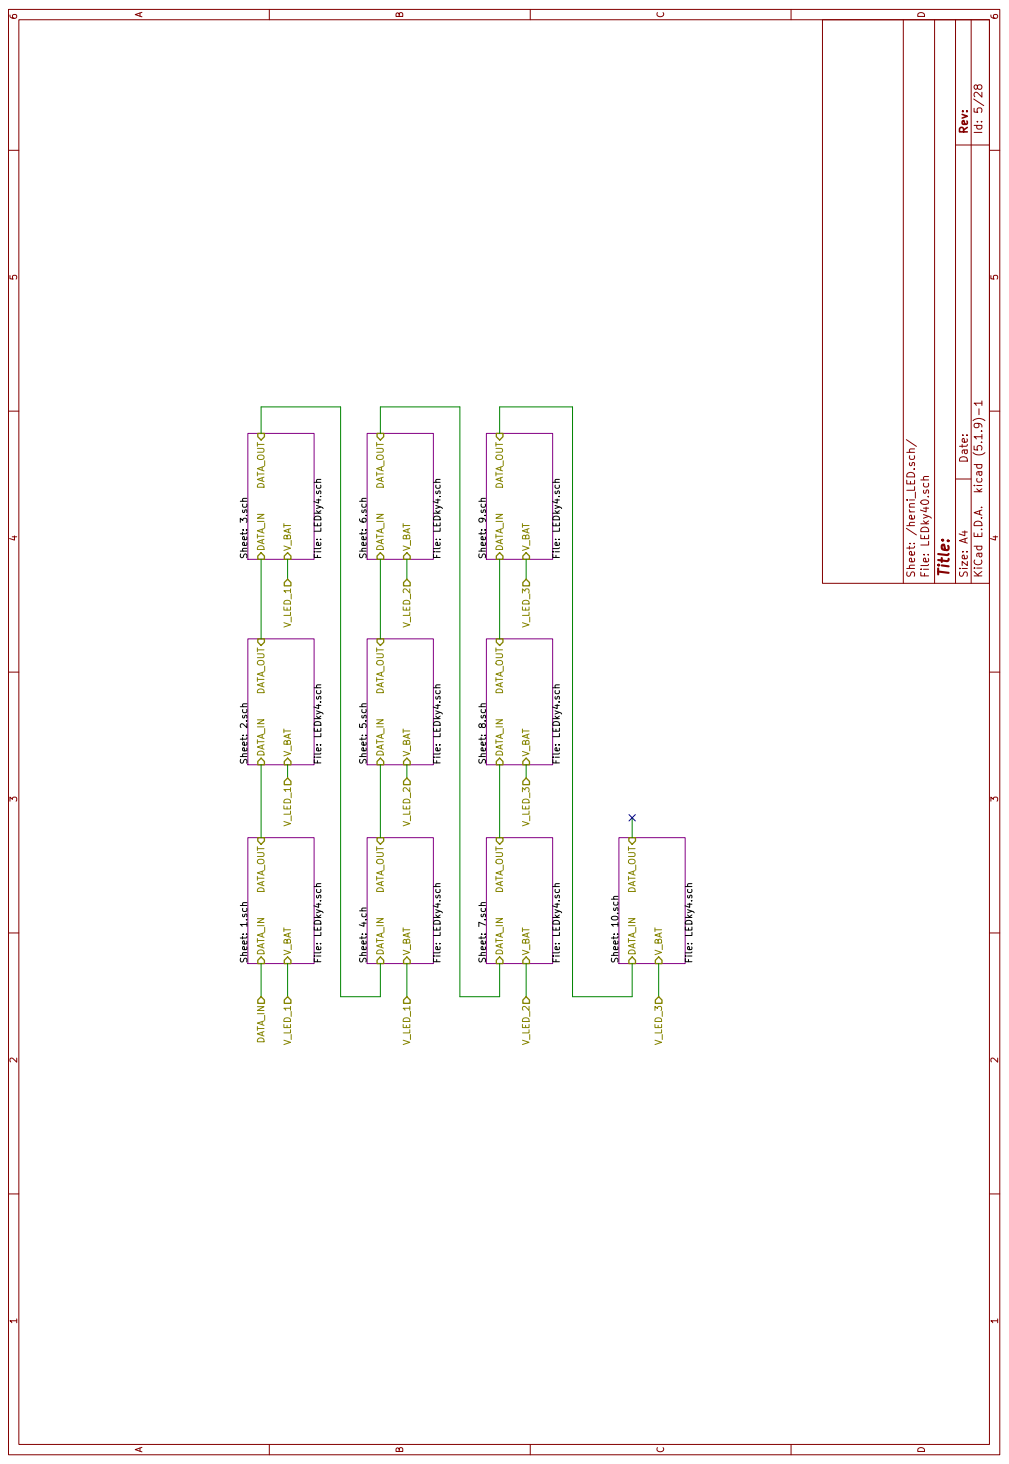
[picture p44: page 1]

D Date: KiCad E.D.A. kicad (5.1.9)-1 Rev: Size: A4

Sheet: 1.sch File: LEDky4.sch DATA_IN DATA_OUT V_BAT Sheet: 10.sch File: LEDky4.sch DATA_IN DATA_OUT V_BAT Sheet: 2.sch File: LEDky4.sch DATA_IN DATA_OUT V_BAT Sheet: 9.sch File: LEDky4.sch DATA_IN DATA_OUT V_BAT Sheet: 8.sch File: LEDky4.sch DATA_IN DATA_OUT V_BAT Sheet: 7.sch File: LEDky4.sch DATA_IN DATA_OUT V_BAT Sheet: 3.sch File: LEDky4.sch DATA_IN DATA_OUT V_BAT Sheet: 6.sch File: LEDky4.sch DATA_IN DATA_OUT V_BAT Sheet: 5.sch File: LEDky4.sch DATA_IN DATA_OUT V_BAT Sheet: 4.ch File: LEDky4.sch DATA_IN DATA_OUT V_BAT V_LED_3 V_LED_1 V_LED_1 V_LED_2 V_LED_3 V_LED_2 V_LED_3 V_LED_2 V_LED_1 V_LED_1 DATA_IN

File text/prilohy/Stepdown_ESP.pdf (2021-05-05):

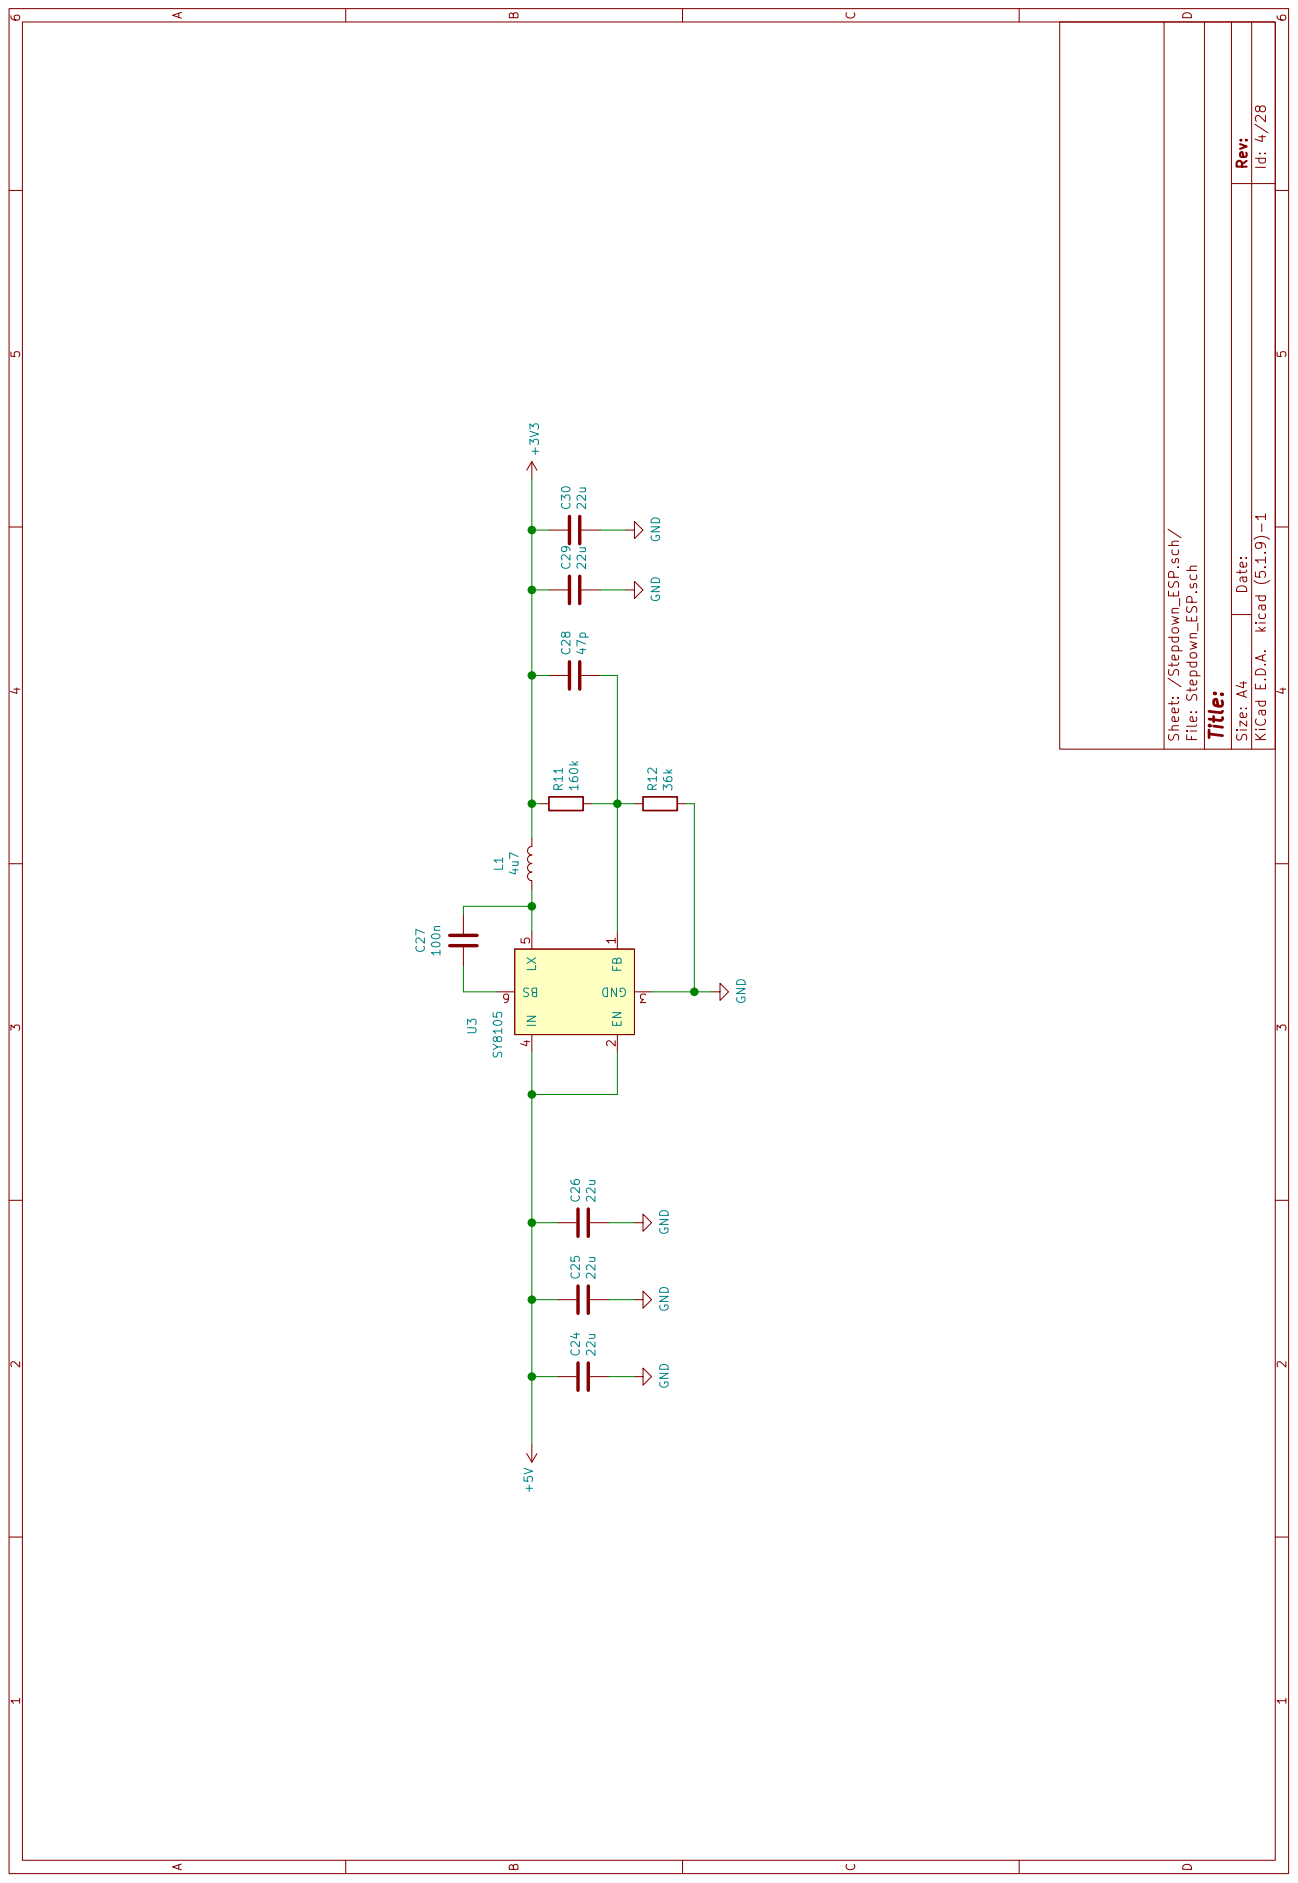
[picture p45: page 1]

D Date: KiCad E.D.A. kicad (5.1.9)-1 Rev: Size: A4

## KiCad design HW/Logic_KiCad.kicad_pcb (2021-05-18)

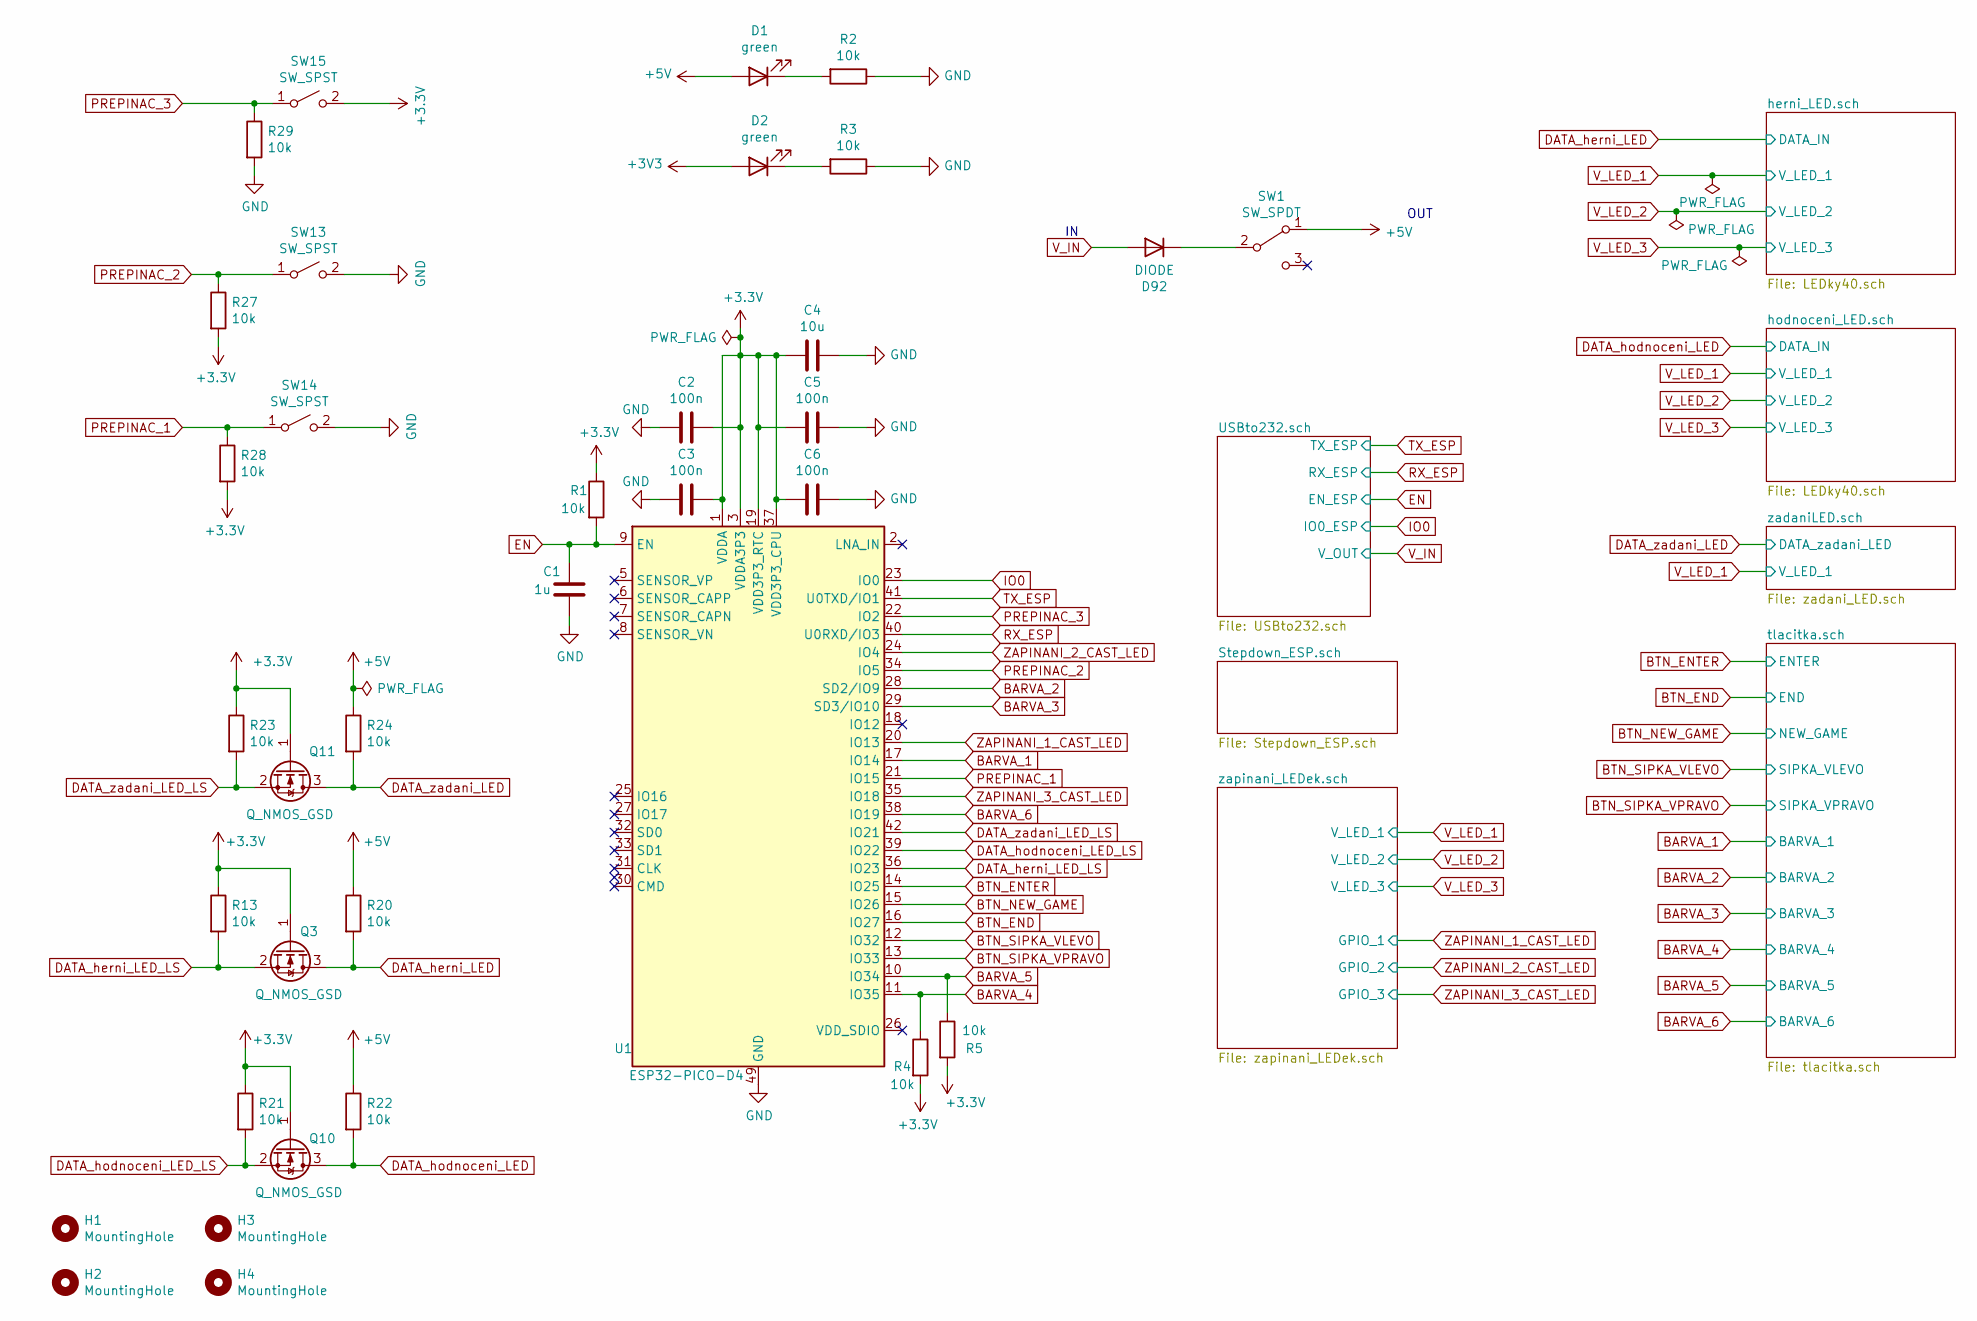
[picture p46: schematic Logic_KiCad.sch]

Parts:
C1: 1u; C_0402_1005Metric; LCSC C52923
C2, C3, C5, C6: 100n; C_0402_1005Metric; LCSC C1525
C4: 10u; C_0402_1005Metric; LCSC C15525
D1, D2: green; LED_0603_1608Metric; LCSC C72043
D92: DIODE; D_SMA; LCSC C8678
H1, H2, H3, H4: MountingHole; MountingHole_3.2mm_M3_DIN965_Pad; JLCPCB_CORRECTION 0;0;0
Q3, Q10, Q11: Q_NMOS_GSD; SOT-23; LCSC C8545
R1, R2, R3, R4, R5, R13, R20, R21, R22, R23, R24, R27, R28, R29: 10k; R_0402_1005Metric; LCSC C25744
SW1: SW_SPDT; PinHeader_1x03_P2.54mm_Vertical; LCSC ručně
SW13: SW_SPST; DIP1x1; JLCPCB_CORRECTION 0;0;270
SW14, SW15: SW_SPST; DIP1x1; JLCPCB_CORRECTION 0;0;90
U1: ESP32-PICO-D4; QFN-48-1EP_7x7mm_P0.5mm_EP5.3x5.3mm; LCSC C193707

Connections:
+5V: D1.2 (A), R20.1, R22.1, R24.1, SW1.1 (A); also elsewhere on the board
BARVA_1: U1.17 (IO14); also elsewhere on the board
BARVA_2: U1.28 (SD2/IO9); also elsewhere on the board
BARVA_3: U1.29 (SD3/IO10); also elsewhere on the board
BARVA_4: R4.1, U1.11 (IO35); also elsewhere on the board
BARVA_5: R5.1, U1.10 (IO34); also elsewhere on the board
BARVA_6: U1.38 (IO19); also elsewhere on the board
BTN_END: U1.16 (IO27); also elsewhere on the board
BTN_ENTER: U1.14 (IO25); also elsewhere on the board
BTN_NEW_GAME: U1.15 (IO26); also elsewhere on the board
BTN_SIPKA_VLEVO: U1.12 (IO32); also elsewhere on the board
BTN_SIPKA_VPRAVO: U1.13 (IO33); also elsewhere on the board
DATA_herni_LED: Q3.3 (D), R20.2; also elsewhere on the board
DATA_herni_LED_LS: Q3.2 (S), R13.2, U1.36 (IO23)
DATA_hodnoceni_LED: Q10.3 (D), R22.2; also elsewhere on the board
DATA_hodnoceni_LED_LS: Q10.2 (S), R21.2, U1.39 (IO22)
DATA_zadani_LED: Q11.3 (D), R24.2; also elsewhere on the board
DATA_zadani_LED_LS: Q11.2 (S), R23.2, U1.42 (IO21)
EN: C1.2, R1.2, U1.9 (EN); also elsewhere on the board
GND: C1.1, C2.2, C3.2, C4.1, C5.1, C6.1, R2.1, R3.1, R29.2, SW13.2 (B), SW14.2 (B), U1.49 (GND); also elsewhere on the board
IO0: U1.23 (IO0); also elsewhere on the board
unnamed: D1.1 (K), R2.2
unnamed: D2.1 (K), R3.2
unnamed: D92.1 (K), SW1.2 (B)
PREPINAC_1: R28.1, SW14.1 (A), U1.21 (IO15)
PREPINAC_2: R27.1, SW13.1 (A), U1.34 (IO5)
PREPINAC_3: R29.1, SW15.1 (A), U1.22 (IO2)
RX_ESP: U1.40 (U0RXD/IO3); also elsewhere on the board
TX_ESP: U1.41 (U0TXD/IO1); also elsewhere on the board
V_IN: D92.2 (A); also elsewhere on the board
ZAPINANI_1_CAST_LED: U1.20 (IO13); also elsewhere on the board
ZAPINANI_2_CAST_LED: U1.24 (IO4); also elsewhere on the board
ZAPINANI_3_CAST_LED: U1.35 (IO18); also elsewhere on the board

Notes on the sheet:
OUT

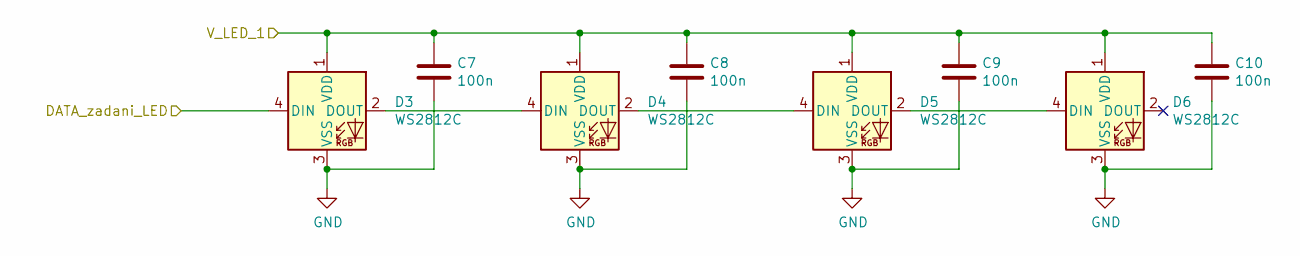
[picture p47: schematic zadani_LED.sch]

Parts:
C7, C8, C9, C10: 100n; C_0402_1005Metric; LCSC C1525
D3, D4, D5, D6: WS2812C; LED_WS2812B_PLCC4_5.0x5.0mm_P3.2mm; LCSC C114587

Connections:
DATA_zadani_LED: D3.4 (DIN); also elsewhere on the board
GND: C7.2, C8.2, C9.2, C10.2, D3.3 (VSS), D4.3 (VSS), D5.3 (VSS), D6.3 (VSS); also elsewhere on the board
unnamed: D3.2 (DOUT), D4.4 (DIN)
unnamed: D4.2 (DOUT), D5.4 (DIN)
unnamed: D5.2 (DOUT), D6.4 (DIN)
V_LED_1: C7.1, C8.1, C9.1, C10.1, D3.1 (VDD), D4.1 (VDD), D5.1 (VDD), D6.1 (VDD); also elsewhere on the board

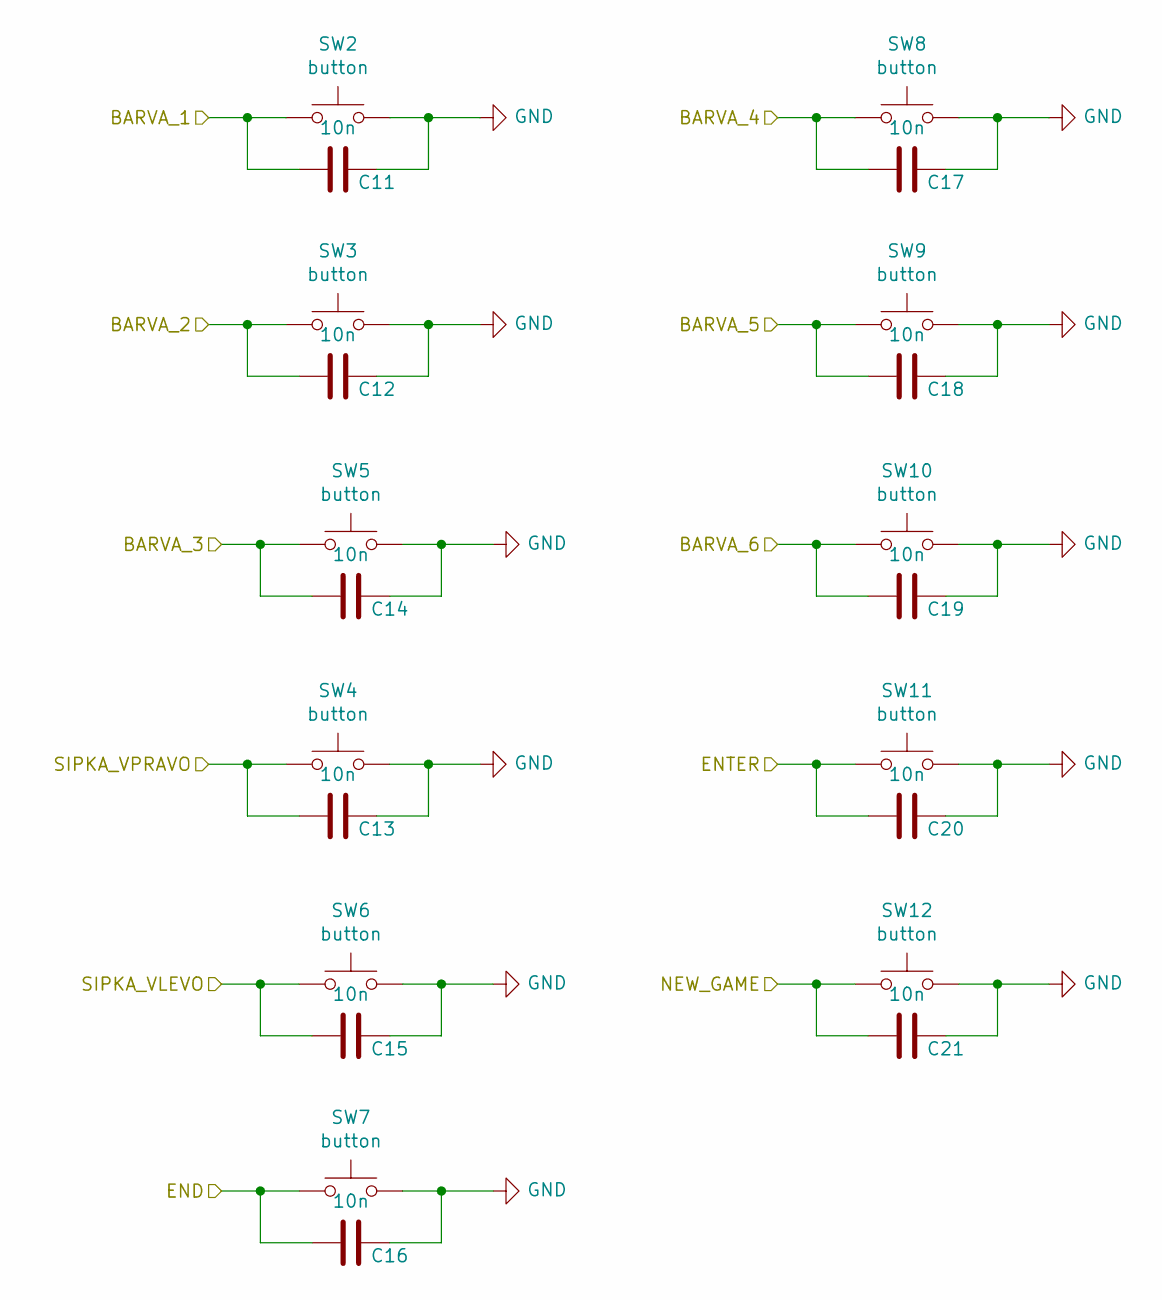
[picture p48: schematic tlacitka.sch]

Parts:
C11, C12, C13, C14, C15, C16, C17, C18, C19, C20, C21: 10n; C_0402_1005Metric; LCSC C15195
SW2, SW3, SW4, SW5, SW6, SW7, SW8, SW9, SW10, SW11, SW12: button; Tactile_switch; LCSC C318886

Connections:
BARVA_1: C11.2, SW2.1; also elsewhere on the board
BARVA_2: C12.2, SW3.1; also elsewhere on the board
BARVA_3: C14.2, SW5.1; also elsewhere on the board
BARVA_4: C17.2, SW8.1; also elsewhere on the board
BARVA_5: C18.2, SW9.1; also elsewhere on the board
BARVA_6: C19.2, SW10.1; also elsewhere on the board
BTN_END: C16.2, SW7.1; also elsewhere on the board
BTN_ENTER: C20.2, SW11.1; also elsewhere on the board
BTN_NEW_GAME: C21.2, SW12.1; also elsewhere on the board
BTN_SIPKA_VLEVO: C15.2, SW6.1; also elsewhere on the board
BTN_SIPKA_VPRAVO: C13.2, SW4.1; also elsewhere on the board
GND: C11.1, C12.1, C13.1, C14.1, C15.1, C16.1, C17.1, C18.1, C19.1, C20.1, C21.1, SW2.2, SW3.2, SW4.2, SW5.2, SW6.2, SW7.2, SW8.2, SW9.2, SW10.2, SW11.2, SW12.2; also elsewhere on the board

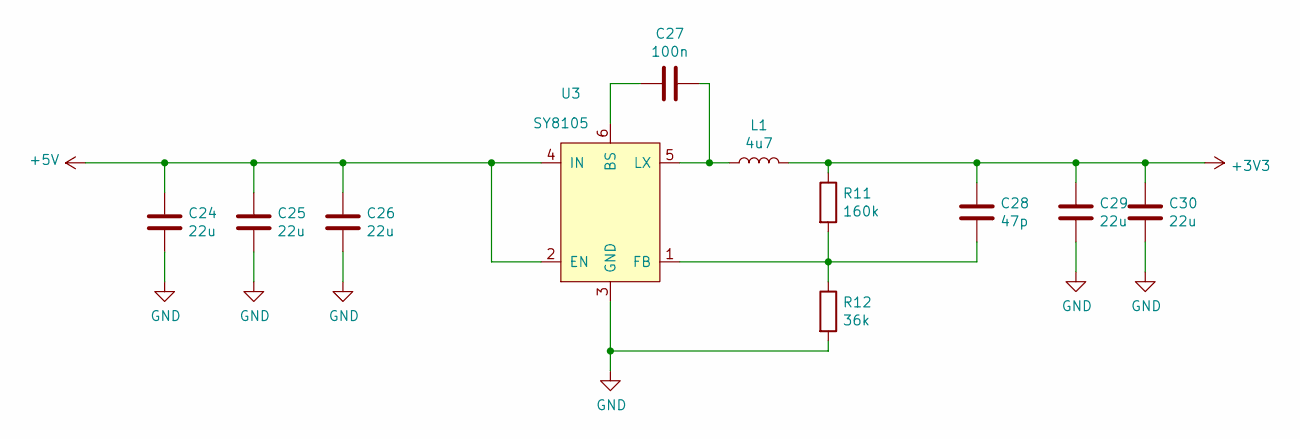
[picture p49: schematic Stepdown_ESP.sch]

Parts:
C24, C25, C26, C29, C30: 22u; C_0603_1608Metric; LCSC C59461
C27: 100n; C_0402_1005Metric; LCSC C1525
C28: 47p; C_0402_1005Metric; LCSC C1567
L1: 4u7; MWSA0503S; LCSC C408410
R11: 160k; R_0603_1608Metric; LCSC C22813
R12: 36k; R_0603_1608Metric; LCSC C23147
U3: SY8105; TSOT-23-6; LCSC C178247

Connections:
+5V: C24.1, C25.1, C26.1, U3.2 (EN), U3.4 (IN); also elsewhere on the board
GND: C24.2, C25.2, C26.2, C29.1, C30.1, R12.2, U3.3 (GND); also elsewhere on the board
unnamed: C27.1, L1.1, U3.5 (LX)
unnamed: C27.2, U3.6 (BS)
unnamed: C28.1, R11.2, R12.1, U3.1 (FB)

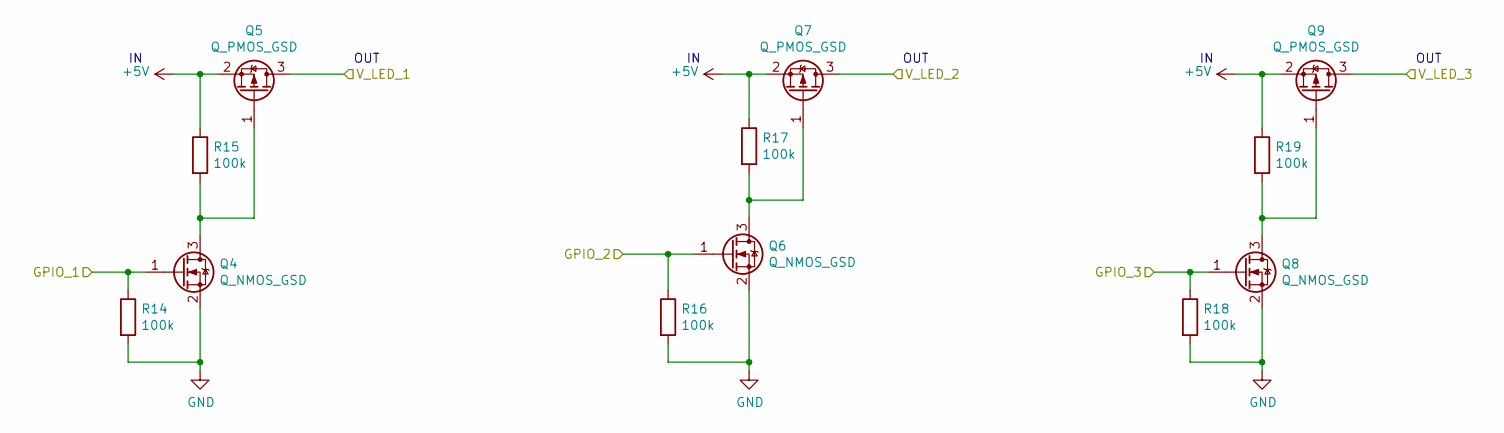
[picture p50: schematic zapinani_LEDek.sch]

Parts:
Q4, Q6, Q8: Q_NMOS_GSD; SOT-23; LCSC C8545
Q5, Q7, Q9: Q_PMOS_GSD; SOT-23; LCSC C10487
R14, R15, R16, R17, R18, R19: 100k; R_0402_1005Metric; LCSC C25741

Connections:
+5V: Q5.2 (S), Q7.2 (S), Q9.2 (S), R15.1, R17.1, R19.1; also elsewhere on the board
GND: Q4.2 (S), Q6.2 (S), Q8.2 (S), R14.2, R16.2, R18.2; also elsewhere on the board
unnamed: Q4.3 (D), Q5.1 (G), R15.2
unnamed: Q6.3 (D), Q7.1 (G), R17.2
unnamed: Q8.3 (D), Q9.1 (G), R19.2
V_LED_1: Q5.3 (D); also elsewhere on the board
V_LED_2: Q7.3 (D); also elsewhere on the board
V_LED_3: Q9.3 (D); also elsewhere on the board
ZAPINANI_1_CAST_LED: Q4.1 (G), R14.1; also elsewhere on the board
ZAPINANI_2_CAST_LED: Q6.1 (G), R16.1; also elsewhere on the board
ZAPINANI_3_CAST_LED: Q8.1 (G), R18.1; also elsewhere on the board

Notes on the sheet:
OUT

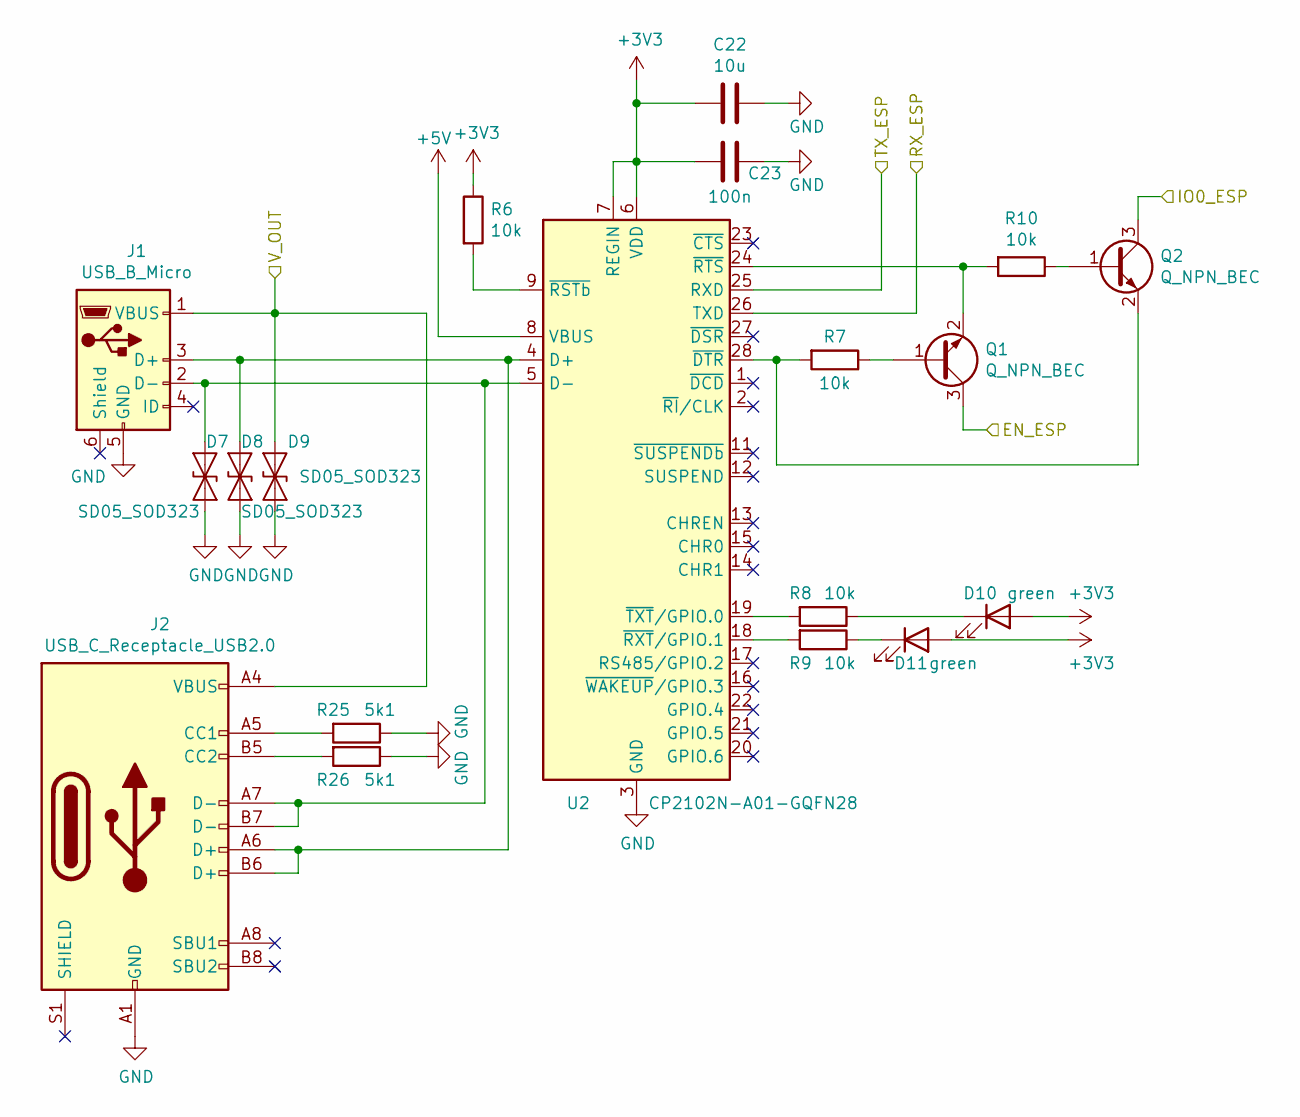
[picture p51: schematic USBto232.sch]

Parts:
C22: 10u; C_0402_1005Metric; LCSC C15525
C23: 100n; C_0402_1005Metric; LCSC C1525
D7, D8, D9: SD05_SOD323; D_SOD-323; LCSC neosazovat
D10, D11: green; LED_0603_1608Metric; LCSC C72043
J1: USB_B_Micro; USB_Micro-B_Wuerth_629105150521; LCSC C319164
J2: USB_C_Receptacle_USB2.0; USB_C_Receptacle_HRO_TYPE-C-31-M-12; JLCPCB_CORRECTION 1.8;0;180
Q1, Q2: Q_NPN_BEC; SOT-23; LCSC C20526
R6, R7, R8, R9, R10: 10k; R_0402_1005Metric; LCSC C25744
R25, R26: 5k1; R_0402_1005Metric; JLCPCB_CORRECTION 0;0;0
U2: CP2102N-A01-GQFN28; QFN-28-1EP_5x5mm_P0.5mm_EP3.35x3.35mm; LCSC C6568

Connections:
+5V: U2.8 (VBUS); also elsewhere on the board
EN: Q1.3 (C); also elsewhere on the board
GND: C22.1, C23.1, D7.1 (A1), D8.1 (A1), D9.1 (A1), J1.5 (GND), J2.A1 (GND), J2.A12 (GND), J2.B1 (GND), J2.B12 (GND), R25.1, R26.1, U2.3 (GND), U2.29 (GND); also elsewhere on the board
IO0: Q2.3 (C); also elsewhere on the board
unnamed: D7.2 (A2), J1.2 (D-), J2.A7 (D-), J2.B7 (D-), U2.5 (D-)
unnamed: D8.2 (A2), J1.3 (D+), J2.A6 (D+), J2.B6 (D+), U2.4 (D+)
unnamed: D10.1 (K), R8.1
unnamed: D11.1 (K), R9.1
unnamed: J2.A5 (CC1), R25.2
unnamed: J2.B5 (CC2), R26.2
unnamed: Q1.1 (B), R7.1
unnamed: Q1.2 (E), R10.2, U2.24 (~RTS)
unnamed: Q2.1 (B), R10.1
unnamed: Q2.2 (E), R7.2, U2.28 (~DTR)
unnamed: R6.2, U2.9 (~RSTb)
unnamed: R8.2, U2.19 (~TXT~/GPIO.0)
unnamed: R9.2, U2.18 (~RXT~/GPIO.1)
RX_ESP: U2.26 (TXD); also elsewhere on the board
TX_ESP: U2.25 (RXD); also elsewhere on the board
V_IN: D9.2 (A2), J1.1 (VBUS), J2.A4 (VBUS), J2.A9 (VBUS), J2.B4 (VBUS), J2.B9 (VBUS); also elsewhere on the board

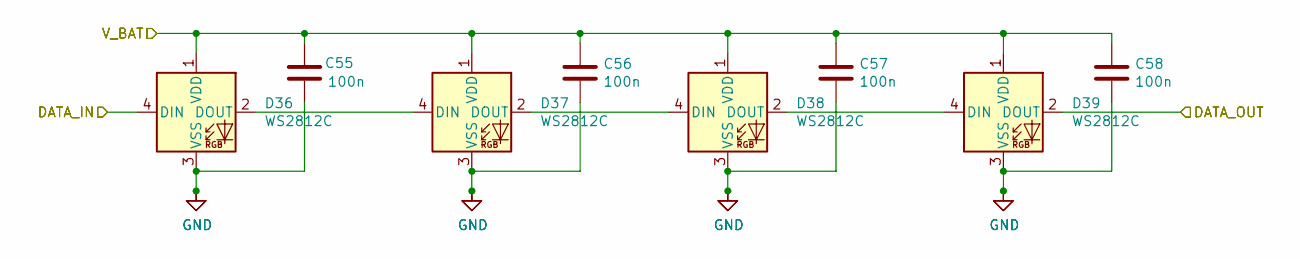
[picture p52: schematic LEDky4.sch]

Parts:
C75, C76, C77, C78: 100n; C_0402_1005Metric; LCSC C1525
D56, D57, D58, D59: WS2812C; LED_WS2812B_PLCC4_5.0x5.0mm_P3.2mm; LCSC C114587

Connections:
/hodnoceni_LED.sch/2.sch/DATA_IN: D56.4 (DIN); also elsewhere on the board
/hodnoceni_LED.sch/3.sch/DATA_IN: D59.2 (DOUT); also elsewhere on the board
GND: C75.2, C76.2, C77.2, C78.2, D56.3 (VSS), D57.3 (VSS), D58.3 (VSS), D59.3 (VSS); also elsewhere on the board
unnamed: D56.2 (DOUT), D57.4 (DIN)
unnamed: D57.2 (DOUT), D58.4 (DIN)
unnamed: D58.2 (DOUT), D59.4 (DIN)
V_LED_1: C75.1, C76.1, C77.1, C78.1, D56.1 (VDD), D57.1 (VDD), D58.1 (VDD), D59.1 (VDD); also elsewhere on the board

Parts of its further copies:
C31, C32, C33, C34, C35, C36, C37, C38, C39, C40, C41, C42, C43, C44, C45, C46, C47, C48, C49, C50, C51, C52, C53, C54, C55, C56, C57, C58, C59, C60, C61, C62, C63, C64, C65, C66, C67, C68, C69, C70, C71, C72, C73, C74, C79, C80, C81, C82, C83, C84, C85, C86, C87, C88, C89, C90, C91, C92, C93, C94, C95, C96, C97, C98, C99, C100, C101, C102, C103, C104, C105, C106, C107, C108, C109, C110: 100n; C_0402_1005Metric; LCSC C1525
D12, D13, D14, D15, D16, D17, D18, D19, D20, D21, D22, D23, D24, D25, D26, D27, D28, D29, D30, D31, D32, D33, D34, D35, D36, D37, D38, D39, D40, D41, D42, D43, D44, D45, D46, D47, D48, D49, D50, D51, D52, D53, D54, D55, D60, D61, D62, D63, D64, D65, D66, D67, D68, D69, D70, D71, D72, D73, D74, D75, D76, D77, D78, D79, D80, D81, D82, D83, D84, D85, D86, D87, D88, D89, D90, D91: WS2812C; LED_WS2812B_PLCC4_5.0x5.0mm_P3.2mm; LCSC C114587

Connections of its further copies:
/herni_LED.sch/2.sch/DATA_IN: D15.2 (DOUT), D16.4 (DIN)
/herni_LED.sch/3.sch/DATA_IN: D19.2 (DOUT), D20.4 (DIN)
/herni_LED.sch/4.ch/DATA_IN: D23.2 (DOUT), D24.4 (DIN)
/herni_LED.sch/5.sch/DATA_IN: D27.2 (DOUT), D28.4 (DIN)
/herni_LED.sch/6.sch/DATA_IN: D31.2 (DOUT), D32.4 (DIN)
/herni_LED.sch/7.sch/DATA_IN: D35.2 (DOUT), D36.4 (DIN)
/herni_LED.sch/8.sch/DATA_IN: D39.2 (DOUT), D40.4 (DIN)
/herni_LED.sch/9.sch/DATA_IN: D43.2 (DOUT), D44.4 (DIN)
/herni_LED.sch/10.sch/DATA_IN: D47.2 (DOUT), D48.4 (DIN)
/herni_LED.sch/10.sch/DATA_OUT: D51.2 (DOUT)
/hodnoceni_LED.sch/2.sch/DATA_IN: D55.2 (DOUT); also elsewhere on the board
/hodnoceni_LED.sch/3.sch/DATA_IN: D60.4 (DIN); also elsewhere on the board
/hodnoceni_LED.sch/4.ch/DATA_IN: D63.2 (DOUT), D64.4 (DIN)
/hodnoceni_LED.sch/5.sch/DATA_IN: D67.2 (DOUT), D68.4 (DIN)
/hodnoceni_LED.sch/6.sch/DATA_IN: D71.2 (DOUT), D72.4 (DIN)
/hodnoceni_LED.sch/7.sch/DATA_IN: D75.2 (DOUT), D76.4 (DIN)
/hodnoceni_LED.sch/8.sch/DATA_IN: D79.2 (DOUT), D80.4 (DIN)
/hodnoceni_LED.sch/9.sch/DATA_IN: D83.2 (DOUT), D84.4 (DIN)
/hodnoceni_LED.sch/10.sch/DATA_IN: D87.2 (DOUT), D88.4 (DIN)
/hodnoceni_LED.sch/10.sch/DATA_OUT: D91.2 (DOUT)
DATA_herni_LED: D12.4 (DIN); also elsewhere on the board
DATA_hodnoceni_LED: D52.4 (DIN); also elsewhere on the board
GND: C31.2, C32.2, C33.2, C34.2, C35.2, C36.2, C37.2, C38.2, C39.2, C40.2, C41.2, C42.2, C43.2, C44.2, C45.2, C46.2, C47.2, C48.2, C49.2, C50.2, C51.2, C52.2, C53.2, C54.2, C55.2, C56.2, C57.2, C58.2, C59.2, C60.2, C61.2, C62.2, C63.2, C64.2, C65.2, C66.2, C67.2, C68.2, C69.2, C70.2, C71.2, C72.2, C73.2, C74.2, C79.2, C80.2, C81.2, C82.2, C83.2, C84.2, C85.2, C86.2, C87.2, C88.2, C89.2, C90.2, C91.2, C92.2, C93.2, C94.2, C95.2, C96.2, C97.2, C98.2, C99.2, C100.2, C101.2, C102.2, C103.2, C104.2, C105.2, C106.2, C107.2, C108.2, C109.2, C110.2, D12.3 (VSS), D13.3 (VSS), D14.3 (VSS), D15.3 (VSS), D16.3 (VSS), D17.3 (VSS), D18.3 (VSS), D19.3 (VSS), D20.3 (VSS), D21.3 (VSS), D22.3 (VSS), D23.3 (VSS), D24.3 (VSS), D25.3 (VSS), D26.3 (VSS), D27.3 (VSS), D28.3 (VSS), D29.3 (VSS), D30.3 (VSS), D31.3 (VSS), D32.3 (VSS), D33.3 (VSS), D34.3 (VSS), D35.3 (VSS), D36.3 (VSS), D37.3 (VSS), D38.3 (VSS), D39.3 (VSS), D40.3 (VSS), D41.3 (VSS), D42.3 (VSS), D43.3 (VSS), D44.3 (VSS), D45.3 (VSS), D46.3 (VSS), D47.3 (VSS), D48.3 (VSS), D49.3 (VSS), D50.3 (VSS), D51.3 (VSS), D52.3 (VSS), D53.3 (VSS), D54.3 (VSS), D55.3 (VSS), D60.3 (VSS), D61.3 (VSS), D62.3 (VSS), D63.3 (VSS), D64.3 (VSS), D65.3 (VSS), D66.3 (VSS), D67.3 (VSS), D68.3 (VSS), D69.3 (VSS), D70.3 (VSS), D71.3 (VSS), D72.3 (VSS), D73.3 (VSS), D74.3 (VSS), D75.3 (VSS), D76.3 (VSS), D77.3 (VSS), D78.3 (VSS), D79.3 (VSS), D80.3 (VSS), D81.3 (VSS), D82.3 (VSS), D83.3 (VSS), D84.3 (VSS), D85.3 (VSS), D86.3 (VSS), D87.3 (VSS), D88.3 (VSS), D89.3 (VSS), D90.3 (VSS), D91.3 (VSS); also elsewhere on the board
unnamed: D12.2 (DOUT), D13.4 (DIN)
unnamed: D13.2 (DOUT), D14.4 (DIN)
unnamed: D14.2 (DOUT), D15.4 (DIN)
unnamed: D16.2 (DOUT), D17.4 (DIN)
unnamed: D17.2 (DOUT), D18.4 (DIN)
unnamed: D18.2 (DOUT), D19.4 (DIN)
unnamed: D20.2 (DOUT), D21.4 (DIN)
unnamed: D21.2 (DOUT), D22.4 (DIN)
unnamed: D22.2 (DOUT), D23.4 (DIN)
unnamed: D24.2 (DOUT), D25.4 (DIN)
unnamed: D25.2 (DOUT), D26.4 (DIN)
unnamed: D26.2 (DOUT), D27.4 (DIN)
unnamed: D28.2 (DOUT), D29.4 (DIN)
unnamed: D29.2 (DOUT), D30.4 (DIN)
unnamed: D30.2 (DOUT), D31.4 (DIN)
unnamed: D32.2 (DOUT), D33.4 (DIN)
unnamed: D33.2 (DOUT), D34.4 (DIN)
unnamed: D34.2 (DOUT), D35.4 (DIN)
unnamed: D36.2 (DOUT), D37.4 (DIN)
unnamed: D37.2 (DOUT), D38.4 (DIN)
unnamed: D38.2 (DOUT), D39.4 (DIN)
unnamed: D40.2 (DOUT), D41.4 (DIN)
unnamed: D41.2 (DOUT), D42.4 (DIN)
unnamed: D42.2 (DOUT), D43.4 (DIN)
unnamed: D44.2 (DOUT), D45.4 (DIN)
unnamed: D45.2 (DOUT), D46.4 (DIN)
unnamed: D46.2 (DOUT), D47.4 (DIN)
unnamed: D48.2 (DOUT), D49.4 (DIN)
unnamed: D49.2 (DOUT), D50.4 (DIN)
unnamed: D50.2 (DOUT), D51.4 (DIN)
unnamed: D52.2 (DOUT), D53.4 (DIN)
unnamed: D53.2 (DOUT), D54.4 (DIN)
unnamed: D54.2 (DOUT), D55.4 (DIN)
unnamed: D60.2 (DOUT), D61.4 (DIN)
unnamed: D61.2 (DOUT), D62.4 (DIN)
unnamed: D62.2 (DOUT), D63.4 (DIN)
unnamed: D64.2 (DOUT), D65.4 (DIN)
unnamed: D65.2 (DOUT), D66.4 (DIN)
unnamed: D66.2 (DOUT), D67.4 (DIN)
unnamed: D68.2 (DOUT), D69.4 (DIN)
unnamed: D69.2 (DOUT), D70.4 (DIN)
unnamed: D70.2 (DOUT), D71.4 (DIN)
unnamed: D72.2 (DOUT), D73.4 (DIN)
unnamed: D73.2 (DOUT), D74.4 (DIN)
unnamed: D74.2 (DOUT), D75.4 (DIN)
unnamed: D76.2 (DOUT), D77.4 (DIN)
unnamed: D77.2 (DOUT), D78.4 (DIN)
unnamed: D78.2 (DOUT), D79.4 (DIN)
unnamed: D80.2 (DOUT), D81.4 (DIN)
unnamed: D81.2 (DOUT), D82.4 (DIN)
unnamed: D82.2 (DOUT), D83.4 (DIN)
unnamed: D84.2 (DOUT), D85.4 (DIN)
unnamed: D85.2 (DOUT), D86.4 (DIN)
unnamed: D86.2 (DOUT), D87.4 (DIN)
unnamed: D88.2 (DOUT), D89.4 (DIN)
unnamed: D89.2 (DOUT), D90.4 (DIN)
unnamed: D90.2 (DOUT), D91.4 (DIN)
V_LED_1: C31.1, C32.1, C33.1, C34.1, C35.1, C36.1, C37.1, C38.1, C39.1, C40.1, C41.1, C42.1, C43.1, C44.1, C45.1, C46.1, C71.1, C72.1, C73.1, C74.1, C79.1, C80.1, C81.1, C82.1, C83.1, C84.1, C85.1, C86.1, D12.1 (VDD), D13.1 (VDD), D14.1 (VDD), D15.1 (VDD), D16.1 (VDD), D17.1 (VDD), D18.1 (VDD), D19.1 (VDD), D20.1 (VDD), D21.1 (VDD), D22.1 (VDD), D23.1 (VDD), D24.1 (VDD), D25.1 (VDD), D26.1 (VDD), D27.1 (VDD), D52.1 (VDD), D53.1 (VDD), D54.1 (VDD), D55.1 (VDD), D60.1 (VDD), D61.1 (VDD), D62.1 (VDD), D63.1 (VDD), D64.1 (VDD), D65.1 (VDD), D66.1 (VDD), D67.1 (VDD); also elsewhere on the board
V_LED_2: C47.1, C48.1, C49.1, C50.1, C51.1, C52.1, C53.1, C54.1, C55.1, C56.1, C57.1, C58.1, C87.1, C88.1, C89.1, C90.1, C91.1, C92.1, C93.1, C94.1, C95.1, C96.1, C97.1, C98.1, D28.1 (VDD), D29.1 (VDD), D30.1 (VDD), D31.1 (VDD), D32.1 (VDD), D33.1 (VDD), D34.1 (VDD), D35.1 (VDD), D36.1 (VDD), D37.1 (VDD), D38.1 (VDD), D39.1 (VDD), D68.1 (VDD), D69.1 (VDD), D70.1 (VDD), D71.1 (VDD), D72.1 (VDD), D73.1 (VDD), D74.1 (VDD), D75.1 (VDD), D76.1 (VDD), D77.1 (VDD), D78.1 (VDD), D79.1 (VDD); also elsewhere on the board
V_LED_3: C59.1, C60.1, C61.1, C62.1, C63.1, C64.1, C65.1, C66.1, C67.1, C68.1, C69.1, C70.1, C99.1, C100.1, C101.1, C102.1, C103.1, C104.1, C105.1, C106.1, C107.1, C108.1, C109.1, C110.1, D40.1 (VDD), D41.1 (VDD), D42.1 (VDD), D43.1 (VDD), D44.1 (VDD), D45.1 (VDD), D46.1 (VDD), D47.1 (VDD), D48.1 (VDD), D49.1 (VDD), D50.1 (VDD), D51.1 (VDD), D80.1 (VDD), D81.1 (VDD), D82.1 (VDD), D83.1 (VDD), D84.1 (VDD), D85.1 (VDD), D86.1 (VDD), D87.1 (VDD), D88.1 (VDD), D89.1 (VDD), D90.1 (VDD), D91.1 (VDD); also elsewhere on the board

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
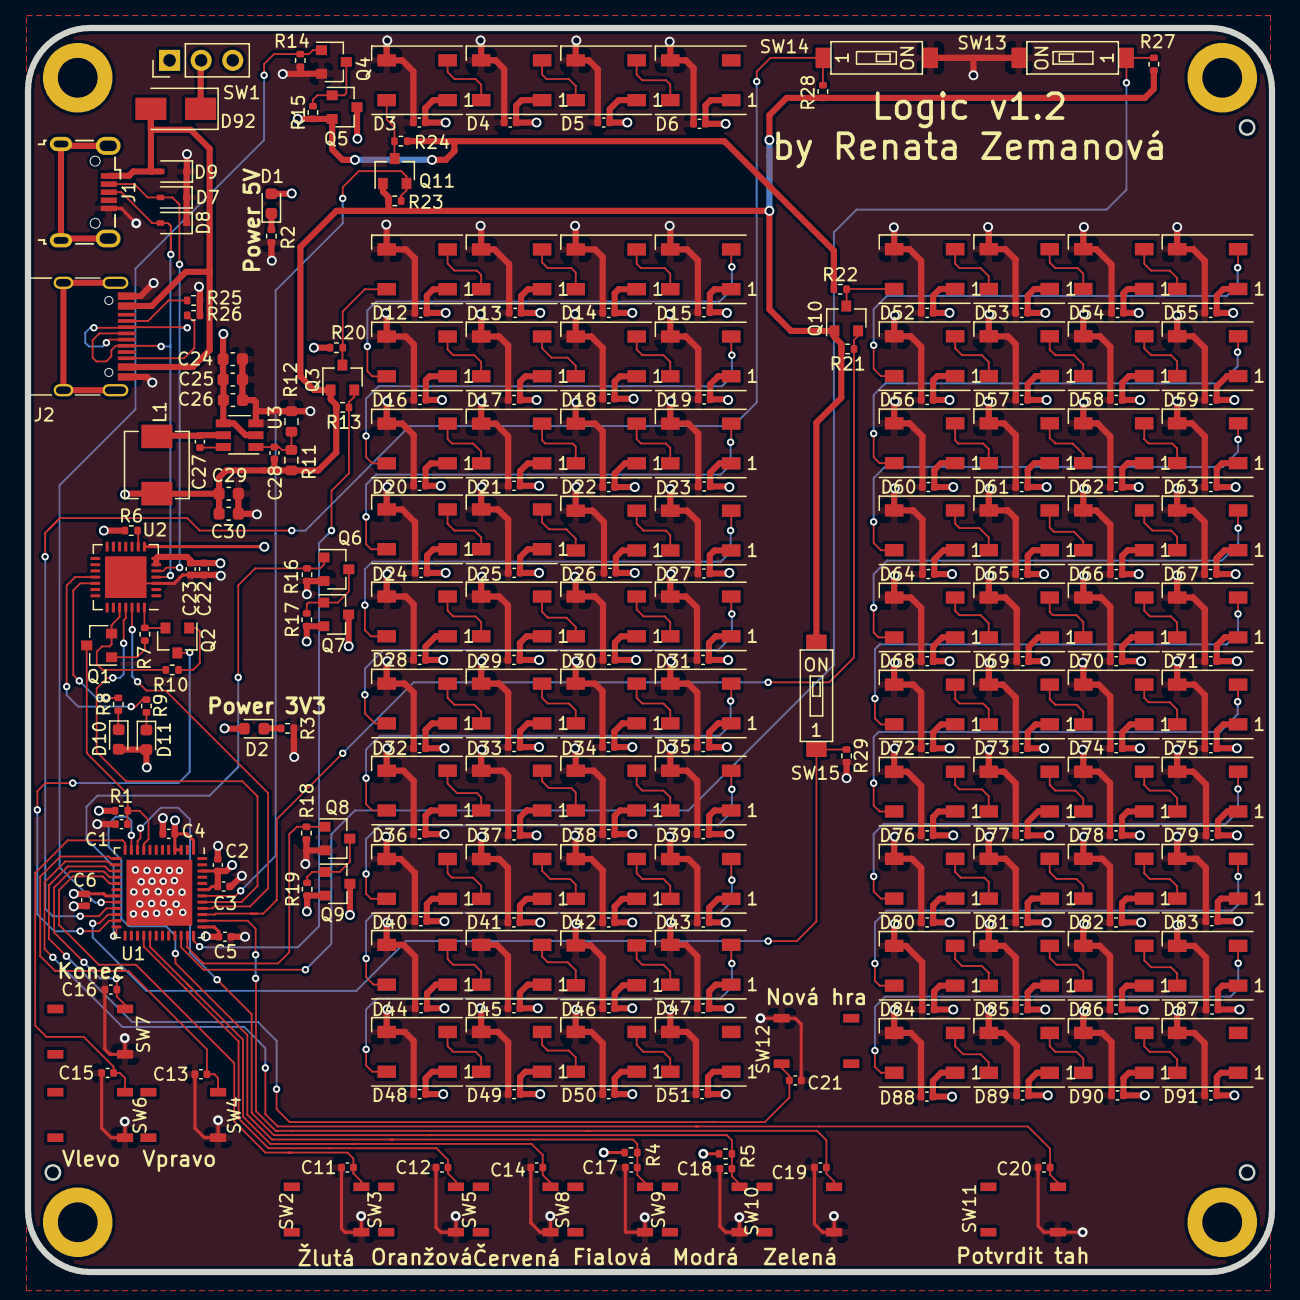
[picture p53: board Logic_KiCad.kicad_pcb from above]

Board: 4 copper layers, 100.0 x 100.0 mm, 267 parts (0 on the bottom side), 137 nets.

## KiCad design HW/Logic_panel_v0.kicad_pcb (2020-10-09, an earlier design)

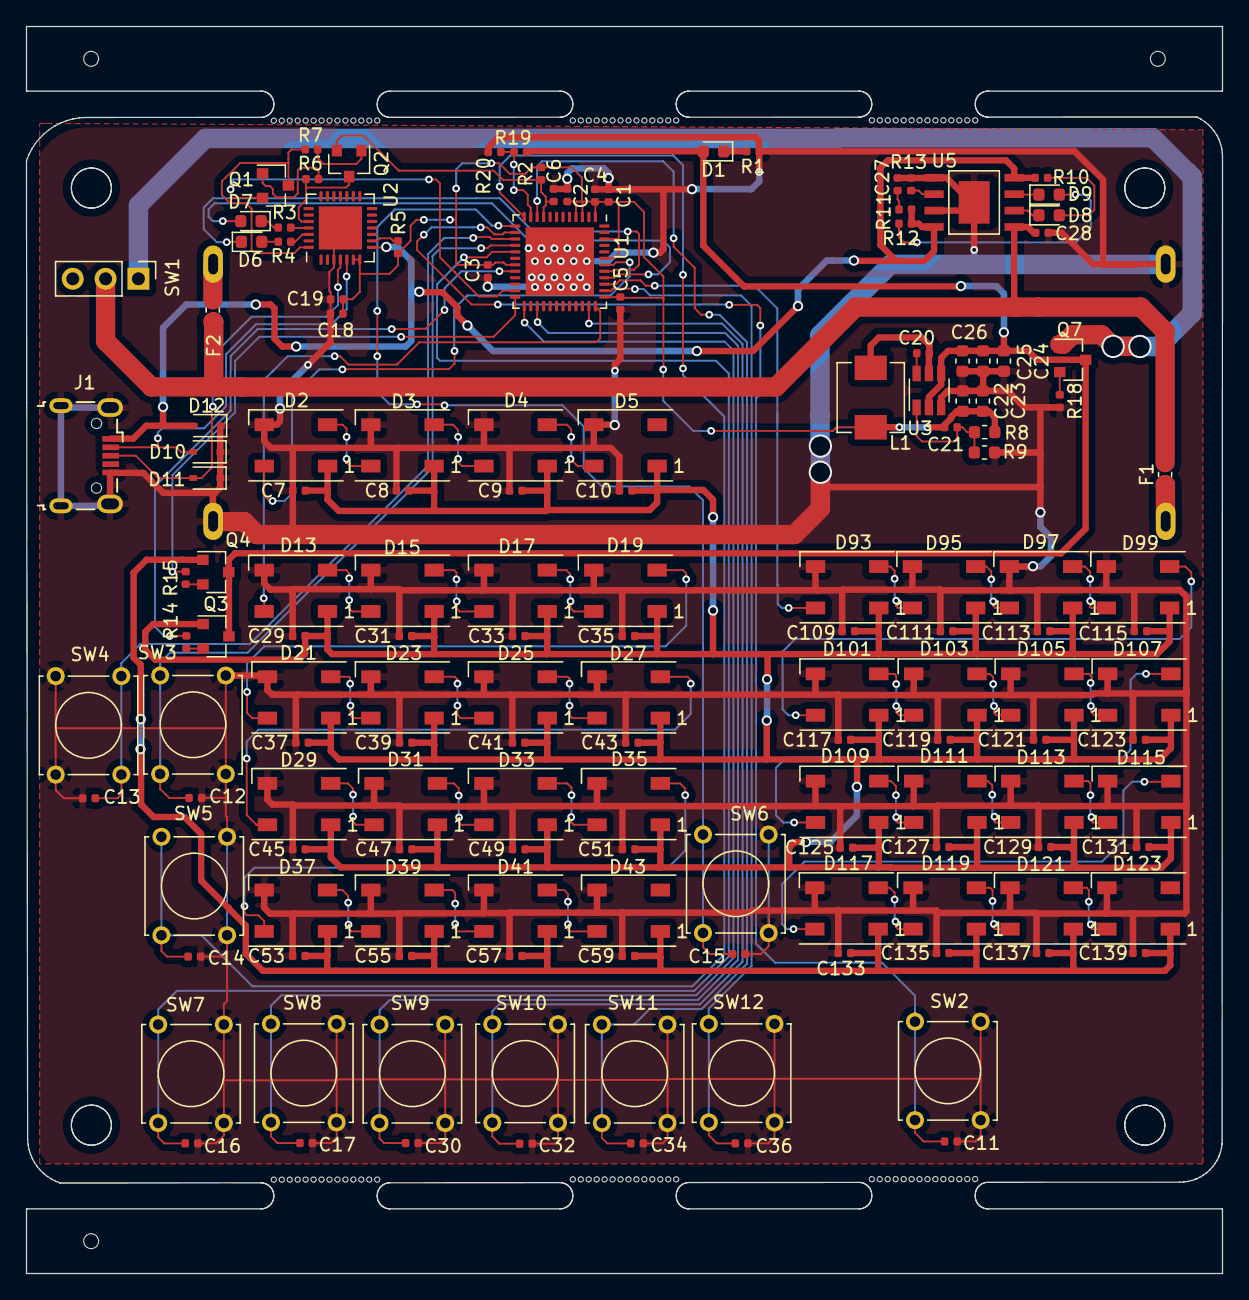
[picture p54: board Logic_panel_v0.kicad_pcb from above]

Board: 2 copper layers, 92.5 x 96.5 mm, 152 parts (1 on the bottom side), 88 nets.

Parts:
C1, C27, C28: 10u; C_0402_1005Metric
C2, C3, C4, C5, C6, C7, C8, C9, C10, C19, C20, C29, C31, C33, C35, C37, C39, C41, C43, C45, C47, C49, C51, C53, C55, C57, C59, C109, C111, C113, C115, C117, C119, C121, C123, C125, C127, C129, C131, C133, C135, C137, C139: 100n; C_0402_1005Metric
C11, C12, C13, C14, C15, C16, C17, C30, C32, C34, C36: 10n; C_0402_1005Metric
C18: 4u7; C_0402_1005Metric
C21: 47p; C_0402_1005Metric
C22, C23, C24, C25, C26: 22u; C_0603_1608Metric
D1, D6, D7, D8: green; LED_0603_1608Metric
D2, D3, D4, D5, D13, D15, D17, D19, D21, D23, D25, D27, D29, D31, D33, D35, D37, D39, D41, D43, D93, D95, D97, D99, D101, D103, D105, D107, D109, D111, D113, D115, D117, D119, D121, D123: WS2812B; LED_WS2812B_PLCC4_5.0x5.0mm_P3.2mm
D9: red; LED_0603_1608Metric
D10, D11, D12: SD05_SOD323; D_SOD-323
F1, F2: Polyfuse; Fuse_0603_1608Metric
J1: USB_B_Micro; USB_Micro-B_Wuerth_629105150521
L1: 4u7; MWSA0503S
Q1, Q2: Q_NPN_BCE; SOT-23
Q3, Q4, Q7: Q_PMOS_DGS; SOT-23
R1, R2, R6, R7, R14, R15, R18, R20: 10k; R_0402_1005Metric
R3, R4: 47k; R_0402_1005Metric
R5, R13: 2k; R_0402_1005Metric
R8: 160k; R_0603_1608Metric
R9: 36k; R_0603_1608Metric
R10, R12: 1k; R_0402_1005Metric
R11: 1; R_0402_1005Metric
R19: 39k; R_0402_1005Metric
SW1: SW_SPDT; PinHeader_1x03_P2.54mm_Vertical
SW2, SW3, SW4, SW5, SW6, SW7, SW8, SW9, SW10, SW11, SW12: button; SW_Tactile_Straight_KSL0Axx1LFTR
U1: ESP32-PICO-D4; QFN-48-1EP_7x7mm_P0.5mm_EP5.3x5.3mm
U2: CP2102N-A01-GQFN28; QFN-28-1EP_5x5mm_P0.5mm_EP3.35x3.35mm
U3: SY8105; TSOT-23-6
U4: Dual_battery; battery_dock
U5: TP4056

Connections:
Board_1-+3V3: C1.2, C2.1, C3.2, C4.1, C5.2, C18.2, C19.2, C21.2, C22.2, C23.2, L1.2, R2.1, R5.1, R8.1, U1.1, U1.3, U1.4, U1.19, U1.37, U1.43, U1.46, U2.6, U2.7
Board_1-/herni_LED.sch/2.sch/DATA_IN: D19.2, D21.4
Board_1-/herni_LED.sch/3.sch/DATA_IN: D27.2, D29.4
Board_1-/herni_LED.sch/4.ch/DATA_IN: D35.2, D37.4
Board_1-/hodnoceni_LED.sch/2.sch/DATA_IN: D99.2, D101.4
Board_1-/hodnoceni_LED.sch/3.sch/DATA_IN: D107.2, D109.4
Board_1-/hodnoceni_LED.sch/4.ch/DATA_IN: D115.2, D117.4
Board_1-BARVA_1: C16.2, SW7.1, U1.17
Board_1-BARVA_2: C17.2, SW8.1, U1.25
Board_1-BARVA_3: C30.2, SW9.1, U1.27
Board_1-BARVA_4: C32.2, SW10.1, U1.35
Board_1-BARVA_5: C34.2, SW11.1, U1.10
Board_1-BARVA_6: C36.2, SW12.1, U1.38
Board_1-BTN_END: C12.2, SW3.1, U1.16
Board_1-BTN_ENTER: C11.2, SW2.1, U1.14
Board_1-BTN_NEW_GAME: C13.2, SW4.1, U1.15
Board_1-BTN_SIPKA_VLEVO: C14.2, SW5.1, U1.12
Board_1-BTN_SIPKA_VPRAVO: C15.2, SW6.1, U1.13
Board_1-D+: D11.2, J1.3, U2.4
Board_1-D-: D10.2, J1.2, U2.5
Board_1-DATA_herni_LED: D13.4, U1.36
Board_1-DATA_hodnoceni_LED: D93.4, U1.39
Board_1-DATA_zadani_LED: D2.4, U1.42
Board_1-EN: C6.2, Q2.2, R2.2, U1.9
Board_1-GND: C1.1, C2.2, C3.1, C4.2, C5.1, C6.1, C7.2, C8.2, C9.2, C10.2, C11.1, C12.1, C13.1, C14.1, C15.1, C16.1, C17.1, C18.1, C19.1, C22.1, C23.1, C24.2, C25.2, C26.2, C27.2, C28.2, C29.2, C30.1, C31.2, C32.1, C33.2, C34.1, C35.2, C36.1, C37.2, C39.2, C41.2, C43.2, C45.2, C47.2, C49.2, C51.2, C53.2, C55.2, C57.2, C59.2, C109.2, C111.2, C113.2, C115.2, C117.2, C119.2, C121.2, C123.2, C125.2, C127.2, C129.2, C131.2, C133.2, C135.2, C137.2, C139.2, D2.3, D3.3, D4.3, D5.3, D10.1, D11.1, D12.1, D13.3, D15.3, D17.3, D19.3, D21.3, D23.3, D25.3, D27.3, D29.3, D31.3, D33.3, D35.3, D37.3, D39.3, D41.3, D43.3, D93.3, D95.3, D97.3, D99.3, D101.3, D103.3, D105.3, D107.3, D109.3, D111.3, D113.3, D115.3, D117.3, D119.3, D121.3, D123.3, J1.5, J1.6, R1.1, R9.2, R13.2, R18.2, R20.2, SW2.2, SW3.2, SW4.2, SW5.2, SW6.2, SW7.2, SW8.2, SW9.2, SW10.2, SW11.2, SW12.2, U1.49, U2.3, U2.29, U3.3, U4.2, U4.4, U5.1, U5.3, U5.9
Board_1-IO0: Q1.2, U1.23
Board_1-MERENI_BATERKY: R19.2, R20.1, U1.11
Board_1-Net-(C20-Pad1): C20.1, L1.1, U3.5
Board_1-Net-(C20-Pad2): C20.2, U3.6
Board_1-Net-(C21-Pad1): C21.1, R8.2, R9.1, U3.1
Board_1-Net-(C27-Pad1): C27.1, R11.2
Board_1-Net-(D1-Pad1): D1.1, R1.2
Board_1-Net-(D2-Pad2): D2.2, D3.4
Board_1-Net-(D3-Pad2): D3.2, D4.4
Board_1-Net-(D4-Pad2): D4.2, D5.4
Board_1-Net-(D6-Pad1): D6.1, R3.1
Board_1-Net-(D7-Pad2): D7.2, R4.1
Board_1-Net-(D8-Pad1): D8.1, U5.6
Board_1-Net-(D8-Pad2): D8.2, R10.1
Board_1-Net-(D9-Pad1): D9.1, U5.7
Board_1-Net-(D9-Pad2): D9.2, R12.1
Board_1-Net-(D13-Pad2): D13.2, D15.4
Board_1-Net-(D15-Pad2): D15.2, D17.4
Board_1-Net-(D17-Pad2): D17.2, D19.4
Board_1-Net-(D21-Pad2): D21.2, D23.4
Board_1-Net-(D23-Pad2): D23.2, D25.4
Board_1-Net-(D25-Pad2): D25.2, D27.4
Board_1-Net-(D29-Pad2): D29.2, D31.4
Board_1-Net-(D31-Pad2): D31.2, D33.4
Board_1-Net-(D33-Pad2): D33.2, D35.4
Board_1-Net-(D37-Pad2): D37.2, D39.4
Board_1-Net-(D39-Pad2): D39.2, D41.4
Board_1-Net-(D41-Pad2): D41.2, D43.4
Board_1-Net-(D93-Pad2): D93.2, D95.4
Board_1-Net-(D95-Pad2): D95.2, D97.4
Board_1-Net-(D97-Pad2): D97.2, D99.4
Board_1-Net-(D101-Pad2): D101.2, D103.4
Board_1-Net-(D103-Pad2): D103.2, D105.4
Board_1-Net-(D105-Pad2): D105.2, D107.4
Board_1-Net-(D109-Pad2): D109.2, D111.4
Board_1-Net-(D111-Pad2): D111.2, D113.4
Board_1-Net-(D113-Pad2): D113.2, D115.4
Board_1-Net-(D117-Pad2): D117.2, D119.4
Board_1-Net-(D119-Pad2): D119.2, D121.4
Board_1-Net-(D121-Pad2): D121.2, D123.4
Board_1-Net-(F1-Pad1): F1.1, U4.1
Board_1-Net-(F2-Pad1): F2.1, U4.3
Board_1-Net-(Q1-Pad1): Q1.1, R6.1
Board_1-Net-(Q1-Pad3): Q1.3, R7.2, U2.28
Board_1-Net-(Q2-Pad1): Q2.1, R7.1
Board_1-Net-(Q2-Pad3): Q2.3, R6.2, U2.24
Board_1-Net-(Q3-Pad2): Q3.2, R14.1
Board_1-Net-(Q4-Pad2): Q4.2, R15.1
Board_1-Net-(Q7-Pad2): Q7.2, R18.1
Board_1-Net-(R3-Pad2): R3.2, U2.25
Board_1-Net-(R4-Pad2): R4.2, U2.26
Board_1-Net-(R5-Pad2): R5.2, U2.9
Board_1-Net-(R13-Pad1): R13.1, U5.2
Board_1-RX_ESP: D6.2, U1.40
Board_1-TX_ESP: D7.1, U1.41
Board_1-VBUS: D12.2, J1.1, R10.2, R11.1, R12.2, U2.8, U5.4, U5.8
Board_1-V_BAT: C24.1, C25.1, C26.1, D1.2, Q3.3, Q4.3, Q7.3, R19.1, U3.2, U3.4
Board_1-V_BAT_1: C7.1, C8.1, C9.1, C10.1, C29.1, C31.1, C33.1, C35.1, C37.1, C39.1, C41.1, C43.1, C45.1, C47.1, C49.1, C51.1, C109.1, C111.1, C113.1, C115.1, C117.1, C119.1, C121.1, C123.1, C125.1, C127.1, C129.1, C131.1, D2.1, D3.1, D4.1, D5.1, D13.1, D15.1, D17.1, D19.1, D21.1, D23.1, D25.1, D27.1, D29.1, D31.1, D33.1, D35.1, D93.1, D95.1, D97.1, D99.1, D101.1, D103.1, D105.1, D107.1, D109.1, D111.1, D113.1, D115.1, Q3.1
Board_1-V_BAT_2: C53.1, C55.1, C57.1, C59.1, C133.1, C135.1, C137.1, C139.1, D37.1, D39.1, D41.1, D43.1, D117.1, D119.1, D121.1, D123.1, Q4.1
Board_1-V_BAT_PRIME: C28.1, F1.2, F2.2, SW1.2, U5.5
Board_1-V_BAT_SPINANE: Q7.1, SW1.1
Board_1-ZAPINANI_1_CAST_LED: R14.2, U1.20
Board_1-ZAPINANI_2_CAST_LED: R15.2, U1.24

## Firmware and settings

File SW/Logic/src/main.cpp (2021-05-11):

#include <Arduino.h>
#include <SmartLeds.h>
#include <Color.h>
#include <cstdlib>
#include <map>

#include "lib.h"

void setup() {
  _init_();

  led_t playing (LED_COUNT_GAME, LED_PIN_GAME, 2);
  led_t assignment (LED_COUNT_TASK, LED_PIN_TASK, 0);
  led_t evaluated (LED_COUNT_EVAL, LED_PIN_EVAL, 1);

  Colors playing_array[LINE_LENGTH * 10];
  Colors evaluated_array[LINE_LENGTH * 10];
  Colors task_array[LINE_LENGTH];

  clear_all_leds(playing, LED_COUNT_GAME, assignment, LED_COUNT_TASK, evaluated, LED_COUNT_EVAL);
  show_leds(playing, assignment, evaluated);
  wait_leds(playing, assignment, evaluated);
  set_led_pos_null(playing, assignment, evaluated);

  Colors task[LINE_LENGTH];
  int tog = 0;
  int num_of_black = 0;
  int num_of_white = 0;
  bool end = false;
  int count_enter = 0;

  int GAME_LINE_LENGTH;
  int DIFF;
  bool GAME_FOR_2_PLAYERS;

  wait_for_btn_press(SW_NEW_GAME);

  while(true){  
    if(is_pressed(SW_NEW_GAME)){
      wait_for_btn_release(SW_NEW_GAME);
      DIFF = 3; 
      GAME_LINE_LENGTH = 4;
      GAME_FOR_2_PLAYERS = is_game_for_2_players();
      
      if(is_game_with_space())
        DIFF = 2;
      if(is_game_on_3_colors())
        GAME_LINE_LENGTH = 3;
      clear_all_leds(playing, LED_COUNT_GAME, assignment, LED_COUNT_TASK, evaluated, LED_COUNT_EVAL);
      wait_leds(playing, evaluated, assignment);
      show_leds(playing, evaluated, assignment);
      wait_leds(playing, evaluated, assignment);
      if(!GAME_FOR_2_PLAYERS){
        generate_task(task, GAME_LINE_LENGTH, DIFF);
        set_task(assignment, task, GAME_LINE_LENGTH);
      }
      if(GAME_FOR_2_PLAYERS){
        clear_array(task_array, LINE_LENGTH);
        clear_array(evaluated_array, LINE_LENGTH * 10);
        set_led_pos_null(evaluated, assignment);
        count_enter = 0;
      }
      clear_array(playing_array, LINE_LENGTH * 10);
      playing.pos = 0;
      end = false; 
      set_power_leds(playing.pos, POWER_OFF);
      set_power_leds(playing.pos, POWER_ON);
    }

    if(is_pressed(SW_YELLOW)){
      wait_for_btn_release(SW_YELLOW);
      if(count_enter == 0 && GAME_FOR_2_PLAYERS)
        set_color_and_go_right(YELLOW, task_array, assignment, GAME_LINE_LENGTH);
      else if((is_odd(count_enter) && GAME_FOR_2_PLAYERS) || !GAME_FOR_2_PLAYERS)
        set_color_and_go_right(YELLOW, playing_array, playing, GAME_LINE_LENGTH);
      else if(GAME_FOR_2_PLAYERS)
        set_color_and_go_right(YELLOW, evaluated_array, evaluated, GAME_LINE_LENGTH); 
    }

    else if(is_pressed(SW_ORANGE)){
      wait_for_btn_release(SW_ORANGE);
      if(count_enter == 0 && GAME_FOR_2_PLAYERS)
        set_color_and_go_right(ORANGE, task_array, assignment, GAME_LINE_LENGTH);
      else if((is_odd(count_enter) && GAME_FOR_2_PLAYERS) || !GAME_FOR_2_PLAYERS)
        set_color_and_go_right(ORANGE, playing_array, playing, GAME_LINE_LENGTH);
    }

    else if(is_pressed(SW_RED)){
      wait_for_btn_release(SW_RED);
      if(count_enter == 0 && GAME_FOR_2_PLAYERS)
        set_color_and_go_right(RED, task_array, assignment, GAME_LINE_LENGTH);
      else if((is_odd(count_enter) && GAME_FOR_2_PLAYERS) || !GAME_FOR_2_PLAYERS)
        set_color_and_go_right(RED, playing_array, playing, GAME_LINE_LENGTH);
      else if(GAME_FOR_2_PLAYERS)
        set_color_and_go_right(RED, evaluated_array, evaluated, GAME_LINE_LENGTH);
    }

    else if(is_pressed(SW_PURPLE)){
      wait_for_btn_release(SW_PURPLE);
      if(count_enter == 0 && GAME_FOR_2_PLAYERS)
        set_color_and_go_right(PURPLE, task_array, assignment, GAME_LINE_LENGTH);
      else if((is_odd(count_enter) && GAME_FOR_2_PLAYERS) || !GAME_FOR_2_PLAYERS){
        set_color_and_go_right(PURPLE, playing_array, playing, GAME_LINE_LENGTH);
      }
    }

    else if(is_pressed(SW_BLUE)){
      wait_for_btn_release(SW_BLUE);
      if(count_enter == 0 && GAME_FOR_2_PLAYERS)
        set_color_and_go_right(BLUE, task_array, assignment, GAME_LINE_LENGTH);
      else if((is_odd(count_enter) && GAME_FOR_2_PLAYERS) || !GAME_FOR_2_PLAYERS)
        set_color_and_go_right(BLUE, playing_array, playing, GAME_LINE_LENGTH);
    }

    else if(is_pressed(SW_GREEN)){
      wait_for_btn_release(SW_GREEN);
      if(count_enter == 0 && GAME_FOR_2_PLAYERS)
        set_color_and_go_right(GREEN, task_array, assignment, GAME_LINE_LENGTH);
      else if((is_odd(count_enter) && GAME_FOR_2_PLAYERS) || !GAME_FOR_2_PLAYERS)
        set_color_and_go_right(GREEN, playing_array, playing, GAME_LINE_LENGTH);
    }

    else if(is_pressed(SW_LEFT)){
      wait_for_btn_release(SW_LEFT);
      if(count_enter == 0 && GAME_FOR_2_PLAYERS)
        save_col_and_arrow(LEFT, task_array, assignment, GAME_LINE_LENGTH);
      else if((is_odd(count_enter) && GAME_FOR_2_PLAYERS) || !GAME_FOR_2_PLAYERS)
        save_col_and_arrow(LEFT, playing_array, playing, GAME_LINE_LENGTH);
      else if(GAME_FOR_2_PLAYERS)
        save_col_and_arrow(LEFT, evaluated_array, evaluated, GAME_LINE_LENGTH);
    } 

    else if(is_pressed(SW_RIGHT)){
      wait_for_btn_release(SW_RIGHT);
      if(count_enter == 0 && GAME_FOR_2_PLAYERS)
        save_col_and_arrow(RIGHT, task_array, assignment, GAME_LINE_LENGTH);
      else if((is_odd(count_enter) && GAME_FOR_2_PLAYERS) || !GAME_FOR_2_PLAYERS)
        save_col_and_arrow(RIGHT, playing_array, playing, GAME_LINE_LENGTH);
      else if(GAME_FOR_2_PLAYERS)
        save_col_and_arrow(RIGHT, evaluated_array, evaluated, GAME_LINE_LENGTH);
    } 

    else if(is_pressed(SW_ENTER)){
      wait_for_btn_release(SW_ENTER);
      if(count_enter == 0 && GAME_FOR_2_PLAYERS)
        set_last_color(task_array, assignment);
      else if((is_odd(count_enter) && GAME_FOR_2_PLAYERS) || !GAME_FOR_2_PLAYERS)
        set_last_color(playing_array, playing);
      else if(GAME_FOR_2_PLAYERS)
        set_last_color(evaluated_array, evaluated);

      if(!GAME_FOR_2_PLAYERS){  
        evaluate(playing.pos, playing_array, task, &num_of_black, &num_of_white, GAME_LINE_LENGTH);
        set_evaluated_black(num_of_black, evaluated, GAME_LINE_LENGTH);

        if(num_of_black == GAME_LINE_LENGTH){
          wait_leds(playing, assignment, evaluated);
          show_leds(playing, assignment, evaluated);

          wait_for_btns_press(SW_NEW_GAME, SW_END);
          continue;
        }
        set_evaluated_white(num_of_black, num_of_white, evaluated);

        if(is_end(playing.pos)){
          wait_leds(assignment, evaluated);
          show_leds(assignment, evaluated);

          wait_for_btns_press(SW_NEW_GAME, SW_END);
          continue;
        }
      }

      if(GAME_FOR_2_PLAYERS)
        ++count_enter;
        
      if((((count_enter != 1) && is_odd(count_enter)) && GAME_FOR_2_PLAYERS) || !GAME_FOR_2_PLAYERS){
        new_line(playing);
        new_line(evaluated);
      }
      set_power_leds(playing.pos, POWER_ON);
    }

    else if(is_pressed(SW_END)){
      wait_for_btn_release(SW_END);
      
      clear_all_leds(playing, LED_COUNT_GAME, assignment, LED_COUNT_TASK, evaluated, LED_COUNT_EVAL);
      wait_leds(playing, assignment, evaluated);
      show_leds(playing, assignment, evaluated);
      end = true;
      count_enter = 0;
      set_power_leds(playing.pos, POWER_OFF);
      wait_for_btn_press(SW_NEW_GAME);
    }  

     ++tog;
    if(tog == 3)
      tog = 0;

    if(!end && (tog == 0 || tog == 2)){ 
      if(count_enter == 0 && GAME_FOR_2_PLAYERS)
        toggle_cursor(assignment, task_array[assignment.pos], tog);
      else if((is_odd(count_enter) && GAME_FOR_2_PLAYERS) || !GAME_FOR_2_PLAYERS)
        toggle_cursor(playing, playing_array[playing.pos], tog);
      else if(GAME_FOR_2_PLAYERS)
        toggle_cursor(evaluated, evaluated_array[evaluated.pos], tog);
    }

    wait_leds(playing, assignment, evaluated);
    show_leds(playing, evaluated);
    if(GAME_FOR_2_PLAYERS)
      assignment.leds.show();

    delay(200);
  } 
  
}

void loop() {}

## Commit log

2020-09-28 PCB: game controls, USB to 232, stepdown for ESP, battery pack
    [Battery_pack.sch, Logic_KiCad.kicad_pcb, Logic_KiCad.sch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]
2020-09-28 add charger
    [Logic_KiCad.sch]
2020-09-30 add power supply for ESP, erase resistors by buttons, add power supply for CP2102, add communication control (CP2102-ESP)
    [Battery_pack.sch, Logic_KiCad.sch, Stepdown_ESP.sch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]
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2020-09-30 changed switching power supply for LEDs
    [Battery_pack.sch, Logic_KiCad.sch, Stepdown_ESP.sch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]
2020-09-30 change structure of LEDs, add switching power supply of LEDs in parts
    [Battery_pack.sch, LEDky4.sch, LEDky40.sch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]
2020-09-30 remove pin from USB
    [Logic_KiCad.sch, USB.sch, USBto232.sch]
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2020-10-01 add polyfuse for battery, remove resistor by SY8105, fix mistake by charger
    [Battery_pack.sch, Logic_KiCad.sch, Stepdown_ESP.sch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]
2020-10-01 add reverse polarity protection
    [Battery_pack.sch, LEDky4.sch, LEDky40.sch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]
2020-10-01 add capacitor to power of ESP
    [Logic_KiCad.sch]
2020-10-01 add measurement voltage on batteries
    [Battery_pack.sch, LEDky4.sch, LEDky40.sch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]
2020-10-01 fix mistake
    [Logic_KiCad.sch, mereni_baterky.sch]
2020-10-02 new battery pack schematic
    [Battery_pack.sch]
2020-10-02 add some codes for JLCPCB, change package and schematic of CP2102
    [LEDky4.sch, Logic_KiCad.sch, Stepdown_ESP.sch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]
2020-10-02 add some codes for JLCPCB
    [LEDky4.sch, Logic_KiCad.sch, USBto232.sch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]
2020-10-03 add footprint of battery pack
    [Battery_pack.sch]
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2020-10-03 add footprint of inductor, add codes for JLCPCB, repair mistakes
    [Battery_pack.sch, Logic_KiCad.sch, Stepdown_ESP.sch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]
2020-10-04 numbering components, place components on board
    [Battery_pack.sch, LEDky4.sch, LEDky40.sch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]
2020-10-04 new position of some components
    [Logic_KiCad.kicad_pcb]
2020-10-04 repair package of TP4056
    [LEDky4.sch, Logic_KiCad.kicad_pcb, nabijecka.sch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]
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2020-10-05 repair mistake with buttons
    [LEDky4.sch, LEDky40.sch, Logic_KiCad.kicad_pcb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]
2020-10-05 rotate LEDs and capacitors
    [Logic_KiCad.kicad_pcb]
2020-10-05 make smaller test version, start routing
    [Battery_pack.sch, LEDky4.sch, LEDky40.sch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]
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2020-10-06 finishing routing, make fab
    [Logic_KiCad - kopie.kicad_pcb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]
2020-10-08 ready for first prototype
    [Logic_KiCad - kopie.kicad_pcb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]
2020-10-09 add mounting holes, repair gitignore
    [Logic_KiCad.kicad_pcb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]
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2020-10-21 change structure of buttons, switching power
    [Battery_pack.sch, LEDky4.sch, LEDky40.sch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]
2020-11-05 start writing test, update gitignore
    [LEDky4.sch, Logic_KiCad.kicad_pcb, Stepdown_ESP.sch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]
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2020-11-12 repair some misakes from prototype
    [Battery_pack.sch, Logic_KiCad.kicad_pcb, Logic_KiCad.sch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]
2020-11-12 add version and author
    [Logic_KiCad.kicad_pcb]
2020-11-15 repair mistake with tranzistors, repair programming ESP PICO
    [Logic_KiCad.kicad_pcb, Logic_KiCad.sch, zapinani_LEDek.sch]
2020-11-15 deposit of DPS, start v1.0
    [Battery_pack.sch, LEDky4.sch, LEDky40.sch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]
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2020-11-16 change footprint of buttons, continue placing components, repair mistake in power voltage
    [Logic_KiCad.kicad_pcb, Logic_KiCad.sch, Logic_KiCad_v0.kicad_pcb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]
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2020-11-18 add rounded corners PCB, place mounting holes
    [Logic_KiCad.kicad_pcb]
2020-11-18 repair footprint of P and N MOS, add order codes for JLCPCB, preparing for fab
    [LEDky4.sch, Logic_KiCad.kicad_pcb, Logic_KiCad.sch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]
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2020-11-21 repair mistakes
    [LEDky4.sch, Logic_KiCad.kicad_pcb, Logic_KiCad.sch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]
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2020-11-23 add back-up v1.0 for fab
    [LEDky4.sch, LEDky40.sch, Logic_KiCad.kicad_pcb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]
2020-11-23 repair mistake in v1.0 - for fab, add to back-up v1.0 folder fab
    [Logic_KiCad.kicad_pcb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]
2020-11-23 v1.0 for fab (for great success once again)
    [Logic_KiCad.kicad_pcb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]
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2021-01-06 repair WS2812B na WS2812C
    [LEDky4.sch, LEDky40.sch, zadani_LED.sch]
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2021-01-24 V1.1 change SMD buttons, add diode on VCC
    [LEDky4.sch, Logic_KiCad.kicad_pcb, Logic_KiCad.sch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]
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2021-01-27 deposti v1.1 (repair mistake)
    [tlacitko.sch]
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2021-03-15 repair footprint of DIP and USB micro, change buttons with higher fretboard
    [LEDky4.sch, LEDky40.sch, Logic_KiCad.kicad_pcb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]
2021-03-15 change USB footprint, add 3. DIP
    [LEDky4.sch, Logic_KiCad.kicad_pcb, Logic_KiCad.sch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]
2021-03-16 repair DIPs, add pullup and pulldown resistors
    [Logic_KiCad.kicad_pcb, Logic_KiCad.sch]
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2021-03-23 move mounting holes, move power LED 3V3
    [Logic_KiCad-CmtUser.gbr, Logic_KiCad-CuBottom.gbr, Logic_KiCad-CuTop.gbr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]
2021-03-24 update rotation of components for fab, update folder fab
    [LEDky4.sch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]
2021-03-30 Version 1.2 for fab
    [Logic_KiCad-CmtUser.gbr, Logic_KiCad-CuBottom.gbr, Logic_KiCad-CuTop.gbr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]
2021-04-07 make code readeble, add delete colors, repair mistake with press btn end and position of cursors
    [main.cpp]
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2021-04-19 save everything for work
    [novy_spodni.STL, novy_vrchni.STL, strecha.STL]
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2021-04-28 make schematic beautiful (for printing)
    [LEDky4.sch, LEDky40.sch, Logic_KiCad.sch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]
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2021-05-05 repair top of box
    [celek.SLDASM, novy_vrchni.SLDPRT, novy_vrchni.STL]
2021-05-07 repair roof, add hole for switch
    [novy_spodni.SLDPRT, novy_spodni.STL, novy_vrchni.SLDPRT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]
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2021-05-10 repair mistakes with power supply switching
    [main.cpp]
2021-05-10 sides of roof are wider, bigger hole for nut, add elevation for roof
    [celek.SLDASM, novy_spodni.SLDPRT, novy_spodni.STL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]
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2021-05-11 make hole for buttons bigger, add texts, make hole for USB connectors bigger
    [celek.SLDASM, novy_spodni.SLDPRT, novy_spodni.STL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]
2021-05-11 repair mistake with cursor in evaluate
    [main.cpp]
2021-05-13 repair texts on box
    [celek.SLDASM, novy_vrchni.SLDPRT, novy_vrchni.STL]
2021-05-13 repair texts on box (bigger space)
    [celek.SLDASM, novy_vrchni.SLDPRT, novy_vrchni.STL]
2021-05-18 repair board for printing
    [Logic_KiCad.kicad_pcb]
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2021-05-18 new support of PCB
    [celek.SLDASM, novy_spodni.SLDPRT, novy_spodni.STL]
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2021-05-21 repair box for SLA 3D printing, add colors
    [celek.SLDASM, novy_spodni.SLDPRT, novy_spodni.STL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]
2021-05-26 repair hole for power switch
    [celek.SLDASM, novy_spodni.SLDPRT, novy_spodni.STL]
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2021-05-28 generate new STL for final printing box
    [novy_spodni.STL, novy_vrchni.STL]
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2021-07-07 new version of box
    [1hrac.SLDPRT, 1hrac.STL, 2hraci.SLDPRT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]
